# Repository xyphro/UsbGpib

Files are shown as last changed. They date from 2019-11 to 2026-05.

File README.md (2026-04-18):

# Table of contents

:newspaper: [Latest updates](Updates.md)
<br> :hammer: [Buy it or build it](#buy-it-or-build-it)
<br> :wave: [UsbGpib Introduction](#usbgpib-introduction)
<br> :house: [Housing / Enclosure](#housings)
<br> :computer: [Software](#software)
<br> &nbsp; &nbsp; :electric_plug: [Using the device](#using-the-device)
<br> &nbsp; &nbsp; :gear: [Setting and getting parameters](#setting-parameters)
<br> :heavy_check_mark: [Testing status](#testing-status)
<br> :notebook: [Tutorials](Tutorials/README.md) <- **New!**
<br> :heart: [Support the Project](#support-the-project)

# Summarized latest updates

For detailed visibility look under the Latest update link above!

[18th Apr 2026]: **Released Firmware V2.4: Added support for multiple GPIB devices**

[18th Apr 2026]: **Added some updated notes on GPIBee**

[07th Mar 2026]: **USbGpib V2 back in Stock on Elecrow**  

[07th Mar 2026]: **10 UsbGpib V3 == GPIBee prototypes ready for testing**

# Next version update USBGpib V3 

**UsbGpib V3 has a Name - Introducing GPIBee**

...and as you’ll see in the picture: The beauties are ready!

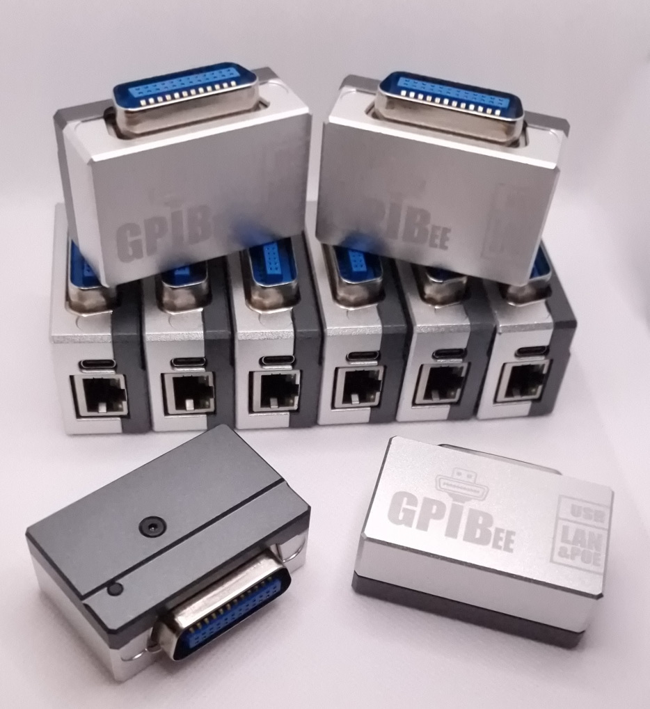
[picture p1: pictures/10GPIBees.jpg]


After months of development, redesigns, loosing hair on fixing SW bugs and teasing the new Ethernet + PoE capabilities, the next generation of UsbGpib finally has its official identity. From this point forward, UsbGpib V3 will be known as GPIBee - a compact, fast, and delightfully capable little worker that's ready to buzz around your lab equipment.

PoE is fully operational, VXI-11 supports multiple simultaneous connections, and USB High-Speed is performing flawlessly - on MY bench. Which does not mean (yet) on everybody elses bench. Testing is by multiple people is always very important!

I now have ten GPIBee prototypes fully assembled and sitting proudly on my desk. These units will soon head out to the first wave of beta testers who’ve been following the journey and are eager to put them through real‑world use.
I had hoped to start shipping next week, but with Embedded World taking up my entire schedule, distribution will begin shortly after I'm back. The excitement doesn't slow down - it just builds a little more.

Thank you all for the incredible support, feedback, and enthusiasm.

GPIBee is about to take its first flight, and you're part of the swarm that made it possible.
Stay tuned - beta testing starts soon, and the prototypes look fantastic.

## GPIBee update 18th April: 

The first prototypes have been shipped, and internal testing is already well advanced.  
Across all protocols, read performance shows a **3.5× to 5× speed increase**, and this is **without** any dedicated speed-optimization work applied yet.

## Communication Modes

### USB Interface

GPIBee supports three independent USB-based communication modes:

1. **Network mode**  
   GPIBee exposes a USB-based Ethernet interface. An IP address is assigned automatically, enabling true plug-and-play operation.  
   - Full **VXI-11** support  
   - Integrated **web server** providing configuration pages, a GPIB command console, and the complete manual matching the currently installed firmware  
   - Ideal for multi-device setups and remote control - it should be considered as the first Goto solution in terms of USB based modes.

2. **USBTMC mode**  
   Similar to **UsbGpib V2**, but extended with additional commands, including the ability to set the target **GPIB device address** — enabling communication with multiple GPIB instruments.

3. **++ protocol mode**  
   Exposes a **USB CDC UART** implementing the popular ++ protocol, compatible with existing controllers using that protocol — but at significantly higher speed.

The USB modes are **mutually exclusive**. The active mode can be selected via the **web interface** or through internal **SCPI commands**.

### Ethernet Interface

1. **VXI-11**  
   Provides multiple logical channels, allowing communication with several GPIB devices simultaneously without manually switching addresses between commands. 
   - Proper **lock handling** for multi-client access  
   - Full **SRQ** support  
   - Full **GPIB subaddressing** support

2. **++ protocol**  
   Optional **TCP/IP** service on port **1234**, offering the same `++` protocol implementation as in USB CDC UART mode.

Both Ethernet protocols can be **active at the same time**. The Ethernet interface also exposes the same **web interface** as USB network mode, enabling GPIB transfers, configuration changes, and access to the **firmware-synchronized manual**.

## GPIBee Beta Testing Status

The current beta focus remains on **functional correctness and stability**.  
**Speed optimization** will follow next.

For testers not having received an adapter yet: Additional prototype units will be shipped soon. Handling too many testers at once would otherwise become too **time-intensive**.

---

# Buy it or build it

* Tired of tinkering? Want to skip the hassle and get straight to using your GPIB setup?  
* You’d rather spend your time using your instruments instead of assembling hardware?

Skip the soldering iron and jump straight into your GPIB workflow!

You’ve got two solid options to get a ready‑to‑run UsbGpib adapter.

## &#x1f1fa;&#x1f1f8; - United States
* If you're in the US, you can now order the UsbGpibV2 directly from several sources, including my distribution partner Binho LLC. Enjoy fast domestic shipping with no long waits, no customs paperwork, and no surprises - just quick delivery and a smooth experience: 
<br> &#x1F449; <a href="https://binho.io/test-measurement/products/usbgpib-v2/" target="_blank">https://binho.io/test-measurement/products/usbgpib-v2/</a>
<br> &#x1F449; <a href="https://www.digikey.com/short/29nqq5cz" target="_blank"> https://www.digikey.com/short/29nqq5cz</a>
<br> &#x1F449; Amazon US also has it listed, but right now no stock, but worthwhile to check it out there too.

## &#x1F30E; - Worldwide
* I’ve teamed up with Elecrow to bring you ready-to-roll GPIB-USB converters – perfect for those who want results, not a weekend project.
* These adapters come fully assembled, programmed, housed, tested, and ready to go. No fuss. No build. Just plug it in and start working.
* The Adapters match 100% the V2 version described in this repository. 
* &#x1F449; <a href="https://www.elecrow.com/xyphrolabs-gpibusb.html" target="_blank">https://www.elecrow.com/xyphrolabs-gpibusb.html</a>

Let the data flow begin!

This doesn’t mean I’m going fully commercial - far from it.
Offering pre-built adapters is simply a convenience for those who’d rather skip the build and get straight to using their gear.

All sharing, support, and collaboration will remain fully open, just as before.
This is about choice, not change!

The full design files are located in this repository in case you want to build the devices yourself.

---

# UsbGpib Introduction
Versatile, cheap, portable and robust USB to GPIB converter (USBTMC class based).

You'll find many projects like this, but this one is special (ok, everybody will claim this) :-)

V1 Hardware: 
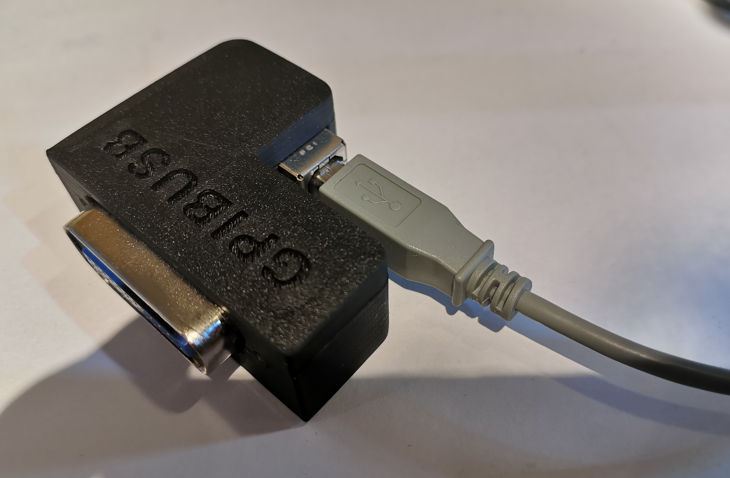
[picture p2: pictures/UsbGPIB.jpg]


V2 Hardware: 


If you have a lot of test equipment at home, you might know the issues: Lots of devices only have GPIB as interface and the GPIB adapters and GPIB cables on the market are very expensive and some of them even have many issues, when run under Windows 10 (device driver does not work). Or they e.g. are not able to be operated with VISA, because they are UART based, need special command sequences, ...

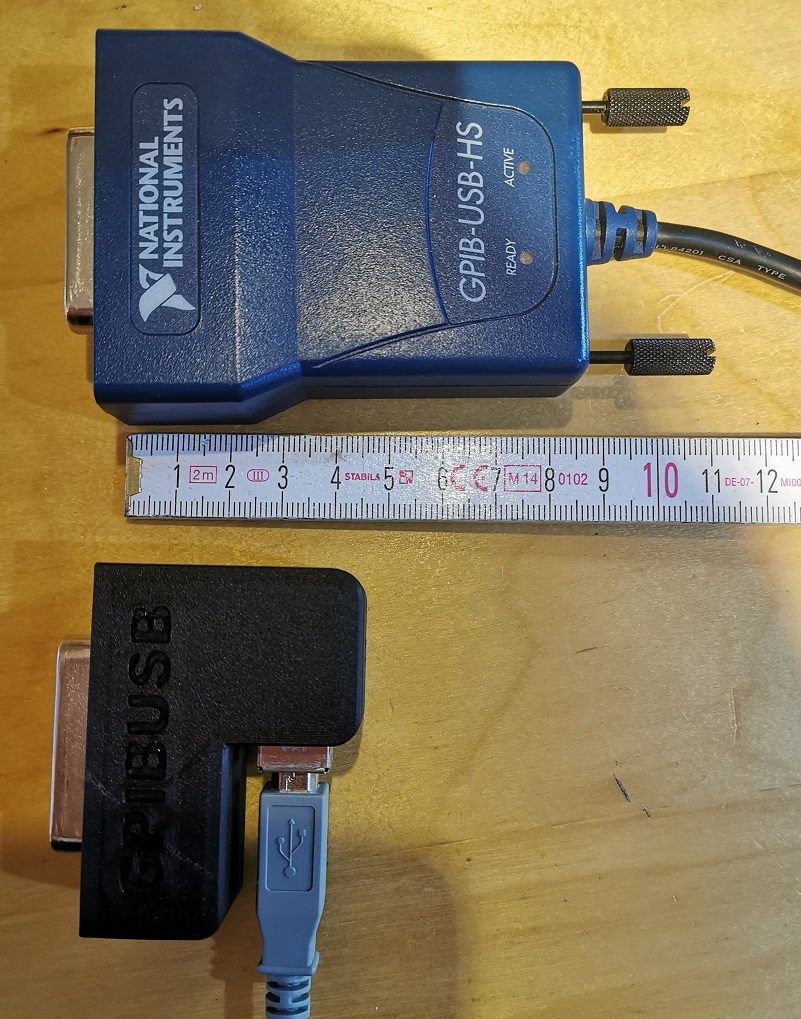
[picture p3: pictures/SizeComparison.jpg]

The adapters are also typically very long, such that they extend the overall length of your test equipment by at least 10cm (~4 inches).

Apart of the 2 very big manufacturers, other GPIB adapters, e.g. with Ethernet or also USB interface are not recognized by normal VISA providers or PyVisa, making the measurement control implementation specific for your GPIB adapter.

I've got frustrated and tried to turn it into something positive. Here a video showing the final device in action - click to view:

(https://www.youtube.com/watch?v=pZp1QZCXrF8) 

Some goals of the project were:
- Work based on the standard USBTMC protocol. This allows the GPIB test equipment to look like a normal USB based measurement device and work flawless with e.g. NI VISA, Labview, Matlab or PyVisa.
- Have a small length - otherwise my equipment has the risk of falling from the shelf :-) Also the USB cable should connect 90 degree angled, to make it very short. With V2 HW, the length got further reduced to the size of a GPIB connector.
- It should be cheap but still versatile (you can build a single one of these for only 14 USD!)
- It should support ALL my test equipment, from many different GPIB implementation generations and different GPIB flavors
- The Firmware should be upgradeable over USB
- It should be rock-solid (!) I don't want to end up in a very long measurement being interrupted because of a software issue of my USB GPIB converter.
- It should support additional features like serial poll, remote enabling/disabling
- If there is no GPIB device connected to the USBGpib converter, or the GPIB device is powered down, there should be no USB device visible on the PC.

All those goals are met.

---

# Hardware

## Microcontroller choice

Although I typically would prefer nowadays an ARM Cortex M0/3/4/7 controller, there is an issue with it. Available devices support only max. 3.3V supply voltages, such that there would be a requirement for a level-shifter towards the GPIB Bus.
GPIB is based on 5V (not exactly true, but a first iteration).

This limited the microcontroller choice to e.g. AVR or PIC controllers. Because of very good availability I ended up in ATMEGA32U4 controllers.
Apart of the device supporting 5V I/O voltages, it also does not require a regulator to be part of the application - it has an internal 3.3V regulator. This minimizes the full application schematic and BOM.

Apart from that, there is an excellent USB stack available [http://www.fourwalledcubicle.com/LUFA.php](http://www.fourwalledcubicle.com/LUFA.php).

The GPIB side of the schematic can be directly connected to the ATMega32U4 IO pins. The IO pins from the microcontroller side are only set to 2 different states: Tri-state (input) or output LOW, to talk over GPIB.

## Component sourcing

All components are easy to source, so I only specify the potential critical ones:

- 16 MHz Crystal: Farnell 2853867 - MCSJK-7E-16.00-8-30-100-B-30 
- REV 1 GPIB connector: Farnell 2421095 - NORCOMP 112-024-113R001. For REV 2 use a straight 24P male solder type connector e.g. from AliExpress.
- USB connector for V1 HW: Farnell 2668483 - Amphenol ICC 61729-1011BLF
- USB connector for V2 HW: Best is to look on AliExpress for 57 series 24P connector as a starting point.

## PCB

The PCB can be ordered at nearly any PCB pool production service (e.g. 10 PCBs for 2 USD + shipping). The gerber files are included in the "HW/Gerber files" subdirectory.

## Mounting the PCB & Flashing the firmware

The PCB is available in 2 revisions.
- [REV 1](HW/REV1/README.md) is the most popularly used right now due to age. It has a USB Type-B connector and an L-shaped housing visible on a few photos of this page.
- [REV 2](HW/REV2/README.md) has some improvements like being smaller, better fit and USB Type-C connector.
- A REV 3 is upcoming. It will be a major redesign with more speed, Ethernet and power over Ethernet support, but the same DNA: Standard protocols being used and ensure compatibility and stability!

Choose whatever you prefer. The software images, but also the external behavior is the same.

---

# Housings

## REV 1
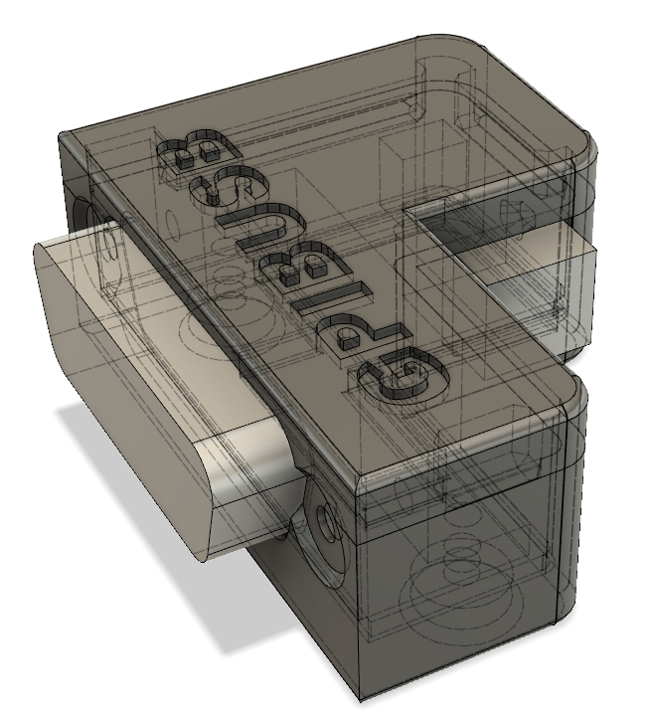
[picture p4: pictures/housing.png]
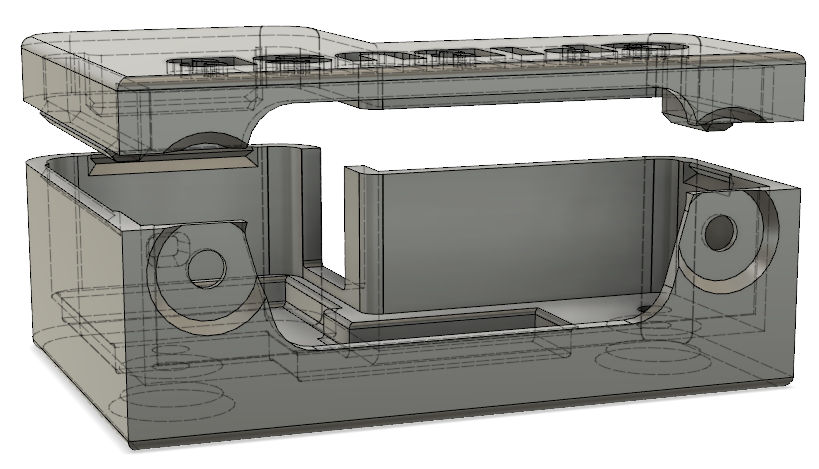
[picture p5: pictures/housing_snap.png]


I created a sophisticated 3D printable housing for this adapter. The design was made with Fusion 360. The project file + the STL files are included in the "Housing" sub directory.

The PCB fits perfectly into it. Optionally it can be fixed with 2 mounting screws (the GPIB connector has 2 threads, use 2 times 4-40 UNC x 3/8) and the TOP cover snaps onto the housing base.

I printed this using an Ender 5 3D printer with black PLA, 0.15mm layer height, 1mm wall thickness, no support.
Take care, that you rotate the TOP part of the housing by 180 degrees, so that the flat side is located on the printer bed.
Printing works fine, several iterations of the design were made to ensure good printability.
I printed so far 15 housings, without a single fail.

More information on this REV 1 can be found here: [REV 1](HW/REV1/README.md).
Note, that also the programming/build instructions moved to this location.

## REV 2



The REV 2 housing is a lot smaller, but requires 2 screws.
The housing is quite important to be able to connect and disconnect the board without breaking anything. It is key for mechanical stability of the adapter.
When operating the device without housing, take very well care when plugging in and out the board in case the GPIB connector has a very tight fit.

Information on how to build it can be found in the HW/REV 2 folder: [REV 2](HW/REV2/README.md).
Note, that also the programming/build instructions moved to this location.

---

# Software

## Source code

The source code of the Boot loader (slightly modified LUFA MassStorage Boot loader) and the main USBGPIB converter are located in the "SW" subdirectory.
At the time of publication LUFA 170418 release was used, with GCC as compiler.

Note: The Software is compatible with any HW revision in this repository. For REV 1 and REV 2 hardware you don't need different SW images.

## Binaries

For those, that just want to create their own device, I've included the binary output in the "SW/binaries" subdirectory.

---

# Using the device

## USB enumeration

You might be surprised initially, that the device does not show up in your device manager (or lsusb), when you connect only the USB side. This is a feature, not a bug (really!).
Only, if a GPIB device is connected, you can see the device on your PC too.

The reason behind the feature is simple: Instead of having a standard GPIB wiring, where you have a single GPIB controller and lots of GPIB devices interconnected, USBGPIB supports only a direct connection of the USBGPIB device to your measurement device. If you have like me e.g. 14 Instruments you don't want all to show up in the device manager, if the measurement device itself is powered down - you won't anyway be able to communicate with a powered down device.

When USB and the GPIB side is connected, the device enumerates. The USBGPIB device reads out the ID of the instrument and constructs a unique USB Serial number out of it. It is thus easily possible to assiate multiple connected USBGPIB devices with the measurement instrument.

The VISA ressource name is constructed from this USB Serial number. You can identify easily e.g. in NiMax, which device is connected:

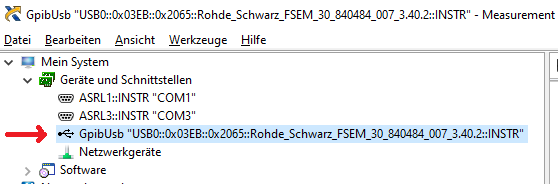
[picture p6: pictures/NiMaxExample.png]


If you connect your USBGPIB device afterwards to another GPIB measurement device, it will disconnect and connect with a new serial number string, matching the other GPIB device *IDN? response again.

## GPIB settings on your measurement device

GPIBUSB does probe all GPIB primary addresses (and secondary address 0) for presence of a GPIB Talker/listener. It is thus not required to set a specific GPIB address - GPIBUSB will find it itself.

The only importance setting on the measurement device is, that the GPIB interface is enabled, which is typically the case.

## LED indicator

The LED indicates different states:

LED blinking: The USBGPIB converter is connected to a measurement instrument, it is powered off or its GPIB port is disabled. In this state, the device is also not connected to USB and will not show up in the device manager or lsusb.
LED on: The device is connected to a measurement device and GPIB communication possible. It is also accessible over USB
LED off: The device is not connected over USB, or the PC powered off :-)

## Controlling GPIB devices
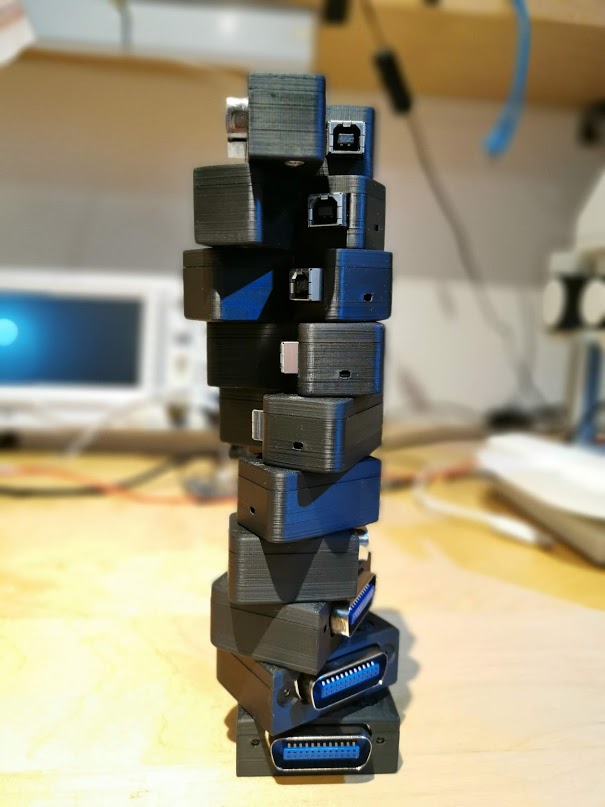
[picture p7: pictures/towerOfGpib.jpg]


As this converter implements the standard USBTMC Test and measurement class, you can control your instrument from ANY of the normal VISA tools. I tried so far R&S VISA and NI Visa, using Python and Matlab to talk to the devices.

# Testing status

This project is actively maintained since more than 6 years and I personally consider it as very stable. It is proven by multiple users to operate on MacOSX, Linux and Windows and measurement equipment from several decades.

In general I take bug reports very serious and want to "fix them all". In case you don't get an answer on-time on items you report in the issues section, please write me: Xyphro@gmail.com. 
I often miss seeing issue reports very quickly, as I don't get an email once they are filed.

## Sucessfully tested measurement equipment:

Below list is equipment I mainly myself tested. Many other users have other measurement equipment proven in use already.

- R&S FSEM30
- R&S SMIQ03
- R&S CMU200
- R&S SMW200A
- R&S FSW
- R&S FSV
- Keithley 199 multimeter
- HP 34401 DMM from different generations / with different FW versions
- HP 3325A synthesizer/frequency generator
- HP 3457A multimeter
- Agilent E4406A VSA transmitter tester
- Tektronix TDS7104 Digital Phosphor Oscilloscope
- HP 8596A spectrum analyzer
- Agilent E3648A dual power supply

## Scenarious

- It works under all popular operating systems like Windows 7 and 10, 11, Linux and MacOSX
- USB1.1, USB2.0 and USB3.x ports tested, with and without USB HUB in between.
- The connection stays responsive, when power cycling the PC, or hibernating/sleeping it
- Different connection cycles (GPIB side connected first, USB side connected first, swapping GPIB side equipment, ...)
- Extensive testing of timeout scenarious. E.g. making an illegal query and testing, if the USBTMC handles the timeouts properly. This was a very tricky part to get right.
- Tested special transfer modes. E.g. capturing screenshots from different equipment is usually something, which will drive other GPIB adapters to the limits, because binary data of unknown length needs to be transported successfully.

# Setting Parameters

The firmware version from 13th January 2024 onwards has the ability for human readable text base configuration of several parameters.
The previous methods are still supported, but won't be further documented. You can look them back in the history of this file.

The command parser is quite simple. For that reason follow the exact syntax as shown below. 
Don't add extra spaces or make other modifications or concatenate commands.

## Read termination method

While most GPIB interfaces use the hardware signal EOI to signal the end of a message, not all old equipment supports it. Some older instruments even don't have the EOI pin hardware wise wired and use \r or \n termination.

The USB-TMC standard allows to set the read termination. While in firmware versions before < 2.0 I did not enable that method, it is now finally supported with standard compliance.

I document here the older method (using pulse indicator request), but I add also the newer methods which are 100% UsbTmc compliant and portable across different equipments. You can choose which ones to use, but in some cases pulse indicator requests can be difficult to issue, for which reason it is likely better to use the standard compliant method.

### Set read termination to CR (\r):
(old method)
```
dev.control_in(0xa1, 0x40, 0, 0, 1); # USBTMC pulse indicator request (enables internal command processing)
dev.write('!term cr')
```
Above setting is volatile. To make this a permanent setting call the below mentioned "!term store" command.

(prefered method) Alternatively you can set the termination directly with visa means, e.g. using PyVisa:
```
dev.set_visa_attribute(visa.constants.VI_ATTR_TERMCHAR_EN, True)
dev.set_visa_attribute(visa.constants.VI_ATTR_TERMCHAR, ord('\r') )
```

### Set read termination to LF (\n):
(old method)
```
dev.control_in(0xa1, 0x40, 0, 0, 1); # USBTMC pulse indicator request (enables internal command processing)
dev.write('!term lf')
```
Above setting is volatile. To make this a permanent setting call the below mentioned "!term store" command.

(prefered method) Alternatively you can set the termination directly with visa means, e.g. using PyVisa:
```
dev.set_visa_attribute(visa.constants.VI_ATTR_TERMCHAR_EN, True)
dev.set_visa_attribute(visa.constants.VI_ATTR_TERMCHAR, ord('\n') )
```

### Set read termination to EOI only (default setting):
(old method) 
```
dev.control_in(0xa1, 0x40, 0, 0, 1); # USBTMC pulse indicator request (enables internal command processing)
dev.write('!term eoi')
```
Above setting is volatile. To make this a permanent setting call the below mentioned "!term store" command.

(prefered method) Alternatively you can set the termination directly with visa means, e.g. using PyVisa:
```
dev.set_visa_attribute(visa.constants.VI_ATTR_TERMCHAR_EN, False)
dev.set_visa_attribute(visa.constants.VI_ATTR_TERMCHAR, ord('\0') )
```

### Save readtermination setting in eeprom (make them non-volatile)
```
dev.control_in(0xa1, 0x40, 0, 0, 1); # USBTMC pulse indicator request (enables internal command processing)
dev.write('!term store')
```

Above relates to the "old non prefered method". In general it is a good idea to set the read termination volatile and use the above suggested methods highlighted with (prefered method).

### Query current termination setting from device
```
dev.control_in(0xa1, 0x40, 0, 0, 1); # USBTMC pulse indicator request (enables internal command processing)
print(dev.query('!term?'))
```
This returns a text string containing "lf", "cr" or "eoi"

## Multi-device support - Setting the GPIB device target address

Since Firmware version V2.4 USBGpib allows supporting multiple instruments.

While the USBTMC protocol allows only setting a single device to be addressed and composite USB devices are not well supported by all VISA implementations, I decided to add a command to set the address of the GPIB device which is addressed.

There is a minor limitation of this approach, which is that service request SRQ handling is only done properly to the currently selected GPIB device.
Another one is, that users shall never forget to set the GPIB address to the correct setting before issuing a command.

### Setting a primary address only

Substitute the text <Primary_address> with a number from 1 to 30 to set the primary address of the new GPIB device to talk to in following GPIB transactions

```
dev.control_in(0xa1, 0x40, 0, 0, 1);
dev.write('!addr <Primary_address>')
```

### Setting a primary + secondary address

Substitute the text <Primary_address> with a number from 1 to 30 to set the primary address and <Secondary_address> with a number from 0..6 or 96..102 of the new GPIB device to talk to in following GPIB transactions.
Note, that not the full subaddress range of 0..31 or 96..127 is supported as of now - this requires a bit more work. Most common device with subaddresses like R&S CMU200 only are well covered with that current range.

```
dev.control_in(0xa1, 0x40, 0, 0, 1);
dev.write('!addr <Primary_address> <Secondary_address>')
```
### Python wrapper example code for GPIB address setting

```
import pyvisa as visa
dev = 'USB0::0x03EB::0x2065::GPIB_22_14236333938351C00011::INSTR'
rm = visa.ResourceManager()
dev = rm.open_resource(dev, open_timeout=1000)

def set_gpib_addr(primary_address, secondary_address = None):
    dev.control_in(0xa1, 0x40, 0, 0, 1);
    if secondary_address is None:
        dev.write('!addr %d' % primary_address);
    else:
        dev.write('!addr %d %d' % (primary_address, secondary_address));
    
# Address CMU200, which is for me on primary address 1, secondary address 0
set_gpib_addr(1, 0)
print(dev.query('*IDN?'))

# address HP3457A on primary GPIB address 22
set_gpib_addr(22)
dev.write('END,ALWAYS')
print(dev.query('ID?'))
```

This code results in my current testsetup with CMU200 and HP3457A in this output:

```
Rohde&Schwarz,CMU 200-1100.0008.02,xxxxxx,V5.22

HP3457A
```

## AutoID setting

Default wise the GPIB adapter tries during power on of the instrument to query using *IDN? or ID? commands the instrument name automatically.
This is used to build the USB serial number, which finally gets part of the VISA ressource string.

Not all instruments support this *IDN / ID? query. For this reason this feature can be turned off.
The serial number will then be built based on the GPIB address of the instrument.

### Turn AutoID feature off
```
dev.control_in(0xa1, 0x40, 0, 0, 1); # USBTMC pulse indicator request (enables internal command processing)
dev.write('!autoid off')
```
This setting is stored in eeprom = non volatile memory, so will survive a power cycle

### Turn AutoID feature on
```
dev.control_in(0xa1, 0x40, 0, 0, 1); # USBTMC pulse indicator request (enables internal command processing)
dev.write('!autoid on')
```
This setting is stored in eeprom = non volatile memory, so will survive a power cycle

### turn auto ID on with delay

Some instruments need after turn on some seconds before GPIB is responsive.

With below 3 settings you can set a delay which is applied before the instrument ID is queried after power on.
Note that it will take then also more time, before the USB device is recognized by the PC.

Also this setting is non-volatile.

Delay 5 seconds:
```
dev.control_in(0xa1, 0x40, 0, 0, 1); # USBTMC pulse indicator request (enables internal command processing)
dev.write('!autoid slow')
```

Delay 15 seconds:
```
dev.control_in(0xa1, 0x40, 0, 0, 1); # USBTMC pulse indicator request (enables internal command processing)
dev.write('!autoid slower')
```

Delay 30 seconds:
```
dev.control_in(0xa1, 0x40, 0, 0, 1); # USBTMC pulse indicator request (enables internal command processing)
dev.write('!autoid slowest')
```

### read autoid setting

```
dev.control_in(0xa1, 0x40, 0, 0, 1); # 
print(dev.query('!autoid?'))
```
Returns as text string either: "off", "on", "slow", "slower" or "slowest".

## Firmware version

Finally I implemented a command to query the USB adapters firmware version :-)

```
dev.control_in(0xa1, 0x40, 0, 0, 1); # USBTMC pulse indicator request (enables internal command processing)
print(dev.query('!ver?'))
```

## Shorten ressource strings (Matlab)

A user discovered that Matlab has a limitation in the VISA ressource string length and shared a pull request to reduce the length.
I expose this now first time in the baseline firmware with the following options.

This setting is stored in eeprom = non volatile.

### Limit the USB serial number to a length of 20 characters
```
dev.control_in(0xa1, 0x40, 0, 0, 1); # USBTMC pulse indicator request (enables internal command processing)
dev.write('!string short')
```

### disable limitation of USB serial number length (default behavior)
```
dev.control_in(0xa1, 0x40, 0, 0, 1); # USBTMC pulse indicator request (enables internal command processing)
dev.write('!string normal')
```

### query the string length setting.
```
dev.control_in(0xa1, 0x40, 0, 0, 1); # USBTMC pulse indicator request (enables internal command processing)
print(dev.query('!string?'))
```

This returns as text string either "normal" or "short".

## reset the adapter
```
dev.control_in(0xa1, 0x40, 0, 0, 1); 
dev.write('!reset')
```

Do a reset of the adapter. Note that due to the reset you have to close the visa session and start a new one as the device re-enumerates on the USB.

---

# Support the project



Or support by buying a fully prebuilt adapter at: <a href="https://www.elecrow.com/xyphrolabs-gpibusb.html" target="_blank">https://www.elecrow.com/xyphrolabs-gpibusb.html</a>

In general any email, post or feedback is also very valuable, and don't feel bad if you don't use the support options :-)
Feel free to contact me at Xyphro@gmail.com

---

This page is from XyphroLabs UsbGpib project: <a href="https://github.com/xyphro/UsbGpib" target="_blank">https://github.com/xyphro/UsbGpib</a>

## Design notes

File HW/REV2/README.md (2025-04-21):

# xyphro UsbGpib HW REV 2

The new HW revision picks up some things that I and other misliked:
- The REV 1 HW - when put beeing assembled into its housing did have change to colide with parts of the instruments body. Especially for Keysight equipment. This new HW revision follows the formfactor of an original GPIB cable to get rid of this mechanical constraint.
- The REV 1 HW required to enter the bootloader with a tweezer. REV 2 has a button. Hold it a few seconds and the bootloader is entered.

The [software](../../SW) will always stay the same, no matter if REV1 or REV 2.

I have built many of those adapters myself so far and have developed trust in the design:
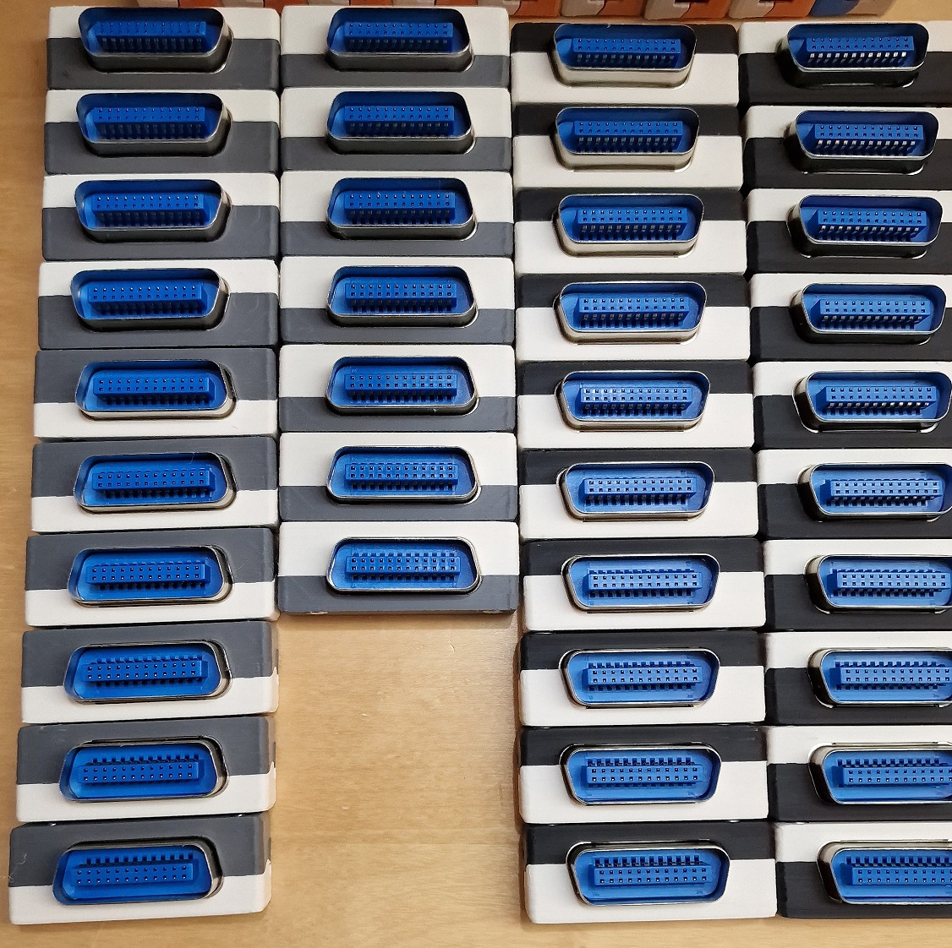
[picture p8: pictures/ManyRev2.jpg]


## Assembly process

All files related to HW are located in this folder. Gerber file, BOM, Kicad design files.

## preparing the PCB

Mount only the SMD components. This means: DON'T mount the GPIB connector yet.

On edge you can find a mounting point for a pinheader - 45 degrees angled. Mount 2-3 pin pinheaders here and you now have a 6 pin ISP programming port with standard pinout for your favorit AVR programmer.
Program the bootloader. Pin 1 is marked on the PCB to allow you connecting the ISP cable in the correct orientation.

### Flashing the Microcontroller first time

For initial programming an AVR ISP adapter is needed to program the "Bootloader.hex" file.

It is very important, that the Fuses of the AVR are programmed.

Here an example how to program the bootloader using avrdude (using usbasp programmer):
avrdude -c usbasp -p m32u4 -e -Ulock:w:0xFF:m -Uefuse:w:0xcb:m -Uhfuse:w:0xd8:m -Ulfuse:w:0xde:m

avrdude -c usbasp -p m32u4 -U flash:w:BootLoader.hex

To program bootloader and application image at the same time using AvrDude, you can use this command:
..\avrdude -c usbasp -p m32u4 -e -Ulock:w:0x3F:m -Uefuse:w:0xcb:m -Uhfuse:w:0xd8:m -Ulfuse:w:0xde:m -U flash:w:TestAndMeasurement.hex -U flash:w:BootLoader.hex

Note, that some programmers use a quite high clock frequency on the programming interface. In case of failures try to decrease the SCK clock frequency!

After programming the file, disconnect and connect the device and a USB drive will show up. Copy the TestAndMeasurement.bin file to this USB drive - ideally using the command line. Example: `copy TestAndMeasurement.bin F:\FLASH.BIN`.
On Linux, there is a bug with the LUFA mass storage that means it is required to use `dd if=TestAndMeasurement.bin of=/mnt/FLASH.BIN bs=512 conv=notrunc oflag=direct,sync`.

When done, disconnect USB.

It is now safe to desolder the ISP pinheaders such that the PCB fits into the housing. 
Any further update can happen over USB using the bootloader.

## Building the whole thing together
Preparation:
- Mount the PCB EXCLUDING the GPIB connector.
- Print the housings located in [this folder](../../Housing/Rev2). I print them using 1mm bottom/top/wall thickness, 0.16mm layer height and 30% infil. On my K1 printer it takes 23 minutes to print, on my Ender 5 2.2 hours.
- get 2 20mm M3 screws and 2 M3 nuts
- get a GPIB connector "24P Male solder type" from e.g. Aliexpress

If you have everything in place and prepared, insert the PCB including the GPIB connector (unsoldered!) into the bigger part of the housing:

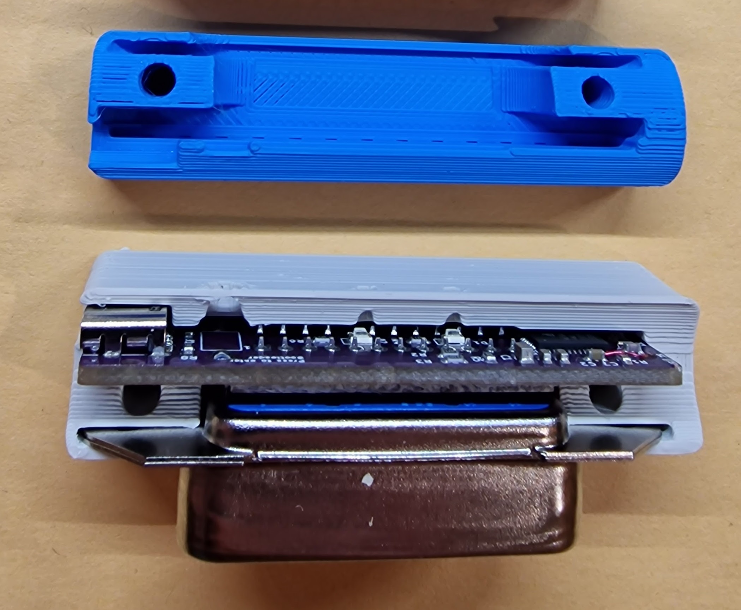
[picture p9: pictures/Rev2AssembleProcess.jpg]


Then solder 2 pins of the GPIB connector and take the PCB out of the housing again to solder all pins.
(This step is required to ensure that the GPIB connector has the right distance to the PCB and fit into the housing)

As a next step insert the PCB into the big part of the housing again. It has a relatively tight fit - to ensure mechanic stability.

Then put the smaller part of the housing on top of it, insert the screws (they can be pushed hard to destroy the "membrane" first time) and nuts and screw it together.

Voilà.. your adapter is finished and ready to use :-)



# Updating the firmware at later stages

To enter the boot loader at later stages for updates, press the button (bigger hole in the housing) using a pen/paperclip for about 3 seconds. Then a USB mass storage (flash drive) enumerates on the PC where the firmware image can be copied too (see previous chapter).

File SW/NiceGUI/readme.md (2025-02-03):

# UsbGpib Python configuration scripts.

These scripts were contributed by [Jim Houston](https://github.com/jimthouston).

The usbgpib_conf.py script is a simple command line interface to
set the UsbGpib parameters.  The usbgpib_gui.py is a [NiceGUI](https://nicegui.io/) based
GUI to do the same thing.
These have been tested with Ubuntu 24.04.  

The other dependency is the [Python USBTMC library](https://github.com/python-ivi/python-usbtmc).  
This library was choosen over pyvisa because it has the pulse command (control_in) which is not implemented in the pyvisa-py backend.
I (jim) believe that both of these packages have support for Windows and MacOS but I have only tested on Linux.

NiceGUI uses the web browser as the frontend for the GUI.  Running the
usbgpib_gui.py script will launch the browser and run the GUI.
Here is a screenshot running in this mode.

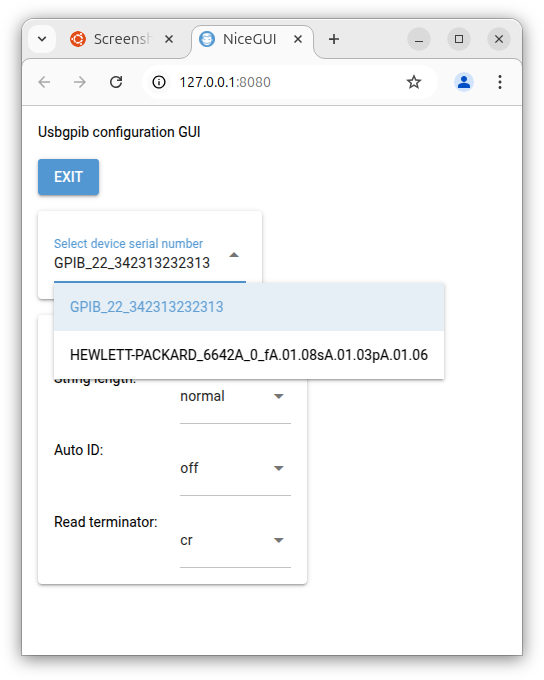
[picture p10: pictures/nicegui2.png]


# Setup

To use Python-USBTMC on Linux you need to create a udev rule to create
the device files e.g. `/dev/usbtmc1`.

Add the file `/etc/udev/rules.d/9-usbtmc.rules`:
```
SUBSYSTEM=="usb", ATTR{idVendor}=="03eb", ATTR{idProduct}=="2065", MODE="0660", GROUP="plugdev"
KERNEL=="usbtmc*", MODE="0660", GROUP="plugdev"
```

This allows members of the plugdev group to access the UsbGpib.

Here is the minimum setup needed to run the GUI installing into
a Python virtual environment:

```
python3 -m venv venv
source venv/bin/activate
pip3 install nicegui
pip3 install python-usbtmc pyusb
```

This installs the python packages in the sub-directory venv.  The
activate selects this environment.  To run the GUI use the command 
python3 usbgpib_gui.py`.

# Setup for Native mode.

NiceGUI also has the option to use pywebview to display the GUI in a native window.  To use this mode requires a more complicated set of dependencies.  Here is the setup which worked on Ubuntu 24.04.

```
python3 -m venv venv
source venv/bin/activate
pip3 install python-usbtmc pyusb
pip3 install nicegui pywebview qtpy pyqt5 PyQtWebEngine
sudo apt install python3-gi python3-gi-cairo gir1.2-gtk-3.0 gir1.2-webkit2-4.1
sudo apt-get install ^libxcb.*-dev libx11-xcb-dev libglu1-mesa-dev libxrender-dev libxi-dev libxkbcommon-dev libxkbcommon-x11-dev
```
To use native mode you need to edit the script.  The last two lines of the script are calls to ui.run().  Uncomment the either line to select the mode.
Running the script with native mode selected gives a window like this:

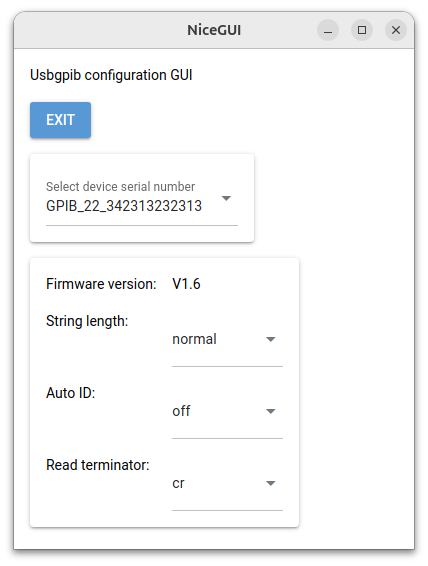
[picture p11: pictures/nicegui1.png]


# usbgpib_conf.py

This command line script only requires Python-USBTMC.  
Here is sample output displaying the configuration and setting a termination
parameter:
```
(venv) jhouston@T5610:~/UsbGpib_new$ python3 usbgpib_conf.py
UsbGpib config for GPIB_22_342313232313
!autoid? off
!term? cr
!string? normal
!ver? V1.6
UsbGpib config for HEWLETT-PACKARD_6642A_0_fA.01.08sA.01.03pA.01.06
!autoid? on
!term? eoi
!string? normal
!ver? V1.8
(venv) jhouston@T5610:~/UsbGpib_new$ python3 usbgpib_conf.py -s GPIB_22_342313232313 term eol
!term eol
```

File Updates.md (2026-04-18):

This new file will in future contain all updates. The latest updates are always on top.

# Recent Updates

## 18th April 2026

USBGpib has now support to address multiple GPIB devices with the newly added firmware version V2.4.

Similar to some UART based GPIB controllers a command is added to set the GPIB address of the device to talk to.

Look for "Multi‑device support" in [README.md](README.md) for more details and instructions.

## Multi-device support - Setting the GPIB device target address

## 07th March 2026

Chinese New year struck in and just shortly before it UsbGPIB V2 ran out of stock. Fortunately it is now back in stock and ready to order again!

## 04th February 2026

The PDF manuals are now also available in Markdown, generated automatically from the same source as the PDF document. This makes the documentation easier to browse, diff, and maintain in version control, while ensuring both formats stay perfectly in sync. -> See [Tutorials](Tutorials/README.md) section.

Furthermore I am releasing Firmware version V2.3. 
Changes:
- It turned out that Keysight Visa in certain versions can crash when a USBTMC device has a serialnumber with double underscore characters. Note, that the USBTMC standard does not disallow for double underscores. The AutoID function can return double underscores for some instruments - illegal characters returned by *IDN? query get replaced by underscores, so with 2 illegal characters you get double underscores as serial number = visa ressource name. I've now included a filter now to suppress double underscores when autoid is enabled.
- I've fixed Issues #96 and #97 reported by user thewon86. Those were USBTMC protocol issues which were never uncovered or effects seen so far, however the implementation was indeed incorrect here.

I updated also slightly the V3 announcement in the main README.MD. Basically: Firmware is ready for betatesting, Hardware arriving soon and gets distributed immediately once it arrives (@Betatesters: You'll get mail before shipping)!

My US distribution partner <a href="https://binho.io/" target="_blank">binho</a> also added UsbGPIB directly to their webshop (<a href="https://binho.io/test-measurement/products/usbgpib-v2/" target="_blank">https://binho.io/test-measurement/products/usbgpib-v2/</a>). This is ideal for US-market: Devices ship directly from San Francisco and are available for a good price! Checkout also their offerings on Host adapters and PCBite!

## 30th December 2025

Updated the "Buy it or build it section" and added a Digikey US link for buying the adapter.

## 30th November 2025

**Just released a new firmware after testing - version 2.2.**

Changes:
* Read termination related:
  * When the "USBTMC native" method to set the termination was once enabled, disabling it did not have effect anymore - it stayed enabled. Only power cycling got it out of that enabled state. Fixed and tested now.
  * Only \n \r and EOI only were supported read terminations. However, as reported in <a href="https://github.com/xyphro/UsbGpib/issues/85" target="_blank">issue 85</a>, there is quite a number of measurement equipment which requires e.g. ETX (0x03) read termination.  
  I removed now this artificial limitation for read termination, such that any read termination character can be set. From 0x00 to 0xff all codes are supported now.  
  For the eeprom non-volatile based method only \r \n and eoi only options are available and there is no plan to extend it to any termination character as this eeprom based method will also get retired for the upcoming V3 UsbGpib adapter.
* GotoLocal synchronization. USBTMC uses 2 different transfer methods for transfering certain types of messages. Control transfers and Bulk transfers. When e.g. sending a USBTMC command like Reading data which uses Bulk transfers followed by another one like GotoLocal which uses control transfers it is important that they also get executed in that order.   
This is something I took deep care off already since long time for other other control transfers, however as it turned out never tested for GoToLocal.   
And things that are not tested don't work, right?   
Michael discovered this during porting of his <a href="https://github.com/VK2BEA/HP8753-Companion" target="_blank">HP8753-Companion</a> to support the UsbGpib V2 adapter which led to me releasing V2.1 to him a while ago.

The issue is fixed now and confirmed working. This V2.2 includes the 2 additional improvements now.

Next release is planned to cover some good improvements I got suggested on AutoID handling.

## 23rd November 2025

I just finalized a user manual for the UsbGPIB V2 adapter, checkout [Tutorials](Tutorials/README.md) section.

In case you miss certain aspects and want me to add them, let me know (Discussion section, Issue section or email to xyphro@gmail.com)

## From Bench to Ready: Buy It, Plug It, Use It!

Tired of tinkering? Want to skip the hassle and get straight to using your GPIB setup?
* I’ve teamed up with Elecrow to bring you ready-to-roll GPIB-USB converters – perfect for those who want results, not a weekend project.
* These adapters come fully assembled, programmed, housed, tested, and ready to go. No fuss. No build. Just plug it in and start working.
* The Adapters match 100% the V2 version described in this repository. 

**Grab yours now:** <a href="https://www.elecrow.com/xyphrolabs-gpibusb.html" target="_blank">https://www.elecrow.com/xyphrolabs-gpibusb.html</a>

Let the data flow begin!

This doesn’t mean I’m going fully commercial - far from it.
Offering pre-built adapters is simply a convenience for those who’d rather skip the build and get straight to using their gear.

All sharing, support, and collaboration will remain fully open, just as before.
This is about choice, not change!

## Coming soon: Native Linux-Gpib support
<small>(Or actually: It's already there!)</small>

A contact with the Linux-Gpib maintainer resulted in a great cooperation with good outcome. We managed to jointly get native linux-gpib support up and alive. Thanks a lot for that, Dave!

We’ve successfully brought full Linux-GPIB compatibility to life. To enable it, you’ll need to flash a dedicated firmware image:  
- File "LinuxGpib.bin" in sub-folder [LinuxGpib firmware](SW/binaries/) will enable it from firmware perspective. Note: This will make the adapter stop from enumerating as normal usbtmc device (you can reflash the normal firmware again later if you like). The upcoming adapter announced a few days ago will have a combined firmware, but the flash of AtMega32U4 was simply "too full".

Stay tuned — I’ll be publishing a detailed guide soon, covering setup instructions and the powerful benefits of going native on Linux.

Just to avoid misunderstandings: The Adapter always worked under Linux as normal UsbTmc device as it does on any other operating system, but was not supported by the Linux-GPIB library so far. So software packages using linux-GPIB can be used without modification in future.

Would btw. love to get similar integration also in Visa Libraries - let's see what time will bring :-)

## Update on Beta Tester program on new upcoming "V3" Adapter with Ethernet+PoE + High speed USB

I managed to find a decent amount of betatesters for the new upcoming HW. Much more as the originally anticipated 3 persons. Thanks a lot for all who volunteered! 

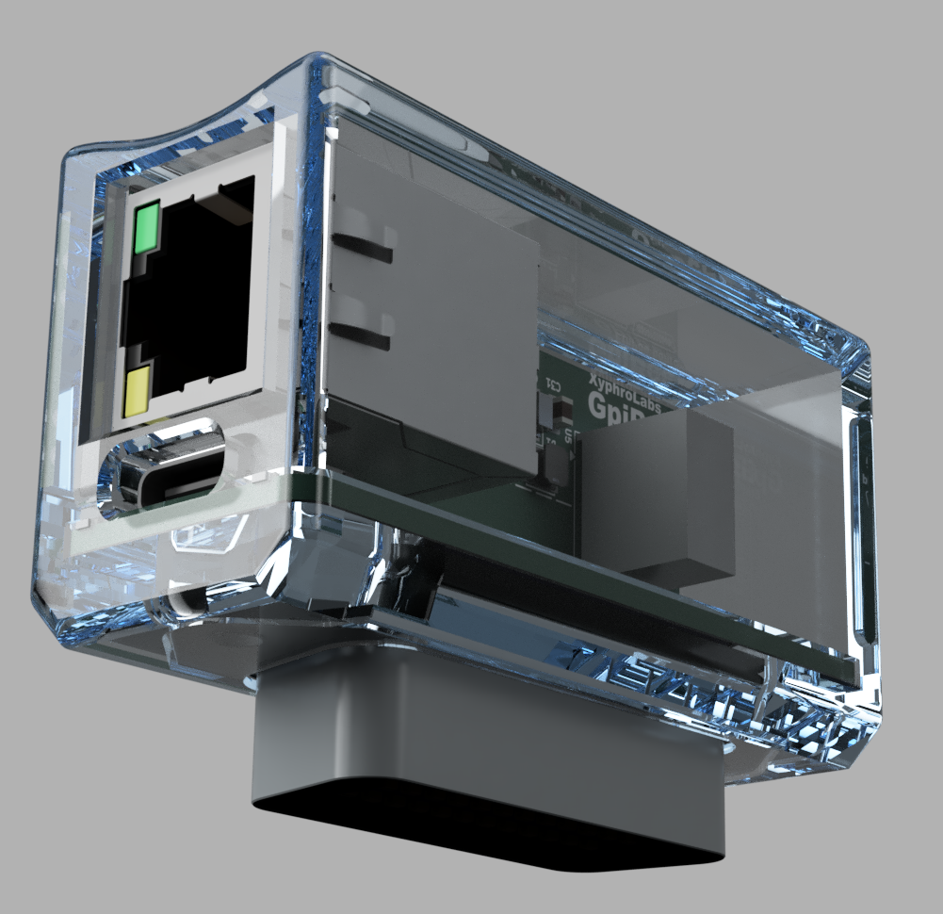
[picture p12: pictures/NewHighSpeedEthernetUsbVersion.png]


<small>Status: From the HW side the Ethernet and PoE section is tested successfully. USB was already enabled since long time.
SW side: The USB functionality is fully implemented and first stress testing shows positive results with no lockups. The Ethernet stack is up and running too, but further implementation and testing work is still to be done.</small>

# 21st April '25 update

Today it's time for another release - version V2.0. 

While writing this and looking at this readme.md file, I certainly think that I should clean it up in future - it is not well structured for new users. Sorry for this, but I have this on my radar and will improve. Whenever I have more time I will also extend it with usage examples / small "trainings", especially for those who are completely new to GPIB and controlling instruments.

I had btw. some occasions where users had issues flashing the device. Many of them were caused by the fact that the .hex and .bin files were saved over the GitHub web interface by rightclicking and selecting "Save as". This will result in a HTML page being saved which will not flash well :-)
The safest option is to do a git clone or to download this whole github repository as .zip file.

Here the release V2.0 details:
- **Bugfix:** the options autoid slower and autoid slowest did not work. This is addressed and I test those settings now also properly in release testing, promised :-) The issue was caused in my super slim parser implementation for custom internal commands and "autoid slow" and "autoid slower" start with the same letters causing hickups.
The Windows GUI is also updated to expose those 2 autoid settings - they were not included before.
As general good recommendation, I still recommend to turn autoid feature off, as it limits the measurement instruments which are used - Instruments HAVE to support *IDN? query for it to work well, which is for many old equipment not the case and for such old equipment errors will be flagged after the instrument is turned on.
- **New feature:** I enabled a new method to set the READ termination. One that is fully compliant with usbtmc standard and does not need a workaround with pulse indicator requests. I don't know why I did not spot this earlier, but a discussion with the usbtmc linux kernel mode driver maintainer exposed this to me. When using direct access to usbtmc kernel mode driver you can use the <a href="https://github.com/dpenkler/linux-usbtmc?tab=readme-ov-file#ioctl-to-control-setting-eom-bit" target="_blank">USBTMC_IOCTL_EOM_ENABLE</a> IOCTL to set the read termination. When using a VISA layer, you can set the read termination by setting the VI_ATTR_TERMCHAR_EN and VI_ATTR_TERMCHAR attributes (see below for more details). 
The previous method of setting read termination is not modified in any way, this just gives an additional method to set the readtermination.
- **Bugfix / Improvement:** The pulse indicator request function did use a blocking delay to pulse the LED. This delayed USB side handling. In some cases this could trigger timeouts. The LED blinking is now handled fully asynchronous and those timeouts will not occur anymore.

# 6th April '25 update

Time to release a bugfix (reported by rapgenic #80): V1.9 of the firmware fixes an issue where the "autoid slow" setting was not applied properly.

# 12th January '25 update

## New Gui available! (Windows)

I implemented a small GUI to change the non-volatile settings of the GpibUSB adapter. Sorry - it's windows only :-)
It is a single .exe file without external dependencies. You can just download it, run it and immediately change settings.

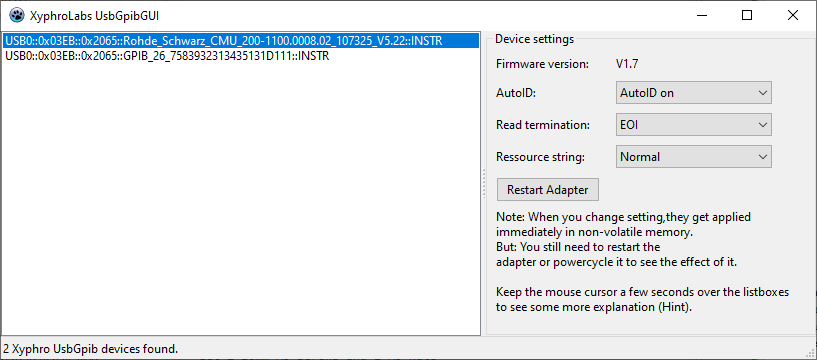
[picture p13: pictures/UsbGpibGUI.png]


Please download it from this folder: [SW/UsbGpibGUI](SW/UsbGpibGUI)

The source code is included in the src sub-directory.

## Python GUI (Linux)

UsbGpib user Jim Houston created an impressive pure Python GUI similar to mine - and I believe he began working on it even before I released mine. His GUI stands out for its versatility and platform independence, requiring only Python to run. It can be executed directly with Python 3 and should run on most platforms.

For details about it, have a look into this discussion thread: [https://github.com/xyphro/UsbGpib/discussions/55](https://github.com/xyphro/UsbGpib/discussions/55)

The GUI can be found here including documentation: [SW/NiceGUI](SW/NiceGUI)

## New Firmware

I release also herewith Version 1.8 of the firmware. 
Mainly a bug-fix was done, that the string setting now also returns short, when it is actually set to short. (issue report #59).

# 13th January '24 update

New year, new update :-)

I realized a user suggestion, which is a better human readable interface to the internal instrument settings.
This also exposes new functionality, e.g. shortening of the visa resource string, adjustable delayed application of AutoID featured, ...
The read termination setting can now be set in a volatile way and also be read back.

A slight issue sneaked in also and got fixed: After an instrument clear the next GPIB transfer timed out. Nobody found it so far though :-) But I fixed it.

Have fun using this!
(would anybody volunteers to make a simple cross platform gui for the non volatile settings :-) ?)

# 19th December '23 update

Finally I made it - the new HW design is on this page. As I had to restructure the repository a bit it took quite a while.
The software image is always the same and runs on both HW revisions.



I also have put a binary for a new Firmware image in there. I am still busy optimizing certain things but want to give you a try before doing a next release.
Please if you test it: Feed it back to me - does it work / does it break anything -> sharing is caring. 

Mail me at xyphro@gmail.com or raise an issue under the issue section.

[FW image location: SW/binaries](SW/binaries)

- 488.2 support further rolled out. This means Status bytes are automatically read out and reported via interrupt transfers to PC as foreseen in the standard.
- FASTER (!) 7 x write speed improvement and 4.x times read speed improvement. As reference: On an FSW I get 310kBytes/s as write transfer speed and 240kBytes/s as read transfer speed.
- a fix for read status byte readout leading to issues on my CMU200
- several smaller race conditions identified and fixed. A lot of work went into stress testing 488.2.

As said, I feel this is the best Firmware image so far, but I changed so much that I want to go first for this small beta test phase asking you explicitly for positive and negative feedback.

---

This page is from XyphroLabs UsbGpib project: <a href="https://github.com/xyphro/UsbGpib" target="_blank">https://github.com/xyphro/UsbGpib</a>

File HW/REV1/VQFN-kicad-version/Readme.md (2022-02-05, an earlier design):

# About

These files are a reimplementation of the original PCB using the VQFN-44 packaged ATMEGA32U4 part.  This was ``inspired'' by the fact that during the 2021 chip shortage the TQFP part was hard to come by.

# Notes and Differences

- The board layout is new, but the outline was made to match the original, as were the USB and GPIB port placements, so it should be compatible with the case still.
- The layout was done in KiCAD.  The included files are in **KiCAD version 6**.  As of this writing 6.0 has just been released so most users don't have it.  However it will play nice with KiCAD 5 if you already have that installed, ie you can have them both installed without extra work.  KiCAD 6 was used because the new file format keeps symbols embedded making it easier to share.
- The component part numbers may be different.  This was done to enable fabrication by JLCPCB.  Functionally they should be the same.  It should be compatible with the same USB and GPIB part numbers.
- The component designators should all be the same, at least for the passive components.
- The LED is now on the back side to eliminate the need for any front side components (excluding the through hole connectors).  A second LED footprint was added in parallel with the first and labeled D2.  It can be optionally populated (I recommend removing D1) if top side LED placement is desired.  On the schematic and BOM I also raised the resistor value because the original one same low, but feel free to pick whatever you like during assembly.
- The GPIB part has incorrect pin numberings but the connections are right.  Don't get distressed if the schematic has funny pin numberings, You can blame mouser or whoever they partner with for footprints.

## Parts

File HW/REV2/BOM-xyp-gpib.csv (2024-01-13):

Comment | Designator | Footprint | LCSC
ATmega32U4-MU | U1 | QFN-44-1EP_7x7mm_P0.5mm_EP5.2x5.2mm | C112161
SW_Push | SW1 | SW_Tactile_SPST_NO_Straight_CK_PTS636Sx25SMTRLFS | C118141
100nF | C2,C3,C4 | C_0603_1608Metric | C14663
1u | C7 | C_0603_1608Metric | C15849
8pF | C5,C6 | C_0603_1608Metric | C1647
4.7uF | C1 | C_0805_2012Metric | C1779
470R | R4,R6 | R_0603_1608Metric | C23179
5k1 | R7,R8 | R_0603_1608Metric | C23186
22R | R2,R3 | R_0603_1608Metric | C23345
100k | R5 | R_0603_1608Metric | C25803
10k | R1 | R_0603_1608Metric | C25804
CX2016DB16000D0WZRC1 | Y1 | Crystal_SMD_2016-4Pin_2.0x1.6mm | C2682780
USB_C_Receptacle_USB2.0 | J1 | USB_C_Receptacle_XKB_U262-16XN-4BVC11 | C2936185
LED | D1,D2 | LED_0805_2012Metric | C84256

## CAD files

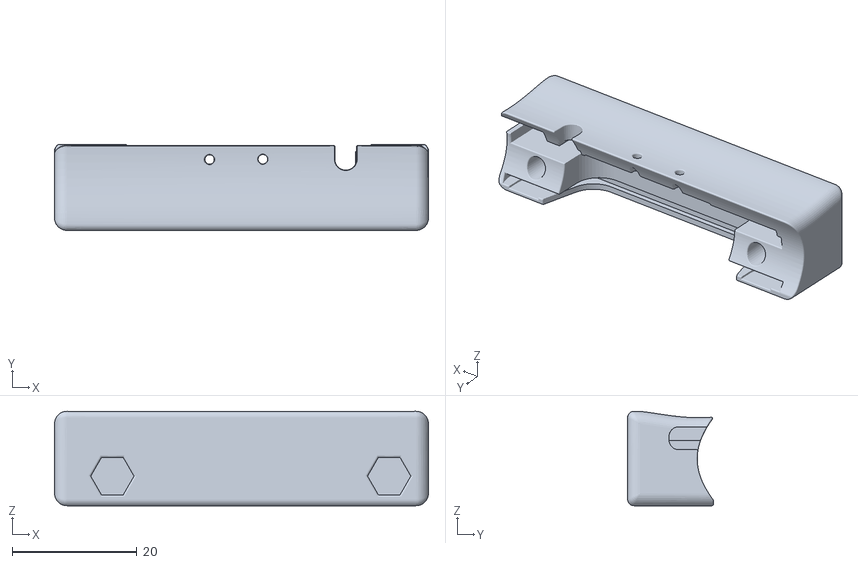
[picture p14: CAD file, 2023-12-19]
Housing/REV2/XyphroUsbGpibRev2_housing_part2.stl
59.9 x 13.7 x 15.1

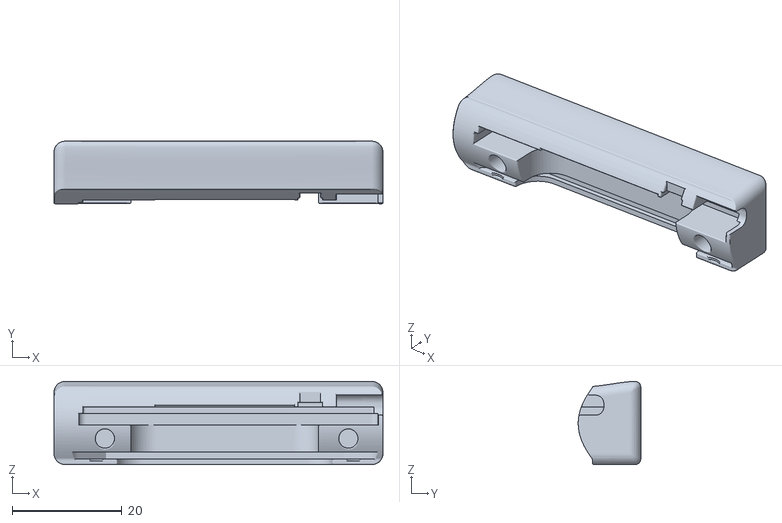
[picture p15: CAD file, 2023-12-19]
Housing/REV2/XyphroUsbGpibRev2_housing_part1.stl
59.9 x 11.4 x 15.1

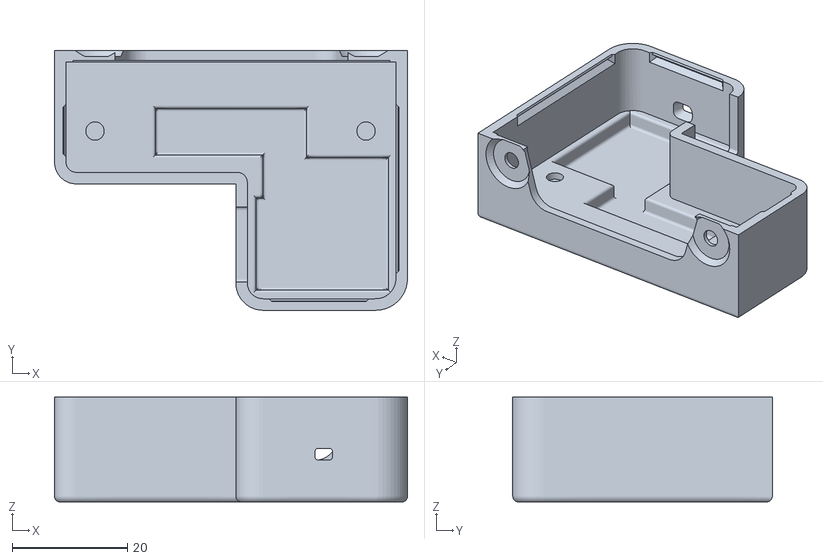
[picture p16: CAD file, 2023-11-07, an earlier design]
Housing/REV1/gipbusb_bot.stl
61.2 x 45.0 x 18.2

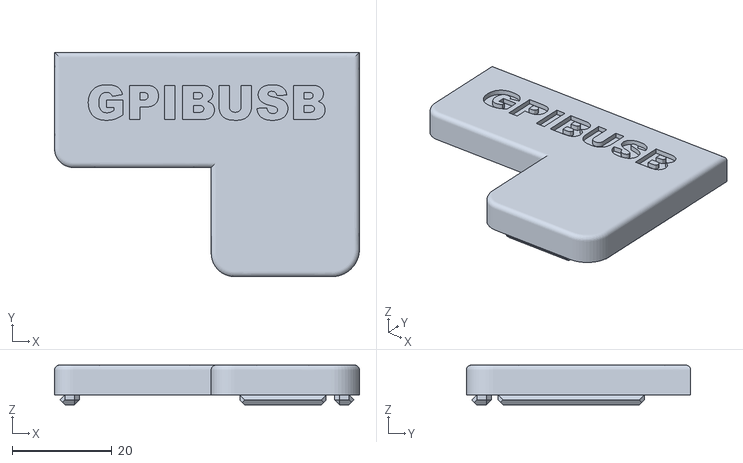
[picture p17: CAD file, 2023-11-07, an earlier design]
Housing/REV1/gipbusb_top.stl
61.2 x 45.0 x 8.00

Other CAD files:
Housing/REV1/USBGpibHousing.f3d

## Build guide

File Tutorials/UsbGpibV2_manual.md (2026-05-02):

- [XyphroLabs UsbGpib V2 User
  Manual](#xyphrolabs-usbgpib-v2-user-manual)
- [Introduction](#introduction)
- [Advantages of UsbGpib V2 adapter](#advantages-of-usbgpib-v2-adapter)
- [Safety Precautions](#safety-precautions)
  - [Operating Conditions](#operating-conditions)
  - [Storage Conditions](#storage-conditions)
  - [Moisture & Contaminants](#moisture-contaminants)
  - [Electric Safety](#electric-safety)
  - [Handling & Installation](#handling-installation)
- [Overview](#overview)
- [LED](#led)
- [Using the adapter](#using-the-adapter)
- [Firmware update procedure](#firmware-update-procedure)
- [Technical specifications](#technical-specifications)
- [Frequently Asked Questions](#frequently-asked-questions)
- [References](#references)

# XyphroLabs UsbGpib V2 User Manual

Last Update: 1st February 2026  
This document is part of [Xyphro
UsbGpib](https://github.com/xyphro/UsbGpib) project

Prefer PDF? Click here:
[](UsbGpibV2_manual.pdf)  
Note: Click on the download RAW button on top right when viewing the PDF
online.

# Introduction

The UsbGpib V2 is a compact, high-performance USB-to-GPIB adapter
engineered from the ground up for seamless integration with modern and
legacy test equipment.

Unlike clone devices, UsbGpib V2 delivers robust IEEE-488.1 and
IEEE-488.2 compatibility, stable USBTMC operation, and a unique device
identifier that ensures consistent VISA resource naming across systems -
eliminating the need for manual remapping or COM port assignments.

Designed to match the physical footprint and cable path of traditional
GPIB connectors, the adapter fits into all existing lab setups while
offering significant advantages in space efficiency, cable management,
and cross-platform support. Whether you’re automating instrument control
on Windows, macOS, Linux, or FreeBSD, UsbGpib V2 provides plug-and-play
reliability without proprietary drivers.

With firmware upgradability, protocol-aware communication, and a focus
on user-friendly integration, UsbGpib V2 is the ideal choice for
engineers, researchers, and developers seeking a dependable GPIB
interface that just works.

# Advantages of UsbGpib V2 adapter

- Modern Connectivity: Bridges USB and IEEE 488 (GPIB) with full USBTMC
  protocol compliance

- Slim Design: Minimal depth of just 1.5cm allows instruments to be
  placed closer to walls or rack panels

- Cable Efficiency: Uses thin USB cables instead of bulky "garden hose"
  GPIB cables, reducing clutter and improving portability

- Multi Adapter Support: Unique identifier per unit enables multiple
  adapters to be connected and operated reliably on the same PC

- No COM Ports: Avoids serial port mapping issues; Each adapter is
  consistently accessible with the same name across multiple PCs

- Transparent Operation: Plug into your instruments GPIB port and it
  behaves like a modern USB measurement device, including proper USB
  port deactivation when the instrument is powered off

- Controller Role: Optimized as a dedicated GPIB controller for one
  instrument per adapter, ensuring robust one to one communication and
  optimized cable management.

- Standards Compliance: Implements full IEEE-488.1 IEEE 488.2 controller
  support via USBTMC, including status byte reading, triggering, service
  requests, and termination settings

- Software Compatibility: Works seamlessly with all standard VISA
  providers (NI VISA, Rohde & Schwarz VISA, Keysight VISA)

- Tool Integration: Fully compatible with LabVIEW, MATLAB, PyVISA, and
  PyVISA py for established and modern automation workflows

- Cross Platform Support: Operation across Windows, macOS, FreeBSD, and
  Linux

- German Engineering: Designed and developed in Germany over six years,
  extensively tested for robustness and compatibility with instruments
  from new to decades old

- Reliability: Built to ensure long automated measurement sequences
  complete without interruption

- Future Proof: Firmware is field upgradable and actively maintained,
  providing ongoing improvements and compatibility updates

# Safety Precautions

To ensure reliable operation and long-term durability of the UsbGpib V2
adapter, please observe the following environmental and handling
Guidelines

## Operating Conditions

| | |
|:---|:---|
| Temperature Range: | 0°C to +50°C |
| Humidity: | 10% to 90% RH, non-condensing |
| Altitude: | Up to 2000m above sea level |

## Storage Conditions

| | |
|:---|:---|
| Temperature Range: | -20°C to +70°C |
| Humidity: | 5% to 95% RH, non-condensing |

## Moisture & Contaminants

- Avoid exposure to liquids, vapors or corrosive substances

- Do not operate in environments with condensation, high dust levels or
  chemical fumes

## Electric Safety

- Do not expose to voltage levels above 6V

- Do not short circuit or connect to non IEEE488 / non-USB compliant
  ports

- Ensure proper grounding of connected instruments

## Handling & Installation

- Do not bend or stress the USB or GPIB connectors during installation

- Avoid excessive force when plugging/unplugging

- Avoid direct sunlight

- Keep away from electrostatic discharge (ESD) sources; use ESD-safe
  handling procedures

# Overview

<table>
<tbody>
<tr>
<td style="text-align: left;"><br />
</td>
<td style="text-align: left;">(1) GPIB connector - Plugs directly into
your measurement equipments GPIB port.</td>
</tr>
<tr>
<td style="text-align: left;"><br />
</td>
<td style="text-align: left;">(2) Status LED<br />
(3) Firmware update button</td>
</tr>
<tr>
<td style="text-align: left;"><br />
</td>
<td style="text-align: left;">(4) USB-Type C connector - plug it with
either a USB Type C to USB type A or USB type C to type C cable into
your PC.</td>
</tr>
</tbody>
</table>

# LED

The LED has multiple purposes as summarized in the table below.

<table>
<tbody>
<tr>
<td style="text-align: left;"><br />
</td>
<td style="text-align: left;">The Adapter is connected to a USB port,
but no GPIB device is found. Connect a GPIB measurement device to the
GPIB port and ensure that GPIB is enabled in the instrument.</td>
</tr>
<tr>
<td style="text-align: left;"><br />
</td>
<td style="text-align: left;">The GPIB device was identified, but no
GPIB communication is executed from PC.</td>
</tr>
<tr>
<td style="text-align: left;"><br />
</td>
<td style="text-align: left;">Every time GPIB data is transferred from
the PC or to the PC, the LED will be turned off for short periods of
time. This indicates data exchange = activity.</td>
</tr>
<tr>
<td style="text-align: left;"><br />
</td>
<td style="text-align: left;">The USB port is not connected to the PC,
the PC powered off or the USB cable defect.</td>
</tr>
</tbody>
</table>

# Using the adapter

To use the adapter, connect the USB-C connector with a USB cable to a
PC.

The GPIB connector can be plugged directly into the measurement
instrument, which you want to control. It can also connect via a GPIB
cable if required due to setup constraints.

When the measurement equipment is turned on and if the GPIB port is
enabled in the instrument, the adapter will enumerate on the PC as
USBTMC class device.

Operating system specific instructions & tutorials are available under
this link:

<https://github.com/xyphro/UsbGpib/blob/master/Tutorials/README.md>

Those tutorials explain how to ensure that a USB driver is installed and
guide through the first setup up to the point where you can talk with
the instrument.

<div class="tcolorbox">

Note: The UsbGpib Adapter does not enumerate on the PC, if it is not
connected to a GPIB measurement device, which is powered and GPIB
enabled.

</div>

# Firmware update procedure

The UsbGpib V2 adapter comes preinstalled with a firmware. But as the
firmware is actively maintained you might want to update the adapters
firmware sooner or later. The UsbGpib V2 adapter allows for firmware
updates. It requires the bootloader mode to be entered, followed by
programming the firmware and power cycling the adapter.

Firmware images are distributed via GitHub:

<https://github.com/xyphro/UsbGpib/tree/master/SW/binaries>

to download, left-click on "TestAndMeasurement.bin" file. After the new
page loads, click on the RAW button on the top right side:



After downloading the file, rename it to FLASH.BIN. Ensure to use
capital letters for the full filename during rename. Filenames with
lowercase letters like "Flash.bin", "flash.bin", "FLASH.bin" will result
in the firmware update procedure not to work (but it won’t break the
adapter).

After downloading the file, enter the bootloader:

- Connect the adapter to a PC via USB. The GPIB side can be left
  unconnected.

- Hold the button (3) down for a few seconds (use e.g. a pencil to push
  it), until the PC recognizes a memory stick device (USB flash or mass
  storage device).

A new drive appears on the PC:



Then open a command line and enter a command like the following:

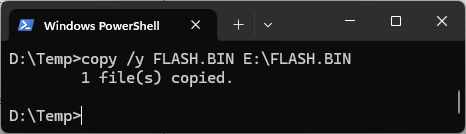
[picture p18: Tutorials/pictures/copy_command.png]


<div class="tcolorbox">

On Linux, use this command to transfer a firmware update, instead of
using cp:
`dd if=TestAndMeasurement.bin of=/mnt/FLASH.BIN bs=512 conv=notrunc oflag=direct,sync`

</div>

Adjust the file paths and drive letters to your actual system. When no
error is shown, you can unplug USB (and GPIB) and reconnect to power
cycle the adapter and use the new firmware.

<div class="tcolorbox">

Note: Drag and drop operation e.g. from Windows explorer does will work.
Ensure you use the command line method as described.

</div>

# Technical specifications

<table>
<thead>
<tr>
<th style="text-align: left;"><strong>Item</strong></th>
<th style="text-align: left;"><strong>Specification</strong></th>
</tr>
</thead>
<tbody>
<tr>
<td style="text-align: left;">USB power requirements</td>
<td style="text-align: left;"><ul>
<li><p>5V supply voltage nominal</p></li>
<li><p>Valid supply voltage range: 4.5V to 5.5V</p></li>
<li><p>100mA current consumption</p></li>
</ul></td>
</tr>
<tr>
<td style="text-align: left;">USB standard</td>
<td style="text-align: left;"><ul>
<li><p>USB 1.1, USB 2.0, USB 3 and higher are supported with full speed
mode</p></li>
</ul></td>
</tr>
<tr>
<td style="text-align: left;"></td>
<td style="text-align: left;"></td>
</tr>
<tr>
<td style="text-align: left;">USB connector</td>
<td style="text-align: left;"><ul>
<li><p>USB Type-C connector</p></li>
<li><p>Compatible with USB-A by using a USB Type C to USB Type A
cable</p></li>
<li><p>Compatible with USB Type C to USB Type C cable.</p></li>
</ul></td>
</tr>
<tr>
<td style="text-align: left;">Supported IEEE-488 features</td>
<td style="text-align: left;"><ul>
<li><p>IEEE-488.1, IEEE-488.2, HPIB, GPIB compatible</p></li>
<li><p>Service request (reported using interrupt transfers)</p></li>
<li><p>Device Clearing</p></li>
<li><p>Trigger</p></li>
<li><p>Status Byte read</p></li>
<li><p>GPIB write, read and queries<br />
(supports talker only, listener only and talker+listener
instruments)</p></li>
<li><p>Full timeout support for reliable operation</p></li>
<li><p>All GPIB features are exposed using the exact USBTMC equivalents
for good compatibility</p></li>
</ul></td>
</tr>
<tr>
<td style="text-align: left;">Supported IEEE-488 device roles</td>
<td style="text-align: left;"><ul>
<li><p>Controller</p></li>
</ul></td>
</tr>
<tr>
<td style="text-align: left;">Operating Systems</td>
<td style="text-align: left;"><ul>
<li><p>Windows</p></li>
<li><p>Linux, FreeBSD</p></li>
<li><p>Mac-OS</p></li>
</ul></td>
</tr>
<tr>
<td style="text-align: left;">Dimensions</td>
<td style="text-align: left;"><ul>
<li><p>Excluding GPIB connector:<br />
  60mm x 23mm x 15mm (Width x Height x Depth)</p></li>
<li><p>Including GPIB connector:<br />
  60mm x 23mm x 22mm (Width x Height x Depth)</p></li>
</ul></td>
</tr>
<tr>
<td style="text-align: left;">Weight</td>
<td style="text-align: left;"><ul>
<li><p> 30g</p></li>
</ul></td>
</tr>
</tbody>
</table>

# Frequently Asked Questions

**Why doesn’t the adapter show up on my PC when I plug it in?**  
This is a feature called "Ghost Mode." The adapter only enumerates
(becomes visible) on the PC if it is connected to a GPIB instrument that
is powered on. This reduces device manager clutter when you have
multiple adapters connected to instruments that are currently off.

The reason for this feature is to make an instrument behave like one
with native USB interface and avoid seeing adapters on the PC with that
you can’t communicate anyway as there is no measurement equipment
connected.

------------------------------------------------------------------------

**What is the AutoID feature of UsbGpib V2?**  
AutoID is a feature where the adapter automatically queries the
instrument for its identity (using \*IDN?) and uses that information to
create a unique VISA resource name. For very old instruments that do not
support \*IDN?, this feature should be disabled to avoid errors. When
Auto ID is off, the Visa ressource name is constructed out of the GPIB
address of the instrument and a unique serial number of the GPIB
adapter.

------------------------------------------------------------------------

**What are the AutoID timing options?**  
When the AutoID feature is enabled there are different delay options.
This delay specifies how long the adapter waits after instrument turnon
before executing the \*IDN? query for the AutoID feature. While 5s works
for each instrument, some instruments require a setting to higher number
which is exposed by the other AutoID settings. AutoID is a non-volatile
setting which is permanently stored in the MCUs eeprom. **UsbGpibGui**:

- **AutoID ON:** The adapter waits 5 seconds after detecting a powered
  GPIB instrument before performing the identification scan `*IDN?`.

- **AutoID SLOW:** Increases the initial waiting period to 15 seconds
  before the scan begins.

- **AutoID SLOWEST:** Designed for instruments with very long boot
  sequences, this setting waits 30 seconds before attempting to
  communicate on the GPIB side.

- **AutoID OFF:** Disables the automatic identification query entirely.
  This is essential for older, non-SCPI instruments that do not support
  the `*IDN?` query and might return errors or lock up if they receive
  it.

**Tip:** Turn AutoID OFF for older non SCPI compliant instruments to
avoid that they start up with an Error. To change the AutoID settings
you can use e.g. the UsbGpibGui in the UsbGpib SW folder for Windows or
NiceGui for Linux. Note that UsbGpib GUI requires a Visa installation.

------------------------------------------------------------------------

**How do I set Read Termination?**  
It is best to use standard VISA attributes:

- Set `VI_ATTR_TERMCHAR_EN` to 1.

- Set `VI_ATTR_TERMCHAR` to `0x0A` (or any other ASCII character).

With firmware version $`\ge`$ 2.2 you can set any read termination
character you like, from ASCII code 0 to 255. This enables instruments
to react on EOT, CR, LF or any other character like e.g. ’,’ for easier
parsing of input data. Independent of the set termination character
setting the instrument will always react on the GPIB EOI as termination
of a read query.

When read termination is turned off, the read termination is EOI only.

------------------------------------------------------------------------

**Is the UsbGpib adapter a clone of an existing commercial adapter?**  
No. This is a common and important misconception. The UsbGpib adapter is
a completely original, open-source hardware and software project and
does not copy commercial adapters. It works for that reasons without
risk of getting blocked or locked out in future.

- **Unique Identity:** Unlike the many inexpensive adapters found on
  online marketplaces, this is **not** a counterfeit clone of National
  Instruments (NI), Keysight or other hardware.

- **Safe to Use:** Because it is not a clone, it is safe from "driver
  sabotage." Vendor software updates (like those from NI-VISA) often
  detect and disable counterfeit hardware; since this adapter uses its
  own independent firmware and identity, it remains fully functional and
  stable regardless of official driver updates.

- **Standard Compliance:** Instead of mimicking a proprietary device, it
  implements the standard **USBTMC-USB488.2** protocol. This allows it
  to "nicely integrate" into any VISA environment by following industry
  standards rather than exploiting a specific manufacturer’s driver.

In short: It is an independent, professional-grade tool designed to
coexist peacefully within the ecosystem of your choice.

------------------------------------------------------------------------

**Does it support Service Requests (SRQ)?**  
Yes, the adapter actively pushes SRQ signaling to the PC via an
interrupt pipe, as mandated by the USBTMC 488.2 standard. This means
your software does not need to poll for status continuously.

------------------------------------------------------------------------

**Can I use it with Linux?**  
Yes, it can be used either as a standard USBTMC device or through
Linux-GPIB for advanced features like controlling multiple instruments
with a single adapter. In case you want to use Linux-GPIB, have a look
here and search for "xyphro" for further instructions:
[<https://linux-gpib.sourceforge.io/doc_html/supported-hardware.html>](https://linux-gpib.sourceforge.io/doc_html/supported-hardware.html)  

------------------------------------------------------------------------

**Do I really need to use a VISA library?**  
Technically, no-but it is highly recommended. Because the adapter
follows the standard **USBTMC** protocol, it is natively recognized by
modern operating systems. Visa, while it seems like an "old-school
concept" is a quite convinient tool to enable access to instruments over
multiple different interfaces with a common interface.

I started e.g. by controlling only USBTMC instruments and made a
dedicated solution for that without visa, but when I later wanted to
control GPIB instruments and Ethernet based instruments in the same
setup, that "island solution" concept breaked and I started looking
seriously into Visa and saw the clear benefits. Don’t get shocked by
Gigabytes of Visa installation - there are smaller Visas available like
e.g. R&S Visa. Lean and mean and available for Mac OS, Windows, Linux
and even Raspberry PI with the same application level interface across
those operating systems. You also get a very stable tested solution for
your instrument access and can focus on the real measurement task.

- **With VISA:** Libraries like *R&S VISA* or *NI-VISA* provide a
  unified API. This is the most stable path for tools like LabVIEW or
  standard `PyVISA`.

- **Linux native:** You can interact directly with the kernel driver via
  `/dev/usbtmcX`. For advanced users, *Linux-GPIB* also supports the
  adapter via a dedicated firmware variant.

- **python-usbtmc:** A great alternative if you want to avoid a VISA
  installation entirely. It is a bit more "hands-on" (manual
  configuration), but it supports the full command set of the adapter
  more reliably than PyVISA-py in many cases.

- **PyVISA-py:** A "VISA-free" Python backend. While popular, it
  currently has an incomplete USBTMC implementation (e.g., issues with
  version queries). Basic instrument communication works, but it may
  require workarounds for advanced features.

**Recommendation:** Use **R&S VISA** for a lightweight, professional
setup, or the **python-usbtmc** package if you strictly require a
driverless Python environment.

------------------------------------------------------------------------

**Can the CMU200 which uses GPIB subaddressing be used with this
adapter?**  
Yes, the CMU200 is supported and used too by me. USbGpib exposes the
first subaddresses which gives access to most features.

Also other devices with GPIB subaddressing are supported. UsbGpib will
always expose the firstly found subaddress over USBTMC.

------------------------------------------------------------------------

# References

<table>
<thead>
<tr>
<th colspan="2" style="text-align: center;"></th>
</tr>
</thead>
<tbody>
<tr>
<td style="text-align: left;">Issue reports and support</td>
<td style="text-align: left;"><span><a
href="https://github.com/xyphro/UsbGpib/issues"><span
class="uri">https://github.com/xyphro/UsbGpib/issues</span></a></span></td>
</tr>
<tr>
<td style="text-align: left;">Technical support and feature
requests</td>
<td style="text-align: left;"><span><a
href="mailto:xyphro@gmail.com"><span
class="uri">xyphro@gmail.com</span></a></span></td>
</tr>
<tr>
<td style="text-align: left;">Firmware download</td>
<td style="text-align: left;"><span><a
href="https://github.com/xyphro/UsbGpib/blob/master/SW/binaries/TestAndMeasurement.bin"><span
class="uri">https://github.com/xyphro/UsbGpib/blob/master/SW/binaries/TestAndMeasurement.bin</span></a></span></td>
</tr>
<tr>
<td style="text-align: left;">Tutorials</td>
<td style="text-align: left;"><span><a
href="https://github.com/xyphro/UsbGpib/blob/master/Tutorials/README.md"><span
class="uri">https://github.com/xyphro/UsbGpib/blob/master/Tutorials/README.md</span></a></span></td>
</tr>
</tbody>
</table>

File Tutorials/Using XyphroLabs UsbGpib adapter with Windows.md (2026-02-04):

- [XyphroLabs UsbGpib V2 Windows + Visa
  Guide](#xyphrolabs-usbgpib-v2-windows-visa-guide)
- [Introduction](#introduction)
- [SW setup](#sw-setup)
  - [Installation of R&S Visa](#installation-of-rs-visa)
  - [Python setup](#python-setup)
- [HW Setup](#hw-setup)
- [First interaction with the
  instrument](#first-interaction-with-the-instrument)
  - [Confirming that the USB device is
    detected](#confirming-that-the-usb-device-is-detected)
  - [Testing if the instrument is detected by R&S
    Visa](#testing-if-the-instrument-is-detected-by-rs-visa)
- [Usage with Python](#usage-with-python)
  - [Scanning for connected devices](#scanning-for-connected-devices)
  - [Some more pyvisa Hints](#some-more-pyvisa-hints)
    - [Stripping of read termination](#stripping-of-read-termination)
    - [Automatic write Termination
      addition](#automatic-write-termination-addition)
    - [Timeout handling](#timeout-handling)

# XyphroLabs UsbGpib V2 Windows + Visa Guide

**XyphroLabs UsbGpib V2**

Last Update: 2nd February 2026 This document is part of [Xyphro
UsbGpib](https://github.com/xyphro/UsbGpib) project

Prefer PDF? Click here:
[](Using%20XyphroLabs%20UsbGpib%20adapter%20with%20Windows.pdf)

# Introduction

This document offers instructions for using the UsbGpib adapter with
Windows environments, particularly when integrating with Python.

Although the UsbGpib Adapter functions like other USBTMC instruments by
presenting a standard UsbTmc interface, these guidelines are primarily
aimed at assisting users who are new to instrument control, providing
them with an effective starting point for configuration and utilization.

On Windows platforms, there 2 popular methods for interfacing with
USBTMC instruments: One utilizes LibUsb in conjunction with PyVisa-Py,
while the other employs the conventional approach of using a VISA tool.
Given the complexities that can arise during LibUsb installation, it is
advisable to proceed with a standard VISA provider.

Leading VISA tools are offered by National Instruments, Key-sight, and
Tektronix. However, these solutions often require significant disk
space. In contrast, the R&S VISA package is notably compact - requiring
less than 100 MB - enabling swift installation without compromising on
performance or compatibility. Many alternative Visa tools include
superfluous components and may require over 1 GByte of storage space in
addition to extended download times.

This document details the process for installing R&S VISA and PyVisa,
guiding users through to the initial stages of communicating with an
instrument using Python.

# SW setup

## Installation of R&S Visa

Download R&S Visa from the R&S Page:
<https://www.rohde-schwarz.com/us/driver-pages/remote-control/3-visa-and-tools_231388.html?change_c=true>

In case that link does not work at time of reading, search the web with
"R&S Visa Windows download".

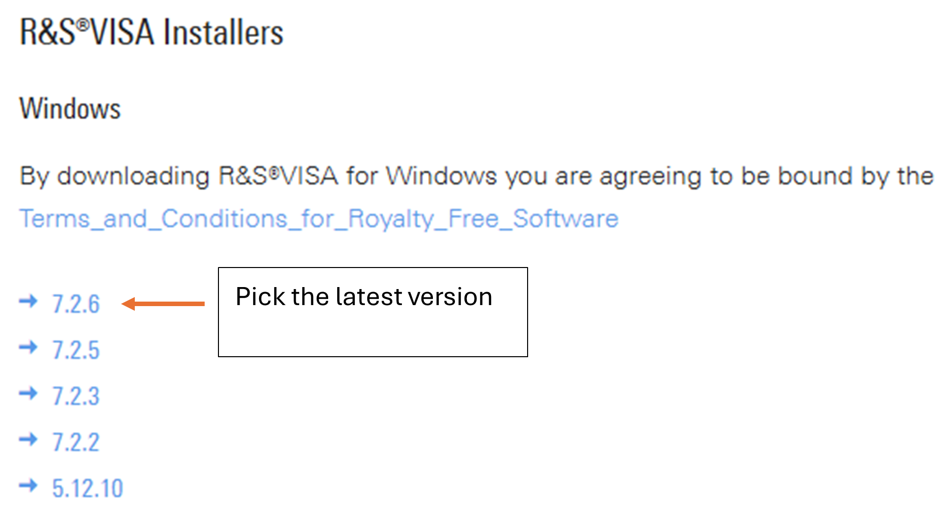
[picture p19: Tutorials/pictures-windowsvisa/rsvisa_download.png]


DoubleClick the downloaded file to start installation.



Please select the necessary components. For this guide, the primary
requirement is the R&S VISA for Developer 64/32-Bit. If you also plan to
use VISA with .NET applications in the future, it may be beneficial to
include that component as well. However, for Python-specific usage, this
selection is not required.

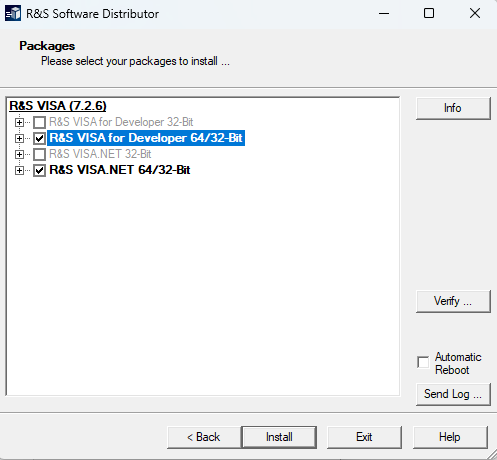
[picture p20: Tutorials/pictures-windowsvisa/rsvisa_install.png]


After selecting, click Install.

The R&S Visa installation also installs the USB driver for the UsbGpib
adapter.

## Python setup

For accessing R&S Visa using Python you need to install pyvisa.
Depending on your Python environment that can be done with Anaconda or
Pip. When you use pip, you can just type "`pip install pyvisa`" in a
command window. In case you have multiple python installations, ensure
you do that for the one that you also use later. When using Spyder as
python IDE, you can also type that command directly into the python
Console:



After the HW setup we will come back to python and some basic first
steps in using it.

# HW Setup

In this example I use a HP3457A Multimeter with GPIB:

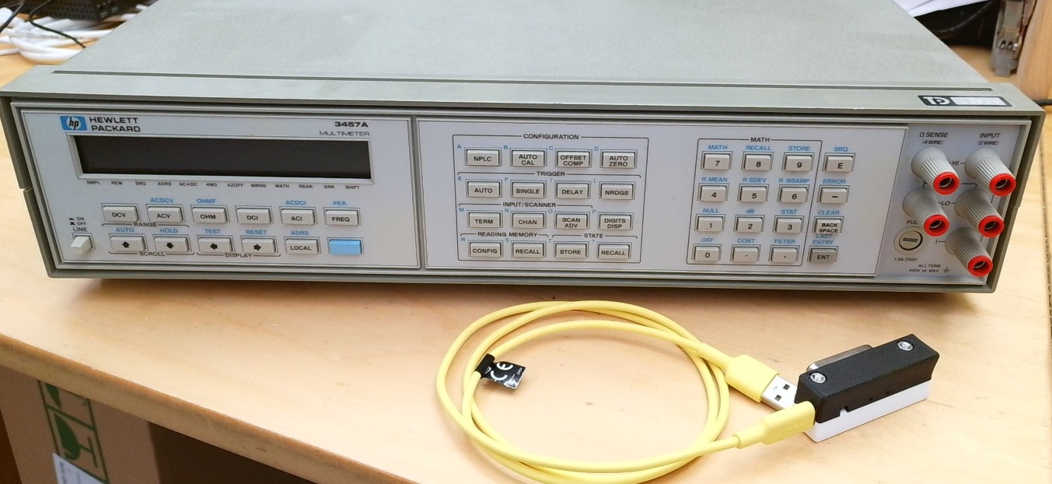
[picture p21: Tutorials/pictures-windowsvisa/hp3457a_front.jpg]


Initial one-time steps:

- Connect it to power but keep it powered off.

- Connect the USB GPIB converter to the GPIB port and the USB cable to
  your PC.  
  Note: The PC won’t detect a USB device yet as the instrument is
  powered off. This is a feature to prevent inaccessible devices are
  showing up on your PC.  
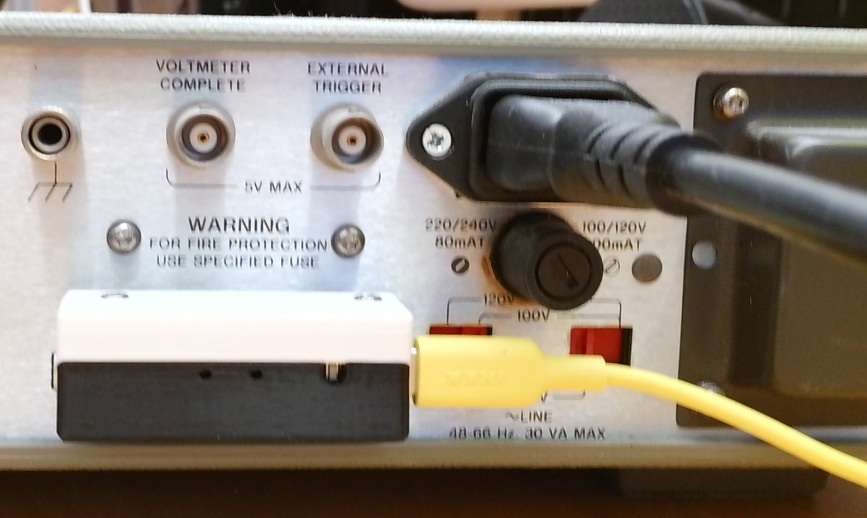
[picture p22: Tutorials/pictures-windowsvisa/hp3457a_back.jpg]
  

- Power on the GPIB device.  
  Note: The PC does now detect a new USB Device.

It is not necessary to follow a specific sequence for connecting or
disconnecting devices, powering them up or down, and similar actions.
However, the following order is provided to present the instructions in
a logical, step-by-step manner. As indicated in the procedure, the
adapter will only be detected by a PC when the instrument is powered on
and GPIB functionality is enabled. The adapter monitors USB connections
to identify whether any devices with GPIB enabled are present.
Regardless of the specific GPIB address, it systematically scans all
available addresses on its GPIB port. Upon detecting a responsive GPIB
address, the adapter enumerates the device on the USB interface, thereby
enabling access from the PC.

# First interaction with the instrument

## Confirming that the USB device is detected

You can check in the Device manager to confirm if the instrument was
found and the driver (which got installed by the R&S Visa installation)
is found.



When double-clicking that item and selecting Details you can check if
this is the Adapter and also see the serial number:



The serial number is different for each device. It is constructed out of
the detected GPIB address of the connected GPIB instrument (here
GPIB_22) followed by a unique ID which is different for each adapter.
That allows to use same GPIB addresses for multiple instruments, without
them disturbing each other.

## Testing if the instrument is detected by R&S Visa

Start the RsVisa Tester application:



After starting the below GUI window is shown:



While the interface may appear complex to first-time users, it contains
numerous standard features that help in initial instrument communication
and debug. To verify detection of the GPIB instrument, select "Find
Resource" in the upper left corner.

A new window opens:



Select the green-highlighted button to initiate an instrument scan.

If the operation is successful, a USB device should be visible as shown.
Please note that the previously displayed serial number forms part of
the resource string.



Select the found devices and click OK.

Now you are back to the main window. The resource field should show the
previously detected device:



Now you can click on the connect button to connect to the instrument.
The log lines should show a successful connection:



The right side of the main GUI window now gives the ability to interact
with the instrument:

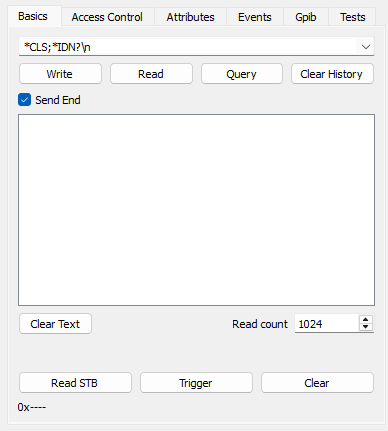
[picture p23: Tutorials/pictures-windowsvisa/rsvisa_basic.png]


If your instrument supports the `*IDN?` query, you may enter "`*IDN?`"
in the designated field and click Query; the instrument’s response will
then be displayed. However, many legacy instruments do not support this
command and may also lack EOI termination during read operations, which
can lead to unsatisfactory timeout errors giving the impression that
communication is not possible

For this reason, I have prepared this manual for the older HP3457A,
which requires some additional configuration steps. These requirements
are not unique to this USB GPIB Adapter - they apply to any GPIB adapter
and are dictated by the instrument itself.

The equipment’s GPIB programming manuals offer detailed guidance on
configuring the appropriate settings, and additional support is
available in the troubleshooting section if necessary. For certain
legacy instruments, these settings may be challenging to locate and may
require some degree of experimentation.

<u>**Point \#1:**</u> The used HP3457A does default wise not terminate
with EOI, but with \n. A query will result in a timeout. To enable \n
termination, go to the Attributes tab, select `VI_ATTR_TERMCHAR_EN`,
enter 1 in New AttributeValue field and click on SetAttribute.

To enable \n termination, go to the Attributes tab, select
`VI_ATTR_TERMCHAR_EN`, enter 1 in New AttributeValue field and click on
SetAttribute.

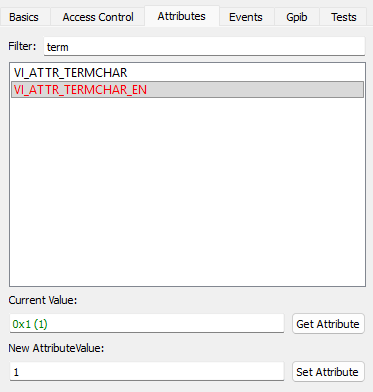
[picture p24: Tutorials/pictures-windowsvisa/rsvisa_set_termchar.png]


This is a non permanent setting, which is only valid for this currently
active session.

The attribute VI_ATTR_TERMCHAR does select the actual termination
character which is used to detect a termination of read GPIB messages.
Default wise it is 0xa (10), which matches \n and is for most older HP
instruments the correct settings.

<u>**Point \#2:**</u> HP3457A does not support the \*IDN? SCPI standard
query. Older HP Equipment required “ID?\r\n” as query.

After adjusting the termination settings as stated in Point \#1 you can
try to execute the ID?\r\n query:



The green highlighted section shows the response and the log window
shows no timeout, but VI_SUCCESS on the read and write instructions.
This confirms that the communication is working.

As mentioned, most equipment does not require an adjustment of the read
termination as they generate an EOI on read to terminate.

Note: Above items show the usage using RSVisaTester in an interactive
way. If you just want to access your instrument using Python, this is
typically not required, but it is a nice tool to debug your instrument.
It can also create logs of your visa instructions which you execute
using Python & PyVisa which is a powerful too for debugging during
development phase.

# Usage with Python

If all above steps succeeded, we can start using the UsbGpib device with
python. The following sections show a step-by-step guide using python
interactively. You can of course also create a script.

## Scanning for connected devices

Start python and import PyVisa.

Import PyVisa:



List available measurement devices:



In above output you can see, that one instrument is found. The returned
array contains a single string which is the so called "ressource string"
of the device. As mentioned before, that resource-string will be
different, depending on your actual GPIB device configuration and serial
number of the UsbGpib Adapter.

In case you see multiple devices being returned – the ones containing
texttt0x03EB::0x2065 are the one from the UsbGpib Adapter.

Open the instrument (adjust the string to the one which was returned by
the previous command):



If successful, no error is shown, and we can interact with the
instrument using the "inst" object.

If your instrument is SCPI compliant, you can now simply execute
`instr.query(’*IDN’)` to read the instrument name or better
identification string over GPIB.

As the used HP3457a is not SCPI compliant and requires specific
termination settings, we apply those settings now first during the next
steps.

To set \n termination for that instrument, execute those 2 lines:



Afterwards the read termination will be set to \n and queries or reads
will be successful from this instrument:



You can now write to the instrument using commands like `inst.write()`
for ASCII strings, `inst_write_binary_values` to send raw binary data,
among other variants.

To read data use inst.read() for ASCII strings,
`inst.read_binary_values()`, etc.

The previously used inst.query command is just a combination of write
followed by read. It will write the provided text strings (here ‘ID?’)
to the instrument, followed by a read and returns the information.

To disconnect from the instrument, execute `inst.close()`.

## Some more pyvisa Hints

### Stripping of read termination

An instrument which returns read termination, like the one used here
will contain in reads always read termination. As visible in previous
example, the ID? Query answer is terminated with \r\n.

Pyvisa can "strip away" the \r\n termination automatically, if you
specify a read_termination to it:



This read_termination setting is just a string handling within PyVisa,
it does not set any read termination of the GPIB adapter itself. So it
is no substitution of the previous `TERMCHAR` and `TERMCHAR_EN`
attributes which were used before.

### Automatic write Termination addition

As you saw in the examples, the query command string included \r\n as
termination. PyVisa can add this automatically, if you specify a write
termination, making the code a bit easier to read.



Again, `write_termination` is just a string based handling. Before the
string gets sent to the device, the set `write_termination` string is
added to the message internally.

### Timeout handling

Some instruments can take a longer time to return a response. This can
e.g. happen for large data transfers. There are sophisticated ways using
service requests that an instrument can signal with interrupts its
readiness, but sometimes it is easier to just increase the timeout.

The property timeout will return the current timeout in units of
milliseconds.



2000 means 2000ms which is 2s. This is the default timeout value.

You can change it by assigning another number to it. To increase the
timeout to 5s, execute:



Don’t forget: Timeouts can indicate actual errors like an unsupported
command; It can also indicate wrong write or read termination but also
be just simply the instrument taking a longer time to process a command.

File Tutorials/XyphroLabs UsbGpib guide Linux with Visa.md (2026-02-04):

- [XyphroLabs UsbGpib V2 Linux + Visa
  Guide](#xyphrolabs-usbgpib-v2-linux-visa-guide)
- [Introduction](#introduction)
- [Introduction](#introduction-1)
- [SW setup](#sw-setup)
  - [Installation of R&S Visa](#installation-of-rs-visa)
  - [Installation of PyVisa](#installation-of-pyvisa)
- [HW setup](#hw-setup)
- [First interaction with the
  instrument](#first-interaction-with-the-instrument)
  - [Confirming that the USB device is
    detected](#confirming-that-the-usb-device-is-detected)
  - [Testing if the instrument is detected by R&S
    Visa](#testing-if-the-instrument-is-detected-by-rs-visa)
    - [Why are no USBTMC devices
      found?](#why-are-no-usbtmc-devices-found)
- [Usage with Python & PyVisa](#usage-with-python-pyvisa)
  - [Scanning for connected devices](#scanning-for-connected-devices)
  - [Some more PyVisa hints](#some-more-pyvisa-hints)
    - [Stripping of read termination](#stripping-of-read-termination)
    - [Automatic write Termination
      addition](#automatic-write-termination-addition)
    - [Timeout handling](#timeout-handling)

# XyphroLabs UsbGpib V2 Linux + Visa Guide

Last Update: 2nd February 2026 This document is part of [Xyphro
UsbGpib](https://github.com/xyphro/UsbGpib) project

Prefer PDF? Click here:
[](XyphroLabs%20UsbGpib%20guide%20Linux%20with%20Visa.pdf)

# Introduction

# Introduction

This document provides guidance on utilizing the UsbGpib adapter with
Linux, specifically in conjunction with Python.

While the UsbGpib Adapter is no different to other UsbTmc instruments,
because it exposes a standard UsbTmc interface, these instructions are
mainly intended for first time users of Instrument control to give a
kick-start in using it and setting it up.

Various approaches are available, as the USB GPIB Adapter operates via
USBTMC. Users may directly employ the USBTMC Linux driver and interface
through C or other programming languages, use pyvisa-py or pyvisa-usbtmc
(which leverage a more direct access to the USB devices), or adopt the
standard practice of engaging a Visa provider.

The installation process detailed herein uses R&S Visa, which is
controlled from Python using Pyvisa. R&S Visa offers a standardized
interface compatible with PyVisa, LabVIEW, and other software packages.
Visa providers are also available from other companies like NI or
Keysight, but R&S Visa is the Visa provider which requires the least
amount of hard disk space ( 35MB). Most other visa providers install
Gigabytes of files on your computer, which is not required nor helpful.

The primary objective of such a Visa is to deliver a unified API for
managing multiple types of interfaces - regardless of their physical
connection (USB, different Ethernet protocols, Serial port) - and it is
widely used as a standard tool used for automating test and measurement
setups.

For demonstration purposes, Ubuntu 24.04.3 LTS serves as the platform in
this guide. A fresh installation was made to create this guide, to
ensure that all dependencies are captured.

# SW setup

## Installation of R&S Visa

Please visit
<https://www.rohde-schwarz.com/us/applications/r-s-visa-application-note_56280-148812.html>

In case this links does not work in future, use a google search for "R&S
Visa Download" to find the most recent correct link.

Download the RS Visa Setup for Ubuntu:



Once downloaded, the file will be in your Downloads folder:



To proceed, double-click the file or install it via the command line.

A warning may appear, indicating that the file originates from a third
party $`R\&S`$:



Select "Install" and confirm your intention to proceed. When prompted,
enter your user password to grant SUDO privileges.

Upon completion of the installation, three new applications will become
available:



Although not strictly required, RsVisa Tester is a graphical user
interface application that facilitates instrument scanning and enables
basic read/write tests, making it particularly valuable during initial
system bring-up.

Note, that the release notes of R&S Visa contain also installation
instructions – also for Windows, Mac OSX or other Linux flavors; Even
Raspberry PI with Raspbian.

We will continue with the hardware setup in the next section.

## Installation of PyVisa

PyVisa is necessary for interfacing with the instrument using Python.
PyVisa will interface to the visa provider which then interfaces to the
instrument.

This guide utilizes Python 3. Please ensure that both Python 3 and pip3
are installed prior to proceeding.

To ensure that execute from terminal:

    sudo apt-get install python3 python3-pip python3-pyvisa

 (The actual output
will vary depending on which packages are already installed on your
machine)

All above steps are one-time actions.

Let’s proceed to the HW setup.

# HW setup

In this example I use a HP3457A Multimeter with GPIB:



Initial one-time steps:

- Connect it to power but keep it powered off.

- Connect the USB GPIB converter to the GPIB port and the USB cable to
  your PC.  
  Note: The PC won’t detect a USB device yet as the instrument is
  powered off. This is a feature to prevent inaccessible devices are
  showing up on your PC.  
  

- Power on the GPIB device.  
  Note: The PC does now detect a new USB Device.

It is not necessary to follow a specific sequence for connecting or
disconnecting devices, powering them up or down, and similar actions.
However, the following order is provided to present the instructions in
a logical, step-by-step manner. As indicated in the procedure, the
adapter will only be detected by a PC when the instrument is powered on
and GPIB functionality is enabled.

The adapter monitors USB connections to identify whether any devices
with GPIB enabled are present.

Regardless of the specific GPIB address, it systematically scans all
available addresses on its GPIB port. Upon detecting a responsive GPIB
address, the adapter enumerates the device on the USB interface, thereby
enabling access from the PC.

# First interaction with the instrument

## Confirming that the USB device is detected

The following steps are not mandatory but can be beneficial for
debugging. They verify that the USBTMC device is recognized by the PC
and that the instrument is properly powered and configured for GPIB
communication.

Execute from terminal:

    lsusb



The output above displays an entry with VID:PID 03eb:2065, identifying
the USB GPIB Adapter.

This device will appear when all connections are established according
to the HW-Setup section, GPIB functionality is enabled on the
instrument, and the instrument is powered on.

Further information can be seen when executing:

    lsusb -v



The green highlighted area displays the USBGPIB adapter serial number.
In this instance, it indicates the detected GPIB address, which is 22.
The subsequent numbers represent a unique serial number, allowing users
to distinguish between multiple USB GPIB adapters when identical GPIB
addresses are assigned to different instruments.

Please note that the GPIB adapter may also display the instrument name
instead of the GPIB address if the AutoID feature is enabled.

## Testing if the instrument is detected by R&S Visa

You can close open terminal windows, etc.

Start the RsVisa Tester application:



After starting the below GUI window is shown:  


While the interface may appear complex to first-time users, it contains
numerous standard features that help in initial instrument communication
and debug. To verify detection of the GPIB instrument, select “Find
Resource” in the upper left corner.

A new window opens:  


Select the green-highlighted button to initiate an instrument scan.

If no USBTMC devices are detected, please refer to the section titled
"Why are no USBTMC devices found?".

This situation typically occurs during initial installations, and the
section provides guidance on how to enable device availability on a
persistent basis.

If the operation is successful, a USB device should be visible as shown.
Please note that the previously displayed serial number forms part of
the resource string.



Select the found devices and click OK.

Now you are back to the main window. The ressource field should show the
previously detected device:  


Now you can click on the connect button to connect to the instrument.

The log lines should show a successful connection:  


The right side of the main GUI window now gives the ability to interact
with the instrument:  


If your instrument supports the \*IDN? query, you may enter “\*IDN?” in
the designated field and click Query; the instrument’s response will
then be displayed.

However, many legacy instruments do not support this command and may
also lack EOI termination during read operations, which can lead to
unsatisfactory timeout errors giving the impression that communication
is not possible

For this reason, I have prepared this manual for the older HP3457A,
which requires some additional configuration steps. These requirements
are not unique to this USB GPIB Adapter - they apply to any GPIB adapter
and are dictated by the instrument itself.

The equipment’s GPIB programming manuals offer detailed guidance on
configuring the appropriate settings, and additional support is
available in the troubleshooting section if necessary. For certain
legacy instruments, these settings may be challenging to locate and may
require some degree of experimentation.

<u>**Point \#1:**</u> The used HP3457A does default wise not terminate
with EOI, but with \n. A query will result in a timeout.

To enable \n termination, go to the Attributes tab, select
`VI_ATTR_TERMCHAR_EN`, enter 1 in New AttributeValue field and click on
SetAttribute.



This is a non permanent (so non volatile) setting, which is only valid
for this currently active session.

The attribute `VI_ATTR_TERMCHAR` does select the actual termination
character which is used to detect a termination of read GPIB messages.
Default wise it is 0xa (10), which matches \n and is for most older HP
instruments the correct settings.

<u>**Point \#2:**</u> HP3457A does not support the \*IDN? SCPI standard
query. Older HP Equipment required `"ID?\r\n"` as query.

After adjusting the termination settings as stated in Point \#1 you can
try to execute the ID?\r\n query:



The green highlighted section shows the response and the log window
shows no timeout, but `VI_SUCCESS` on the read and write instructions.
This confirms that the communication is working.

As mentioned, most equipment does not require an adjustment of the read
termination as they generate an EOI on read to terminate.

Note: Above items show the usage using RSVisaTester in an interactive
way. If you just want to access your instrument using Python, this is
typically not required, but it is a nice tool to debug your instrument.
It can also create logs of your visa instructions which you execute
using Python & PyVisa which is a powerful too for debugging during
development phase.

### Why are no USBTMC devices found?

A "Find Resource scan" performed on RsVisaTester may yield no detected
instruments. Furthermore, each time the scan button is pressed, the main
GUI screen’s log displays entries indicating this outcome:



This message indicates that no instruments were detected. However, this
situation may occur even when an instrument is properly connected, but
permissions to usbtmc devices are not properly set up yet on the machine
and access would only work with SUDO rights.

To set them correctly, add them to the usbtmc.rules file:

Execute:

    sudo nano /etc/udev/rules.d/99-usbtmc.rules

Add this line to the file:

    SUBSYSTEM=="usb", ATTR{idVendor}=="03eb", ATTR{idProduct}=="2065", MODE="0666"

The 2 highlighted parts are the vendor ID and product ID, which were
shown earlier in the lsusb output. For this USB GPIB adapter, the
numbers will never change and always be the same. But in case you want
to support other USB connected measurement instruments, adjust those
numbers.

After adding this line and saving with \<CTRL\>+O and exciting, execute:

    sudo udevadm control --reload-rules
    sudo udevadm trigger

or reboot the machine.

Also disconnect and reconnect the USB cable once after executing those
lines.

Note: Instead of using the described line, you can also add this line:

    KERNEL=="usbtmc[0..9]", SUBSYSTEM=="usbmisc", MODE="0666"

It will set usbtmc0 to usbtmc9 devices access rights, without requiring
to specify a vendor and product ID, thus is a bit more generic.

# Usage with Python & PyVisa

If Python and PyVISA have been installed as outlined in previous
sections, you should now be able to communicate with your instrument.
This section provides suggestions and example code snippets to assist
with this process.

While step-by-step interactive usage within the Python console is
demonstrated here, the provided snippets may also be integrated into
standalone Python scripts as needed.

## Scanning for connected devices

Start python3:  


Import pyvisa:  


And create a visa resource manager (which allows listing resources at a
later stage):  


When you enter: `rm.list_ressources()` all available visa resources will
be shown:  


Our instrument is also part of this, as highlighted with the green box.

To open the instrument, type:  


Your actual instrument name (called the resource string) will vary of
course.

In case a "\[Errno 16\] Resource busy" error is shown, it is possible,
that it is e.g. still open in RsVisaTester – ensure that you are
disconnect there. It is also possible, that the device is still open
from previous python experiments – in that case execute inst.close()
before or create a new python session.

If successful, no error is shown, and we can interact with the
instrument using the "inst" object.

If your instrument is SCPI compliant, you can now simply execute
instr.query(’\*IDN’) to read the instrument name or better
identification string over GPIB.

As the used HP3457a is not SCPI compliant and requires specific
termination settings, we apply those settings now first during the next
steps.

To set \n termination for that instrument, execute those 2 lines:  


Afterwards the read termination will be set to \n and queries or reads
will be successful from this instrument:  


You can now write to the instrument using commands like `inst.write()`
for ascii strings, textttinst_write_binary_values to send raw binary
data, among other variants.

To read data use `inst.read()` for ascii strings,
`inst.read_binary_values()`, etc.

The previously used `inst.query` command is just a combination of write
followed by read. It will write the provided text strings (here `’ID?’`)
to the instrument, followed by a read and returns the information.

To disconnect from the instrument, execute `inst.close()`.

## Some more PyVisa hints

### Stripping of read termination

An instrument which returns read termination, like the one used here
will contain in reads always read termination. As visible in previous
example, the `ID?` Query answer is terminated with \r\n.

Pyvisa can "strip away" the \r\n termination automatically, if you
specify a read_termination to it:  


This read_termination setting is just a string handling within pyvisa,
it does not set any read termination of the GPIB adapter itself. So it
is no substitution of the previous `TERMCHAR`and `TERMCHAR_EN`
attributes which were used before.

### Automatic write Termination addition

As you saw in the examples, the query command string included \r\n as
termination. PyVisa can add this automatically, if you specify a write
termination, making the code a bit easier to read.  


Again, write_termination is just a string based handling. Before the
string gets sent to the device, the set write_termination string is
added to the message internally.

### Timeout handling

Some instruments can take a longer time to return a response. This can
e.g. happen for large data transfers. There are sophisticated ways using
service requests that an instrument can signal with interrupts it’s
readiness, but sometimes it is easier to just increase the timeout. The
property timeout will return the current timeout in units of
milliseconds.  


2000 means 2000ms which is 2s. This is the default timeout value. You
can change it by assigning another number to it. To increase the timeout
to 5s, execute:  


Don’t forget: Timeouts can indicate actual errors like an unsupported
command; It can also indicate wrong write or read termination but also
be just simply the instrument taking a longer time to process a command.

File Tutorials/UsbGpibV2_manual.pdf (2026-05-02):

1

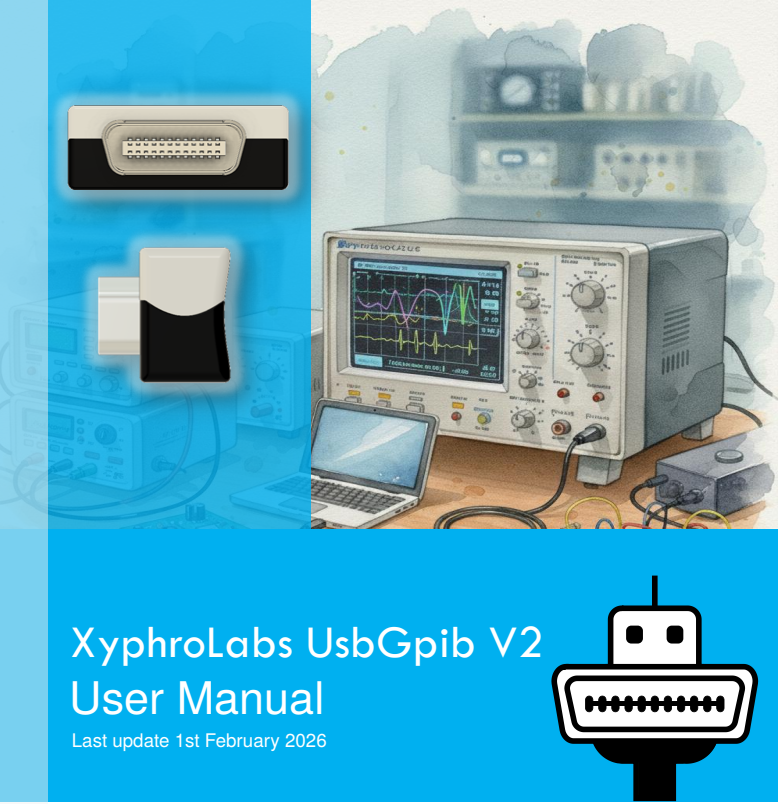
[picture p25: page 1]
XyphroLabs UsbGpib V2 User Manual

Last update 1st February 2026

# Contents

2

## 1 Introduction

The UsbGpib V2 is a compact, high-performance USB-to-GPIB adapter engineered from the ground up for seamless integration with modern and legacy test equipment.

Unlike clone devices, UsbGpib V2 delivers robust IEEE-488.1 and IEEE-488.2 compatibility, stable USBTMC operation, and a unique device identifier that ensures consistent VISA resource naming across systems - eliminating the need for manual remapping or COM port assignments.

Designed to match the physical footprint and cable path of traditional GPIB connectors, the adapter fits into all existing lab setups while offering significant advantages in space efficiency, cable management, and cross-platform support. Whether you’re automating instrument control on Windows, macOS, Linux, or FreeBSD, UsbGpib V2 provides plugand-play reliability without proprietary drivers.

With firmware upgradability, protocol-aware communication, and a focus on user-friendly integration, UsbGpib V2 is the ideal choice for engineers, researchers, and developers seeking a dependable GPIB interface that just works.

## 2 Advantages of UsbGpib V2 adapter

- Modern Connectivity: Bridges USB and IEEE 488 (GPIB) with full USBTMC protocol compliance
- Slim Design: Minimal depth of just 1.5cm allows instruments to be placed closer to walls or rack panels
- Cable Efficiency: Uses thin USB cables instead of bulky ”garden hose” GPIB cables, reducing clutter and improving portability
- Multi Adapter Support: Unique identifier per unit enables multiple adapters to be connected and operated reliably on the same PC
- No COM Ports: Avoids serial port mapping issues; Each adapter is consistently accessible with the same name across multiple PCs
- Transparent Operation: Plug into your instruments GPIB port and it behaves like a modern USB measurement device, including proper USB port deactivation when the instrument is powered off
- Controller Role: Optimized as a dedicated GPIB controller for one instrument per adapter, ensuring robust one to one communication and optimized cable management.
- Standards Compliance: Implements full IEEE-488.1 IEEE 488.2 controller support via USBTMC, including status byte reading, triggering, service requests, and termination settings
This document is part of Xyphro UsbGpib (https://github.com/xyphro/UsbGpib) project | Page — 3

- Software Compatibility: Works seamlessly with all standard VISA providers (NI VISA, Rohde & Schwarz VISA, Keysight VISA)
- Tool Integration: Fully compatible with LabVIEW, MATLAB, PyVISA, and PyVISA py for established and modern automation workflows
- Cross Platform Support: Operation across Windows, macOS, FreeBSD, and Linux
- German Engineering: Designed and developed in Germany over six years, extensively tested for robustness and compatibility with instruments from new to decades old
- Reliability: Built to ensure long automated measurement sequences complete without interruption
- Future Proof: Firmware is field upgradable and actively maintained, providing ongoing improvements and compatibility updates

## 3 Safety Precautions

To ensure reliable operation and long-term durability of the UsbGpib V2 adapter, please observe the following environmental and handling Guidelines

### 3.1 Operating Conditions

Temperature Range: 0°C to +50°C
Humidity: | 10% to 90% RH, non-condensing
Altitude: | Up to 2000m above sea level

### 3.2 Storage Conditions

Temperature Range: -20°C to +70°C
Humidity: | 5% to 95% RH, non-condensing

### 3.3 Moisture & Contaminants

- Avoid exposure to liquids, vapors or corrosive substances
- Do not operate in environments with condensation, high dust levels or chemical fumes

### 3.4 Electric Safety

- Do not expose to voltage levels above 6V
- Do not short circuit or connect to non IEEE488 / non-USB compliant ports
- Ensure proper grounding of connected instruments

### 3.5 Handling & Installation

- Do not bend or stress the USB or GPIB connectors during installation
- Avoid excessive force when plugging/unplugging
- Avoid direct sunlight
- Keep away from electrostatic discharge (ESD) sources; use ESD-safe handling procedures

## 4 Overview

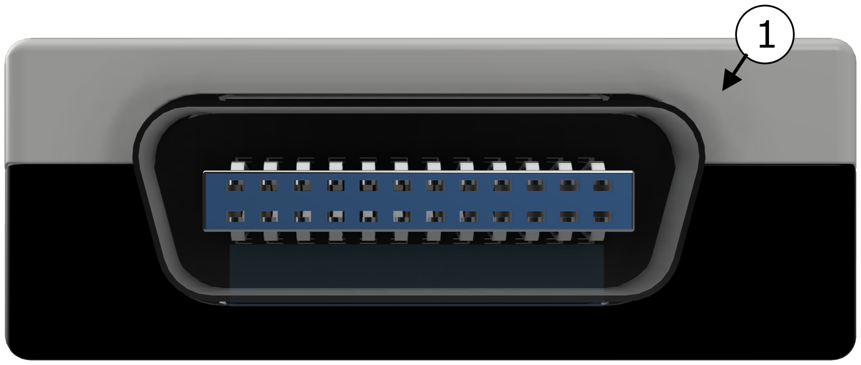
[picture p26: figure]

(1) GPIB connector - Plugs directly into your measurement equipments GPIB port.
(2) Status LED
(3) Firmware update button

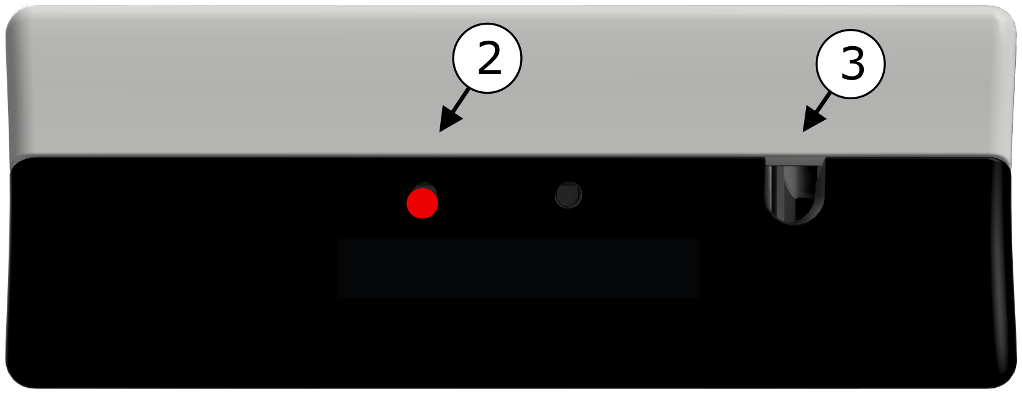
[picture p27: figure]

4
(4) USB-Type C connector - plug it with either a USB Type C to USB type A or USB type C to type C cable into your PC.

## 5 LED

The LED has multiple purposes as summarized in the table below.

Led blinking with a frequency of about 2
Hz. | The Adapter is connected to a USB
| port, but no GPIB device is found. Con-
| nect a GPIB measurement device to
| the GPIB port and ensure that GPIB is
| enabled in the instrument.
LED is continuously on.
| The GPIB device was identified, but no
| GPIB communication is executed from
| PC.
LED is flickering (mostly on, but sometimes off for short periods).

long short

Every time GPIB data is transferred from the PC or to the PC, the LED will be turned off for short periods of time. This indicates data exchange = activity. LED is always off.
The USB port is not connected to the PC, the PC powered off or the USB cable defect.

## 6 Using the adapter

To use the adapter, connect the USB-C connector with a USB cable to a PC.

The GPIB connector can be plugged directly into the measurement instrument, which you want to control. It can also connect via a GPIB cable if required due to setup constraints.

When the measurement equipment is turned on and if the GPIB port is enabled in the instrument, the adapter will enumerate on the PC as USBTMC class device.

Operating system specific instructions & tutorials are available under this link:

https://github.com/xyphro/UsbGpib/blob/master/Tutorials/README.md

Those tutorials explain how to ensure that a USB driver is installed and guide through the first setup up to the point where you can talk with the instrument.

Note: The UsbGpib Adapter does not enumerate on the PC, if it is not connected to a GPIB measurement device, which is powered and GPIB enabled.

## 7 Firmware update procedure

The UsbGpib V2 adapter comes preinstalled with a firmware. But as the firmware is actively maintained you might want to update the adapters firmware sooner or later. The UsbGpib V2 adapter allows for firmware updates. It requires the bootloader mode to be entered, followed by programming the firmware and power cycling the adapter.

Firmware images are distributed via GitHub:

https://github.com/xyphro/UsbGpib/tree/master/SW/binaries

to download, left-click on ”TestAndMeasurement.bin” file. After the new page loads, click on the RAW button on the top right side:

After downloading the file, rename it to FLASH.BIN. Ensure to use capital letters for the full filename during rename. Filenames with lowercase letters like ”Flash.bin”, ”flash.bin”, ”FLASH.bin” will result in the firmware update procedure not to work (but it won’t break the adapter).

After downloading the file, enter the bootloader:

- Connect the adapter to a PC via USB. The GPIB side can be left unconnected.
- Hold the button (3) down for a few seconds (use e.g. a pencil to push it), until the PC recognizes a memory stick device (USB flash or mass storage device).

A new drive appears on the PC:

Then open a command line and enter a command like the following:

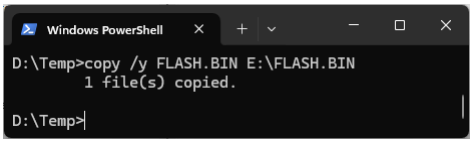
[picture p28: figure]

On Linux, use this command to transfer a firmware update, instead of using cp: dd if=TestAndMeasurement.bin of=/mnt/FLASH.BIN bs=512 conv=notrunc oflag=direct,sync

Adjust the file paths and drive letters to your actual system. When no error is shown, you can unplug USB (and GPIB) and reconnect to power cycle the adapter and use the new firmware.

Note: Drag and drop operation e.g. from Windows explorer does
will work. Ensure you use the command line method as described.

## 8 Technical specifications

Item | Specification

USB power require-
ments | • 5V supply voltage nominal
- Valid supply voltage range: 4.5V to 5.5V
- 100mA current consumption
USB standard
- USB 1.1, USB 2.0, USB 3 and higher are supported with full speed mode

USB connector
- USB Type-C connector
- Compatible with USB-A by using a USB Type C to USB Type A cable
- Compatible with USB Type C to USB Type C cable. Supported IEEE-488
features | • IEEE-488.1, IEEE-488.2, HPIB, GPIB compatible
- Service request (reported using interrupt transfers)
- Device Clearing
- Trigger
- Status Byte read
- GPIB write, read and queries
(supports | talker | only, | listener | only | and
talker+listener instruments)
- Full timeout support for reliable operation
- All GPIB features are exposed using the exact US-BTMC equivalents for good compatibility Supported IEEE-488
device roles | • Controller

Operating Systems
- Windows
- Linux, FreeBSD
- Mac-OS

Item | Specification
Dimensions | • Excluding GPIB connector: 60mm x 23mm x 15mm (Width x Height x Depth) • Including GPIB connector: 60mm x 23mm x 22mm (Width x Height x Depth)
Weight | • 30g

## 9 Frequently Asked Questions

Why doesn’t the adapter show up on my PC when I plug it in?
This is a feature called ”Ghost Mode.” The adapter only enumerates (becomes visible) on the PC if it is connected to a GPIB instrument that is powered on. This reduces device manager clutter when you have multiple adapters connected to instruments that are currently off.

The reason for this feature is to make an instrument behave like one with native USB interface and avoid seeing adapters on the PC with that you can’t communicate anyway as there is no measurement equipment connected.

What is the AutoID feature of UsbGpib V2?
AutoID is a feature where the adapter automatically queries the instrument for its identity (using *IDN?) and uses that information to create a unique VISA resource name. For very old instruments that do not support *IDN?, this feature should be disabled to avoid errors. When Auto ID is off, the Visa ressource name is constructed out of the GPIB address of the instrument and a unique serial number of the GPIB adapter.

What are the AutoID timing options?
When the AutoID feature is enabled there are different delay options. This delay specifies how long the adapter waits after instrument turnon before executing the *IDN? query for the AutoID feature. While 5s works for each instrument, some instruments require a setting to higher number which is exposed by the other AutoID settings. AutoID is a non-volatile setting which is permanently stored in the MCUs eeprom. UsbGpibGui:
- AutoID ON: The adapter waits 5 seconds after detecting a powered GPIB instrument before performing the identification scan *IDN?.
- AutoID SLOW: Increases the initial waiting period to 15 seconds before the scan begins.
- AutoID SLOWEST: Designed for instruments with very long boot sequences, this setting waits 30 seconds before attempting to communicate on the GPIB side.

- AutoID OFF: Disables the automatic identification query entirely. This is essential for older, non-SCPI instruments that do not support the *IDN? query and might return errors or lock up if they receive it.

Tip: Turn AutoID OFF for older non SCPI compliant instruments to avoid that they start up with an Error. To change the AutoID settings you can use e.g. the UsbGpibGui in the UsbGpib SW folder for Windows or NiceGui for Linux. Note that UsbGpib GUI requires a Visa installation.

How do I set Read Termination?
It is best to use standard VISA attributes:
- Set VI ATTR TERMCHAR EN to 1.
- Set VI ATTR TERMCHAR to 0x0A (or any other ASCII character).

With firmware version ≥ 2.2 you can set any read termination character you like, from ASCII code 0 to 255. This enables instruments to react on EOT, CR, LF or any other character like e.g. ’,’ for easier parsing of input data. Independent of the set termination character setting the instrument will always react on the GPIB EOI as termination of a read query.

When read termination is turned off, the read termination is EOI only.

Is the UsbGpib adapter a clone of an existing commercial adapter?
No. This is a common and important misconception. The UsbGpib adapter is a completely original, open-source hardware and software project and does not copy commercial adapters. It works for that reasons without risk of getting blocked or locked out in future.
- Unique Identity: Unlike the many inexpensive adapters found on online marketplaces, this is not a counterfeit clone of National Instruments (NI), Keysight or other hardware.
- Safe to Use: Because it is not a clone, it is safe from ”driver sabotage.” Vendor software updates (like those from NI-VISA) often detect and disable counterfeit hardware; since this adapter uses its own independent firmware and identity, it remains fully functional and stable regardless of official driver updates.
- Standard Compliance: Instead of mimicking a proprietary device, it implements the standard USBTMC-USB488.2 protocol. This allows it to ”nicely integrate” into any VISA environment by following industry standards rather than exploiting a specific manufacturer’s driver.

In short: It is an independent, professional-grade tool designed to coexist peacefully within the ecosystem of your choice.

Does it support Service Requests (SRQ)?
Yes, the adapter actively pushes SRQ signaling to the PC via an interrupt pipe, as mandated by the USBTMC 488.2 standard. This means your software does not need to poll for status continuously.

Can I use it with Linux?
Yes, it can be used either as a standard USBTMC device or through Linux-GPIB for advanced features like controlling multiple instruments with a single adapter. In case you want to use Linux-GPIB, have a look here and search for ”xyphro” for further instructions: https://linux-gpib.sourceforge.io/doc html/supported-hardware.html (https://linux-gpib.sourceforge.io/doc_html/supported-hardware.html)

Do I really need to use a VISA library?
Technically, no-but it is highly recommended. Because the adapter follows the standard USBTMC protocol, it is natively recognized by modern operating systems. Visa, while it seems like an ”old-school concept” is a quite convinient tool to enable access to instruments over multiple different interfaces with a common interface.

I started e.g. by controlling only USBTMC instruments and made a dedicated solution for that without visa, but when I later wanted to control GPIB instruments and Ethernet based instruments in the same setup, that ”island solution” concept breaked and I started looking seriously into Visa and saw the clear benefits. Don’t get shocked by Gigabytes of Visa installation - there are smaller Visas available like e.g. R&S Visa. Lean and mean and available for Mac OS, Windows, Linux and even Raspberry PI with the same application level interface across those operating systems. You also get a very stable tested solution for your instrument access and can focus on the real measurement task.

- With VISA: Libraries like R&S VISA or NI-VISA provide a unified API. This is the most stable path for tools like LabVIEW or standard PyVISA.
- Linux native: You can interact directly with the kernel driver via /dev/usbtmcX. For advanced users, Linux-GPIB also supports the adapter via a dedicated firmware variant.
- python-usbtmc: A great alternative if you want to avoid a VISA installation entirely. It is a bit more ”hands-on” (manual configuration), but it supports the full command set of the adapter more reliably than PyVISA-py in many cases.
- PyVISA-py: A ”VISA-free” Python backend. While popular, it currently has an incomplete USBTMC implementation (e.g., issues with version queries). Basic instrument communication works, but it may require workarounds for advanced features.

Recommendation: Use R&S VISA for a lightweight, professional setup, or the python-usbtmc package if you strictly require a driverless Python environment.

Can the CMU200 which uses GPIB subaddressing be used with this adapter? Yes, the CMU200 is supported and used too by me. USbGpib exposes the first subaddresses which gives access to most features.

Also other devices with GPIB subaddressing are supported. UsbGpib will always expose the firstly found subaddress over USBTMC.

## 10 References

Issue reports and support

https://github.com/xyphro/UsbGpib/issues

Technical support and
feature requests

xyphro@gmail.com

Firmware download | https://github.com/ xyphro/UsbGpib/blob/master/SW/binaries/ TestAndMeasurement.bin (https://github.com/xyphro/UsbGpib/blob/master/SW/binaries/TestAndMeasurement.bin)
Tutorials | https : / / github . com / xyphro / UsbGpib / blob / master / Tutorials / README.md (https://github.com/xyphro/UsbGpib/blob/master/Tutorials/README.md)

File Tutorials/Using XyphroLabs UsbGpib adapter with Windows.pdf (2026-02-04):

1

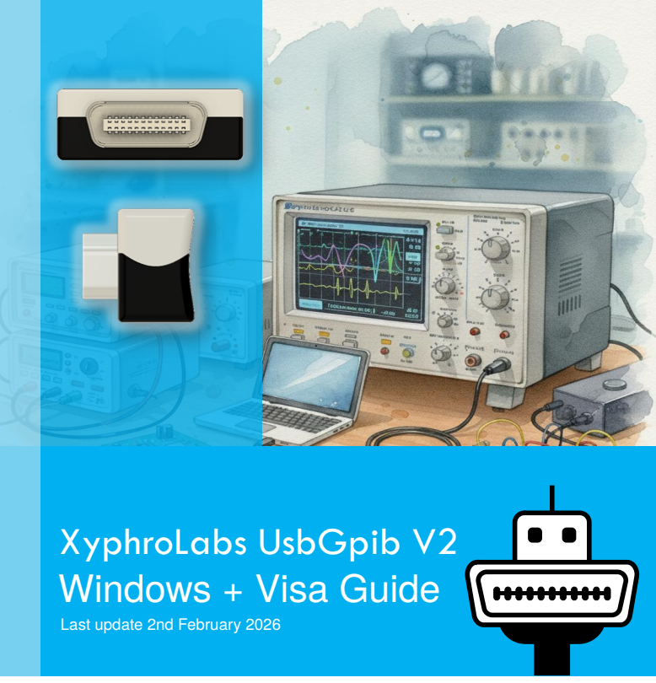
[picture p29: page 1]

XyphroLabs UsbGpib V2
Windows + Visa Guide

Last update 2nd February 2026

# Contents

2

## 1 Introduction

This document offers instructions for using the UsbGpib adapter with Windows environments, particularly when integrating with Python.

Although the UsbGpib Adapter functions like other USBTMC instruments by presenting a standard UsbTmc interface, these guidelines are primarily aimed at assisting users who are new to instrument control, providing them with an effective starting point for configuration and utilization.

On Windows platforms, there 2 popular methods for interfacing with USBTMC instruments: One utilizes LibUsb in conjunction with PyVisa-Py, while the other employs the conventional approach of using a VISA tool. Given the complexities that can arise during LibUsb installation, it is advisable to proceed with a standard VISA provider.

Leading VISA tools are offered by National Instruments, Key-sight, and Tektronix. However, these solutions often require significant disk space. In contrast, the R&S VISA package is notably compact - requiring less than 100 MB - enabling swift installation without compromising on performance or compatibility. Many alternative Visa tools include superfluous components and may require over 1 GByte of storage space in addition to extended download times.

This document details the process for installing R&S VISA and PyVisa, guiding users through to the initial stages of communicating with an instrument using Python.

## 2 SW setup

### 2.1 Installation of R&S Visa

Download R&S Visa from the R&S Page: https://www.rohde-schwarz.com/us/driverpages/remote-control/3-visa-and-tools 231388.html?change c=true (https://www.rohde-schwarz.com/us/driver-pages/remote-control/3-visa-and-tools_231388.html?change_c=true)

In case that link does not work at time of reading, search the web with ”R&S Visa Windows download”.

This document is part of Xyphro UsbGpib (https://github.com/xyphro/UsbGpib) project | Page — 3


DoubleClick the downloaded file to start installation.

Please select the necessary components. For this guide, the primary requirement is the R&S VISA for Developer 64/32-Bit. If you also plan to use VISA with .NET applications in the future, it may be beneficial to include that component as well. However, for Pythonspecific usage, this selection is not required.


After selecting, click Install.

The R&S Visa installation also installs the USB driver for the UsbGpib adapter.

### 2.2 Python setup

For accessing R&S Visa using Python you need to install pyvisa. Depending on your Python environment that can be done with Anaconda or Pip. When you use pip, you can just type ”pip install pyvisa” in a command window. In case you have multiple python installations, ensure you do that for the one that you also use later. When using Spyder as python IDE, you can also type that command directly into the python Console:

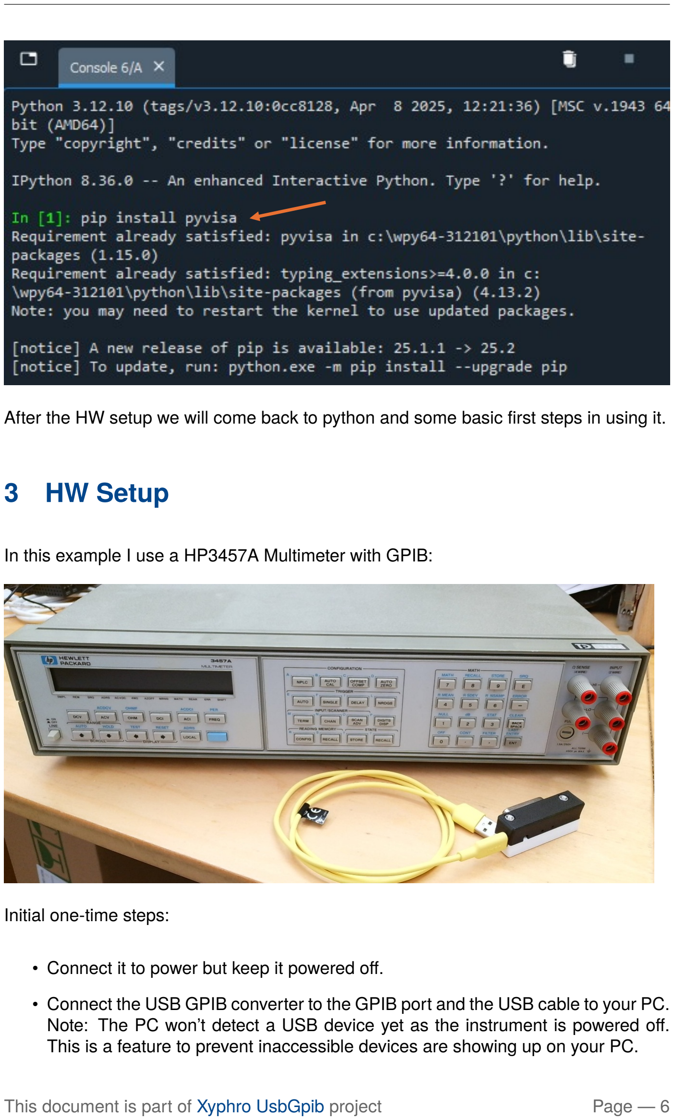
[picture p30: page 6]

After the HW setup we will come back to python and some basic first steps in using it.

## 3 HW Setup

In this example I use a HP3457A Multimeter with GPIB:

Initial one-time steps:

- Connect it to power but keep it powered off.
- Connect the USB GPIB converter to the GPIB port and the USB cable to your PC. Note: The PC won’t detect a USB device yet as the instrument is powered off. This is a feature to prevent inaccessible devices are showing up on your PC.


- Power on the GPIB device.
Note: The PC does now detect a new USB Device.

It is not necessary to follow a specific sequence for connecting or disconnecting devices, powering them up or down, and similar actions. However, the following order is provided to present the instructions in a logical, step-by-step manner. As indicated in the procedure, the adapter will only be detected by a PC when the instrument is powered on and GPIB functionality is enabled. The adapter monitors USB connections to identify whether any devices with GPIB enabled are present. Regardless of the specific GPIB address, it systematically scans all available addresses on its GPIB port. Upon detecting a responsive GPIB address, the adapter enumerates the device on the USB interface, thereby enabling access from the PC.

## 4 First interaction with the instrument

### 4.1 Confirming that the USB device is detected

You can check in the Device manager to confirm if the instrument was found and the driver (which got installed by the R&S Visa installation) is found.

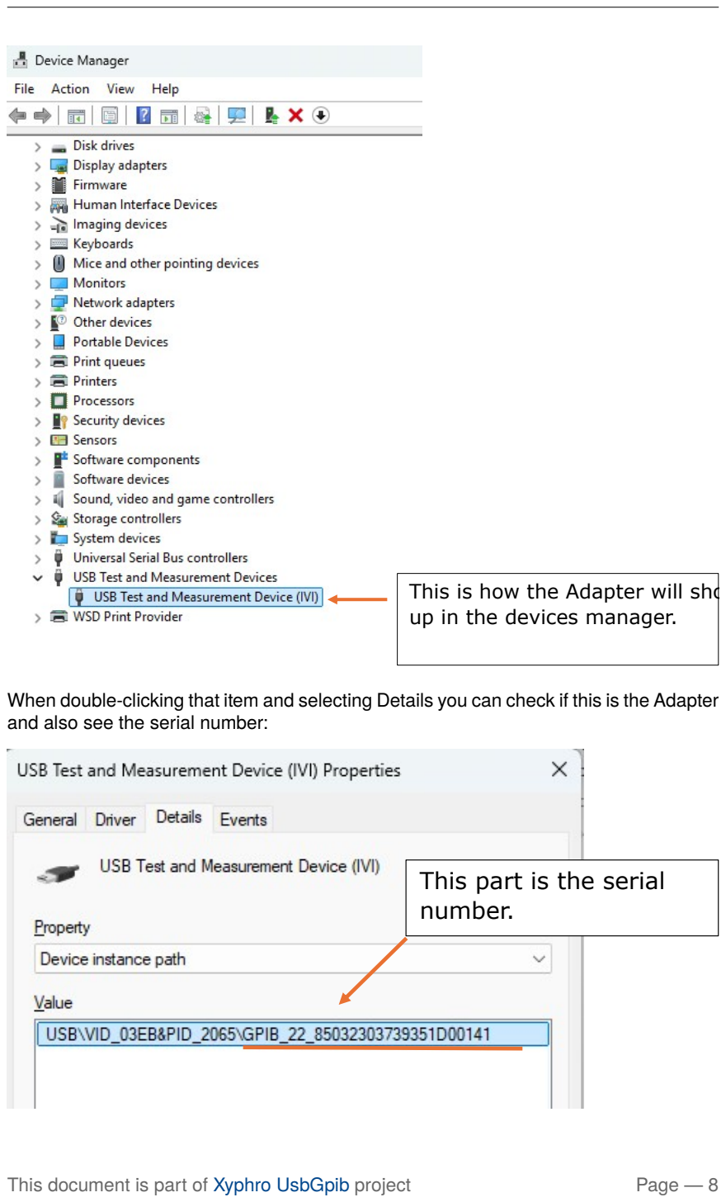
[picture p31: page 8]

## This is how the Adapter will sho

up in the devices manager.

When double-clicking that item and selecting Details you can check if this is the Adapter and also see the serial number:

## This part is the serial

number.

The serial number is different for each device. It is constructed out of the detected GPIB address of the connected GPIB instrument (here GPIB 22) followed by a unique ID which is different for each adapter. That allows to use same GPIB addresses for multiple instruments, without them disturbing each other.

### 4.2 Testing if the instrument is detected by R&S Visa

Start the RsVisa Tester application:

After starting the below GUI window is shown:

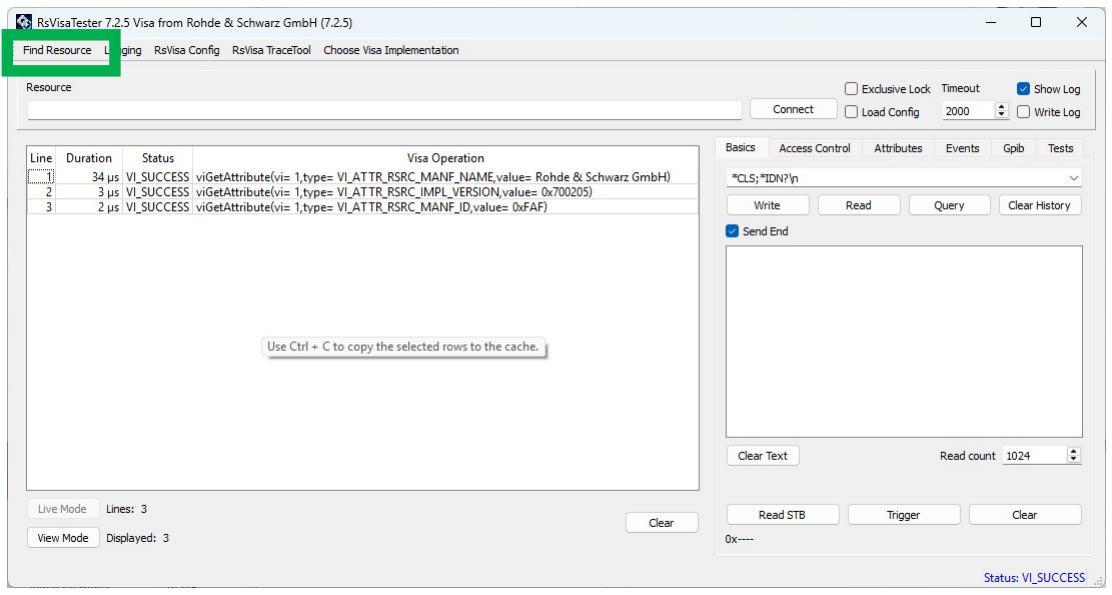
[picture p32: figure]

While the interface may appear complex to first-time users, it contains numerous standard features that help in initial instrument communication and debug. To verify detection of the GPIB instrument, select ”Find Resource” in the upper left corner.

A new window opens:

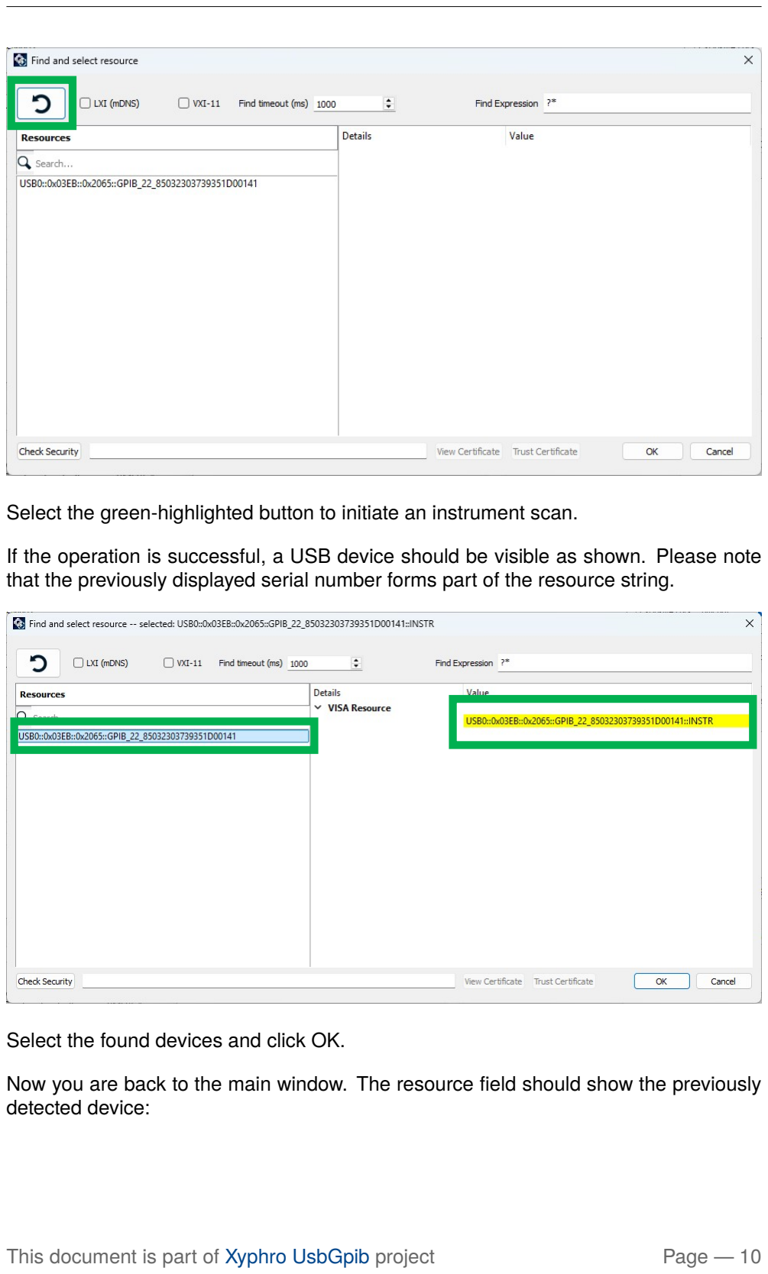
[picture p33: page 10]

Select the green-highlighted button to initiate an instrument scan.

If the operation is successful, a USB device should be visible as shown. Please note that the previously displayed serial number forms part of the resource string.

Select the found devices and click OK.

Now you are back to the main window. The resource field should show the previously detected device:

Now you can click on the connect button to connect to the instrument. The log lines should show a successful connection:

The right side of the main GUI window now gives the ability to interact with the instrument:


If your instrument supports the *IDN? query, you may enter ”*IDN?” in the designated field and click Query; the instrument’s response will then be displayed. However, many legacy instruments do not support this command and may also lack EOI termination during read operations, which can lead to unsatisfactory timeout errors giving the impression that communication is not possible

For this reason, I have prepared this manual for the older HP3457A, which requires some additional configuration steps. These requirements are not unique to this USB

GPIB Adapter - they apply to any GPIB adapter and are dictated by the instrument itself.

The equipment’s GPIB programming manuals offer detailed guidance on configuring the appropriate settings, and additional support is available in the troubleshooting section if necessary. For certain legacy instruments, these settings may be challenging to locate and may require some degree of experimentation.

Point #1: The used HP3457A does default wise not terminate with EOI, but with \n. A query will result in a timeout. To enable \n termination, go to the Attributes tab, select VI ATTR TERMCHAR EN, enter 1 in New AttributeValue field and click on SetAttribute.

To enable \n termination, go to the Attributes tab, select VI ATTR TERMCHAR EN, enter 1 in New AttributeValue field and click on SetAttribute.


This is a non permanent setting, which is only valid for this currently active session.

The attribute VI ATTR TERMCHAR does select the actual termination character which is used to detect a termination of read GPIB messages. Default wise it is 0xa (10), which matches \n and is for most older HP instruments the correct settings.

Point #2: HP3457A does not support the *IDN? SCPI standard query. Older HP Equipment required “ID?\r\n” as query.

After adjusting the termination settings as stated in Point #1 you can try to execute the ID?\r\n query:

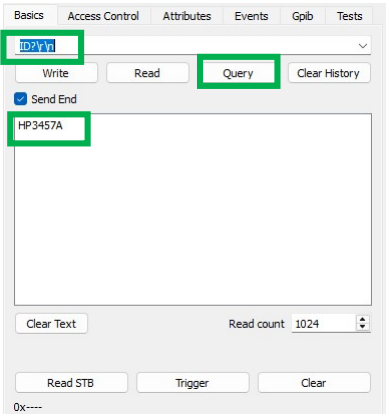
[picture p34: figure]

The green highlighted section shows the response and the log window shows no timeout, but VI SUCCESS on the read and write instructions. This confirms that the communication is working.

As mentioned, most equipment does not require an adjustment of the read termination as they generate an EOI on read to terminate.

Note: Above items show the usage using RSVisaTester in an interactive way. If you just want to access your instrument using Python, this is typically not required, but it is a nice tool to debug your instrument. It can also create logs of your visa instructions which you execute using Python & PyVisa which is a powerful too for debugging during development phase.

## 5 Usage with Python

If all above steps succeeded, we can start using the UsbGpib device with python. The following sections show a step-by-step guide using python interactively. You can of course also create a script.

### 5.1 Scanning for connected devices

Start python and import PyVisa.

Import PyVisa:

List available measurement devices:

In above output you can see, that one instrument is found. The returned array contains a single string which is the so called ”ressource string” of the device. As mentioned before, that resource-string will be different, depending on your actual GPIB device configuration and serial number of the UsbGpib Adapter.

In case you see multiple devices being returned – the ones containing texttt0x03EB::0x2065 are the one from the UsbGpib Adapter.

Open the instrument (adjust the string to the one which was returned by the previous command):

If successful, no error is shown, and we can interact with the instrument using the ”inst” object.

If your instrument is SCPI compliant, you can now simply execute instr.query(’*IDN’) to read the instrument name or better identification string over GPIB.

As the used HP3457a is not SCPI compliant and requires specific termination settings, we apply those settings now first during the next steps.

To set \n termination for that instrument, execute those 2 lines:

Afterwards the read termination will be set to \n and queries or reads will be successful from this instrument:

You can now write to the instrument using commands like inst.write() for ASCII strings, inst write binary values to send raw binary data, among other variants.

To read data use inst.read() for ASCII strings, inst.read binary values(), etc.

The previously used inst.query command is just a combination of write followed by read. It will write the provided text strings (here ‘ID?’) to the instrument, followed by a read and returns the information.

To disconnect from the instrument, execute inst.close().

### 5.2 Some more pyvisa Hints

### 5.2.1 Stripping of read termination

An instrument which returns read termination, like the one used here will contain in reads always read termination. As visible in previous example, the ID? Query answer is terminated with \r\n.

Pyvisa can ”strip away” the \r\n termination automatically, if you specify a read termination to it:

This read termination setting is just a string handling within PyVisa, it does not set any read termination of the GPIB adapter itself. So it is no substitution of the previous TERMCHAR and TERMCHAR EN attributes which were used before.

### 5.2.2 Automatic write Termination addition

As you saw in the examples, the query command string included \r\n as termination. PyVisa can add this automatically, if you specify a write termination, making the code a bit easier to read.

Again, write termination is just a string based handling. Before the string gets sent to the device, the set write termination string is added to the message internally.

### 5.2.3 Timeout handling

Some instruments can take a longer time to return a response. This can e.g. happen for large data transfers. There are sophisticated ways using service requests that an instrument can signal with interrupts its readiness, but sometimes it is easier to just increase the timeout.

The property timeout will return the current timeout in units of milliseconds.

2000 means 2000ms which is 2s. This is the default timeout value.

You can change it by assigning another number to it. To increase the timeout to 5s, execute:

Don’t forget: Timeouts can indicate actual errors like an unsupported command; It can also indicate wrong write or read termination but also be just simply the instrument taking a longer time to process a command.

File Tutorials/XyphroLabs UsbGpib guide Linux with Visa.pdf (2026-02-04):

1

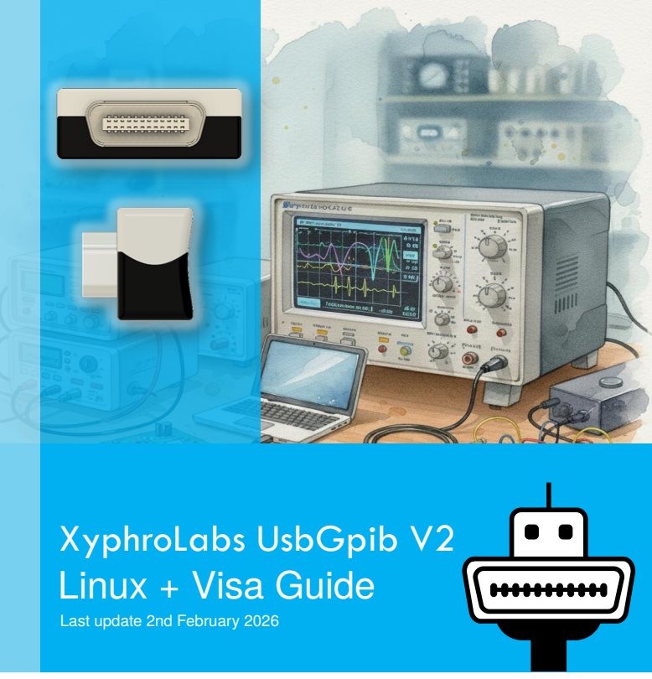
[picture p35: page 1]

XyphroLabs UsbGpib V2
Linux + Visa Guide

Last update 2nd February 2026

# Contents

2

## 1 Introduction

## 2 Introduction

This document provides guidance on utilizing the UsbGpib adapter with Linux, specifically in conjunction with Python.

While the UsbGpib Adapter is no different to other UsbTmc instruments, because it exposes a standard UsbTmc interface, these instructions are mainly intended for first time users of Instrument control to give a kick-start in using it and setting it up.

Various approaches are available, as the USB GPIB Adapter operates via USBTMC. Users may directly employ the USBTMC Linux driver and interface through C or other programming languages, use pyvisa-py or pyvisa-usbtmc (which leverage a more direct access to the USB devices), or adopt the standard practice of engaging a Visa provider.

The installation process detailed herein uses R&S Visa, which is controlled from Python using Pyvisa. R&S Visa offers a standardized interface compatible with PyVisa, Lab-VIEW, and other software packages. Visa providers are also available from other companies like NI or Keysight, but R&S Visa is the Visa provider which requires the least amount of hard disk space ( 35MB). Most other visa providers install Gigabytes of files on your computer, which is not required nor helpful.

The primary objective of such a Visa is to deliver a unified API for managing multiple types of interfaces - regardless of their physical connection (USB, different Ethernet protocols, Serial port) - and it is widely used as a standard tool used for automating test and measurement setups.

For demonstration purposes, Ubuntu 24.04.3 LTS serves as the platform in this guide. A fresh installation was made to create this guide, to ensure that all dependencies are captured.

## 3 SW setup

### 3.1 Installation of R&S Visa

Please visit https://www.rohde-schwarz.com/us/applications/r-s-visa-application-note 56280-148812.html (https://www.rohde-schwarz.com/us/applications/r-s-visa-application-note_56280-148812.html)

In case this links does not work in future, use a google search for ”R&S Visa Download”
to find the most recent correct link.

Download the RS Visa Setup for Ubuntu:

This document is part of Xyphro UsbGpib (https://github.com/xyphro/UsbGpib) project | Page — 3

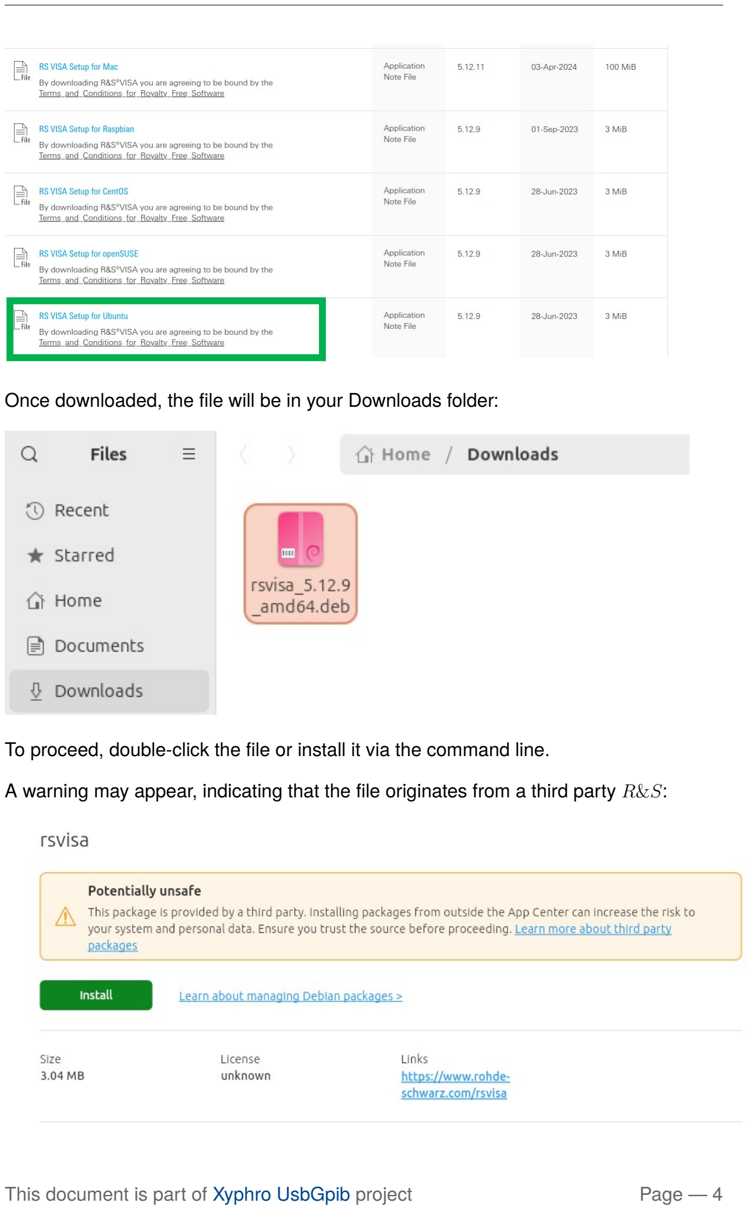
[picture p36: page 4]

Once downloaded, the file will be in your Downloads folder:

To proceed, double-click the file or install it via the command line.

A warning may appear, indicating that the file originates from a third party R&S:

Select ”Install” and confirm your intention to proceed. When prompted, enter your user password to grant SUDO privileges.

Upon completion of the installation, three new applications will become available:

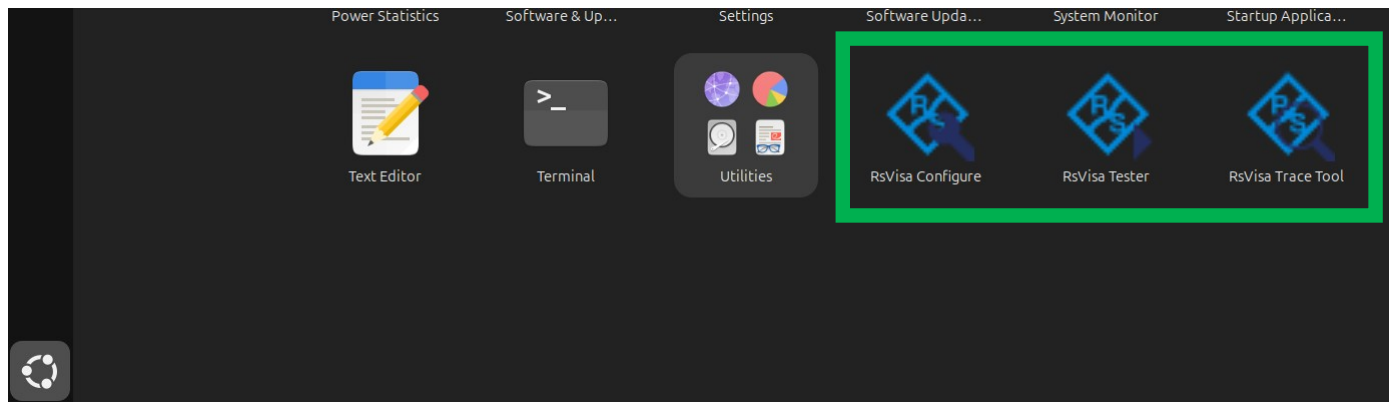
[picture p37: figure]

Although not strictly required, RsVisa Tester is a graphical user interface application that facilitates instrument scanning and enables basic read/write tests, making it particularly valuable during initial system bring-up.

Note, that the release notes of R&S Visa contain also installation instructions – also for Windows, Mac OSX or other Linux flavors; Even Raspberry PI with Raspbian.

We will continue with the hardware setup in the next section.

### 3.2 Installation of PyVisa

PyVisa is necessary for interfacing with the instrument using Python. PyVisa will interface to the visa provider which then interfaces to the instrument.

This guide utilizes Python 3. Please ensure that both Python 3 and pip3 are installed prior to proceeding.

To ensure that execute from terminal:

sudo apt-get install python3 python3-pip python3-pyvisa

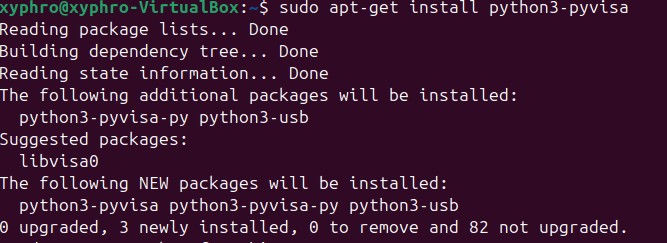
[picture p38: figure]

(The actual output will vary depending on which packages are already installed on your machine)

All above steps are one-time actions.

Let’s proceed to the HW setup.

## 4 HW setup

In this example I use a HP3457A Multimeter with GPIB:

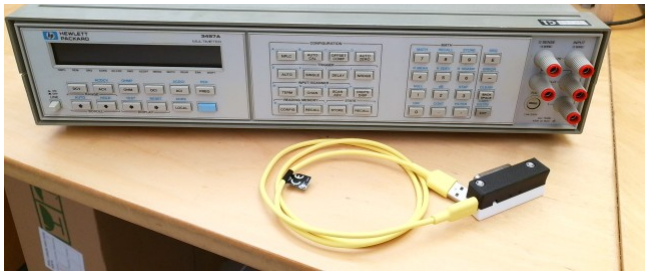
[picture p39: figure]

Initial one-time steps:

- Connect it to power but keep it powered off.
- Connect the USB GPIB converter to the GPIB port and the USB cable to your PC. Note: The PC won’t detect a USB device yet as the instrument is powered off. This is a feature to prevent inaccessible devices are showing up on your PC.

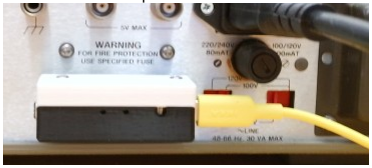
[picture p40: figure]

- Power on the GPIB device.
Note: The PC does now detect a new USB Device.

It is not necessary to follow a specific sequence for connecting or disconnecting devices, powering them up or down, and similar actions. However, the following order is provided to present the instructions in a logical, step-by-step manner. As indicated in the procedure, the adapter will only be detected by a PC when the instrument is powered on and GPIB functionality is enabled.

The adapter monitors USB connections to identify whether any devices with GPIB enabled are present.

Regardless of the specific GPIB address, it systematically scans all available addresses on its GPIB port. Upon detecting a responsive GPIB address, the adapter enumerates the device on the USB interface, thereby enabling access from the PC.

## 5 First interaction with the instrument

### 5.1 Confirming that the USB device is detected

The following steps are not mandatory but can be beneficial for debugging. They verify that the USBTMC device is recognized by the PC and that the instrument is properly powered and configured for GPIB communication.

Execute from terminal:

lsusb

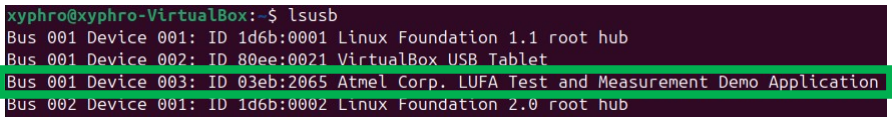
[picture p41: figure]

The output above displays an entry with VID:PID 03eb:2065, identifying the USB GPIB Adapter.

This device will appear when all connections are established according to the HW-Setup section, GPIB functionality is enabled on the instrument, and the instrument is powered on.

Further information can be seen when executing:

lsusb -v

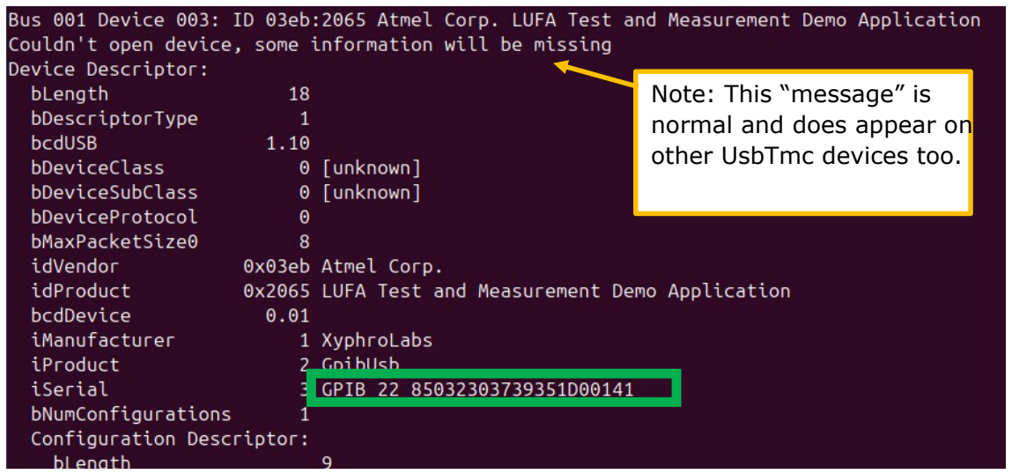
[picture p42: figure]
Note: This “message” is normal and does appear on other UsbTmc devices too.

The green highlighted area displays the USBGPIB adapter serial number. In this instance, it indicates the detected GPIB address, which is 22. The subsequent numbers represent a unique serial number, allowing users to distinguish between multiple USB GPIB adapters when identical GPIB addresses are assigned to different instruments.

Please note that the GPIB adapter may also display the instrument name instead of the GPIB address if the AutoID feature is enabled.

### 5.2 Testing if the instrument is detected by R&S Visa

You can close open terminal windows, etc.

Start the RsVisa Tester application:

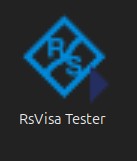
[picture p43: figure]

After starting the below GUI window is shown:

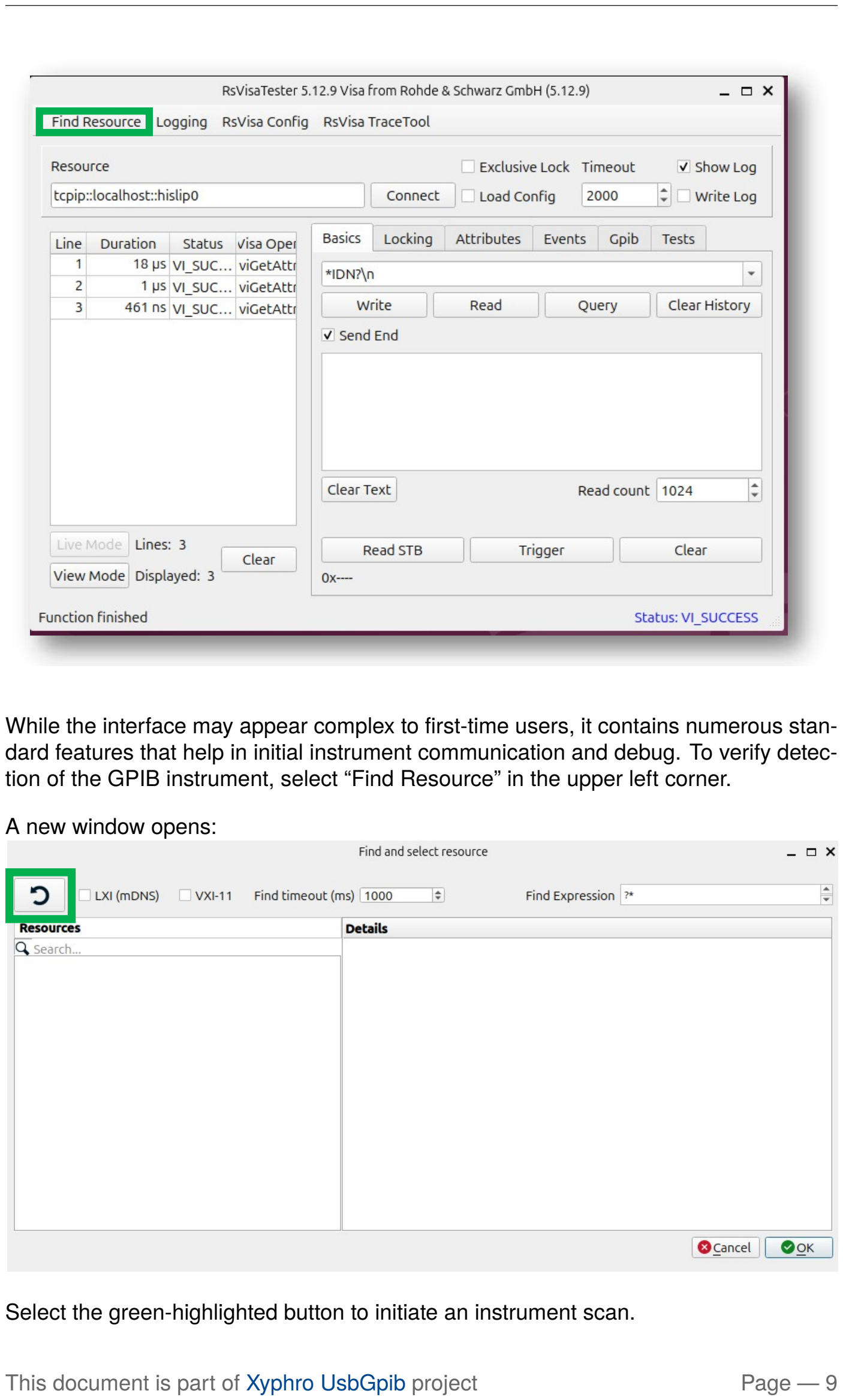
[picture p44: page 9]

While the interface may appear complex to first-time users, it contains numerous standard features that help in initial instrument communication and debug. To verify detection of the GPIB instrument, select “Find Resource” in the upper left corner.

A new window opens:

Select the green-highlighted button to initiate an instrument scan.

If no USBTMC devices are detected, please refer to the section titled ”Why are no USBTMC devices found?”.

This situation typically occurs during initial installations, and the section provides guidance on how to enable device availability on a persistent basis.

If the operation is successful, a USB device should be visible as shown. Please note that the previously displayed serial number forms part of the resource string.

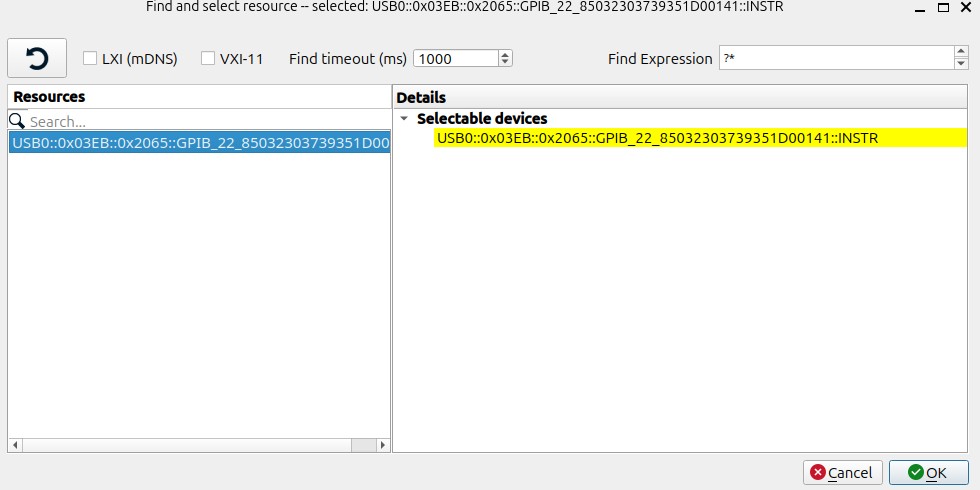
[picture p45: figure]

Select the found devices and click OK.

Now you are back to the main window. The ressource field should show the previously detected device:

Now you can click on the connect button to connect to the instrument.

The log lines should show a successful connection:

The right side of the main GUI window now gives the ability to interact with the instrument:

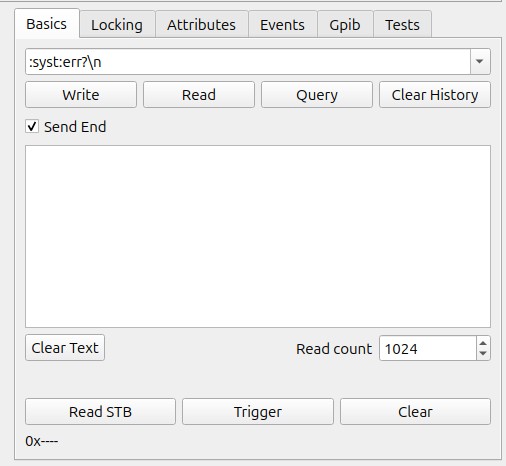
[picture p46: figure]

If your instrument supports the *IDN? query, you may enter “*IDN?” in the designated field and click Query; the instrument’s response will then be displayed.

However, many legacy instruments do not support this command and may also lack EOI termination during read operations, which can lead to unsatisfactory timeout errors giving the impression that communication is not possible

For this reason, I have prepared this manual for the older HP3457A, which requires some additional configuration steps. These requirements are not unique to this USB GPIB Adapter - they apply to any GPIB adapter and are dictated by the instrument itself.

The equipment’s GPIB programming manuals offer detailed guidance on configuring the appropriate settings, and additional support is available in the troubleshooting section if necessary. For certain legacy instruments, these settings may be challenging to locate and may require some degree of experimentation.

Point #1: The used HP3457A does default wise not terminate with EOI, but with \n. A query will result in a timeout.

To enable \n termination, go to the Attributes tab, select VI ATTR TERMCHAR EN, enter 1 in New AttributeValue field and click on SetAttribute.

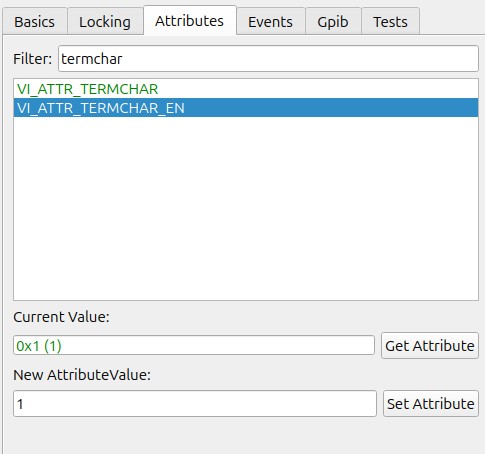
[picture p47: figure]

This is a non permanent (so non volatile) setting, which is only valid for this currently active session.

The attribute VI ATTR TERMCHAR does select the actual termination character which is used to detect a termination of read GPIB messages. Default wise it is 0xa (10), which matches \n and is for most older HP instruments the correct settings.

Point #2: HP3457A does not support the *IDN? SCPI standard query. Older HP Equipment required "ID?\r\n" as query.

After adjusting the termination settings as stated in Point #1 you can try to execute the ID?\r\n query:

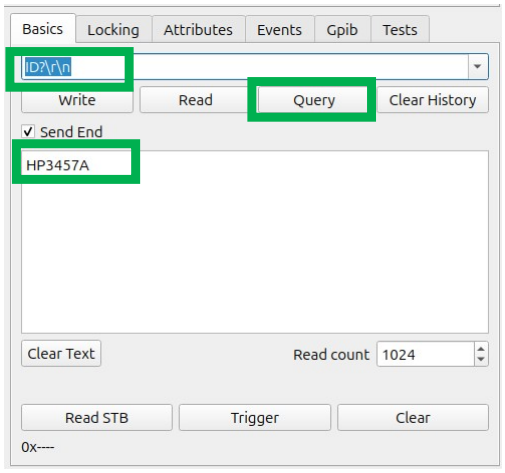
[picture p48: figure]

The green highlighted section shows the response and the log window shows no timeout, but VI SUCCESS on the read and write instructions. This confirms that the communication is working.

As mentioned, most equipment does not require an adjustment of the read termination as they generate an EOI on read to terminate.

Note: Above items show the usage using RSVisaTester in an interactive way. If you just want to access your instrument using Python, this is typically not required, but it is a nice tool to debug your instrument. It can also create logs of your visa instructions which you execute using Python & PyVisa which is a powerful too for debugging during development phase.

### 5.2.1 Why are no USBTMC devices found?

A ”Find Resource scan” performed on RsVisaTester may yield no detected instruments. Furthermore, each time the scan button is pressed, the main GUI screen’s log displays entries indicating this outcome:

This message indicates that no instruments were detected. However, this situation may occur even when an instrument is properly connected, but permissions to usbtmc devices are not properly set up yet on the machine and access would only work with SUDO rights.

To set them correctly, add them to the usbtmc.rules file:

Execute:

sudo nano /etc/udev/rules.d/99-usbtmc.rules

Add this line to the file:

SUBSYSTEM=="usb", ATTR{idVendor}=="03eb", ATTR{idProduct}=="2065", MODE="0666"

The 2 highlighted parts are the vendor ID and product ID, which were shown earlier in the lsusb output. For this USB GPIB adapter, the numbers will never change and always
be the same. But in case you want to support other USB connected measurement instruments, adjust those numbers.

After adding this line and saving with ¡CTRL¿+O and exciting, execute:

sudo udevadm control --reload-rules
sudo udevadm trigger

or reboot the machine.

Also disconnect and reconnect the USB cable once after executing those lines.

Note: Instead of using the described line, you can also add this line:

KERNEL=="usbtmc[0..9]", SUBSYSTEM=="usbmisc", MODE="0666"

It will set usbtmc0 to usbtmc9 devices access rights, without requiring to specify a vendor and product ID, thus is a bit more generic.

## 6 Usage with Python & PyVisa

If Python and PyVISA have been installed as outlined in previous sections, you should now be able to communicate with your instrument. This section provides suggestions and example code snippets to assist with this process.

While step-by-step interactive usage within the Python console is demonstrated here, the provided snippets may also be integrated into standalone Python scripts as needed.

### 6.1 Scanning for connected devices

Start python3:

Import pyvisa:

And create a visa resource manager (which allows listing resources at a later stage):

When you enter: rm.list ressources() all available visa resources will be shown:

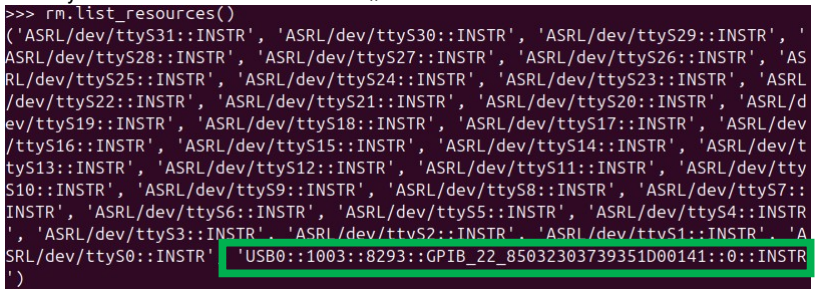
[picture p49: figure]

Our instrument is also part of this, as highlighted with the green box.

To open the instrument, type:

Your actual instrument name (called the resource string) will vary of course.

In case a ”[Errno 16] Resource busy” error is shown, it is possible, that it is e.g. still open in RsVisaTester – ensure that you are disconnect there. It is also possible, that the device is still open from previous python experiments – in that case execute inst.close() before or create a new python session.

If successful, no error is shown, and we can interact with the instrument using the ”inst” object.

If your instrument is SCPI compliant, you can now simply execute instr.query(’*IDN’) to read the instrument name or better identification string over GPIB.

As the used HP3457a is not SCPI compliant and requires specific termination settings, we apply those settings now first during the next steps.

To set \n termination for that instrument, execute those 2 lines:

Afterwards the read termination will be set to \n and queries or reads will be successful from this instrument:

You can now write to the instrument using commands like inst.write() for ascii strings, textttinst write binary values to send raw binary data, among other variants.

To read data use inst.read() for ascii strings, inst.read binary values(), etc.

The previously used inst.query command is just a combination of write followed by read. It will write the provided text strings (here ’ID?’) to the instrument, followed by a read and returns the information.

To disconnect from the instrument, execute inst.close().

### 6.2 Some more PyVisa hints

### 6.2.1 Stripping of read termination

An instrument which returns read termination, like the one used here will contain in reads always read termination. As visible in previous example, the ID? Query answer is terminated with \r\n.

Pyvisa can ”strip away” the \r\n termination automatically, if you specify a read termination to it:

This read termination setting is just a string handling within pyvisa, it does not set any read termination of the GPIB adapter itself. So it is no substitution of the previous TERMCHARand TERMCHAR EN attributes which were used before.

### 6.2.2 Automatic write Termination addition

As you saw in the examples, the query command string included \r\n as termination. PyVisa can add this automatically, if you specify a write termination, making the code a bit easier to read.

Again, write termination is just a string based handling. Before the string gets sent to the device, the set write termination string is added to the message internally.

### 6.2.3 Timeout handling

Some instruments can take a longer time to return a response. This can e.g. happen for large data transfers. There are sophisticated ways using service requests that an instrument can signal with interrupts it’s readiness, but sometimes it is easier to just increase the timeout. The property timeout will return the current timeout in units of milliseconds.

2000 means 2000ms which is 2s. This is the default timeout value. You can change it by assigning another number to it. To increase the timeout to 5s, execute:

Don’t forget: Timeouts can indicate actual errors like an unsupported command; It can also indicate wrong write or read termination but also be just simply the instrument taking a longer time to process a command.

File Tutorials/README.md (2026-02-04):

# Tutorials

I am busy creating several tutorials starting first with basic first bringup instructions for different operating systems. Those instructions are mostly for new users in the Test & Measurement domain and might be too excessive for more experienced users.

In case you have ideas/demands for certain topics to be turned into tutorials, feel free to contact me: Xyphro@gmail.com

The documentation is now provided in Markdown, with an option to view the corresponding PDF version directly from each page. After opening any of the links below, you can download the PDF using the download button in the top‑right corner.

UsbGpibV2 user manual:
* [UsbGpibV2 Manual](UsbGpibV2_manual.md)

Startup guides:
* [Linux with Visa and Python startup guide](XyphroLabs%20UsbGpib%20guide%20Linux%20with%20Visa.md)
* *Upcoming: Linux without Visa and Python-usbtmc module*
* *Upcoming: Linux without Visa and Python pyvisa-py module*
* [Windows with Visa and Python startup guide](Using%20XyphroLabs%20UsbGpib%20adapter%20with%20Windows.md)
* *Upcoming: Basics principles and hints for Test & Measurement automation*
* *Upcoming: Electrical layer aspects for GPIB*

---
This page is from XyphroLabs UsbGpib project: <a href="https://github.com/xyphro/UsbGpib" target="_blank">https://github.com/xyphro/UsbGpib</a>

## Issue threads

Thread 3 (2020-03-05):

Bootloader stop working after upload TestAndMeasurement.bin (with a workaround)

DaviVolcan, 2020-03-05:
i followed the flassing instructions as in readme...
im using an arduino as isp and avrdudess (GUI for avrdude) to upload the bootloader... then i disconect the programmer and conect via usb the board... the mass storage shows up as spected but after delete flash.bin and replacing bt TestAndMeasurement.bin then porwercicled the board... i cant get bootloader to work when jumping the correct isp pins...
i tried several boards whit no luck... But for some reason to test the boards i decide to burn the arduino leonardo bootloader in one of the boards... i got is to work... then i tried again the flahsing procedure for this project... Now everthing works! i think that arduino ide programmed the fuses. now i can reboot a billion times whitout any issues...

Wilts01, 2020-04-19:
Hi, I have the same problem.  I used a USBASP as a programmer with avrdude command line.  I uploaded the boot loader and connected via USB.  I showed up as a new drive and I copied across TestAndMeasurement.bin to replace flash.bin.  However, when I connect it up to a GPIB port, it doesn't show up in either Device Manager or VISA.  The led is just very faintly on and if I short the ISP pins, it doesn't show up as a USB drive.  What am I missing here?  Should I try burning the arduino leonardo bootloader?  If so, how do I do that?

Thanks  Paul

Xyp, 2020-04-19:
Hi Paul, can you share the fuse settings? Is it possible, that the jtag interface is not disabled in the fuse settings?
Best regards,
Kai

Wilts01, 2020-04-19:
Ah found out.  I was able to use the Arduino IDE to programme the Arduino Bootloader for a Leonardo board using my USBASP.  Even though it claimed to have failed, it did enough to allow me to reinstall the proper bootloader and get it working.

Wilts01, 2020-04-19:
Kai, How do I do that?  Sorry, not done a lot of AVR work before
Paul
PS - I did manage to get it working with Davi's workaround

Wilts01, 2020-04-19:
I installed the original bootloader with the command line avrdude -c usbasp -p m32u4 -U flash:w:Bootloader.hex  so didn't do anything special with fuses

xyphro, 2020-04-19:
Hi Wilts01,

if you have it working, very good.

Actually this whole thing was never done using any Arduino stuff (I am one of those, that programmed the first AVRs, when there was not even a C compiler available).
I suspect, that the reason, why using the Arduino bootloader is, that the Arduino bootloader programming sets Fuses correctly. Those fuses select, if the Jtag interface is on or off (it should be off), the clock source (shoud be High frequency XTAL), boot sector size, ...
Typically this is done using additional parameters to avrdude.

Best regards,

Kai

Wilts01, 2020-04-19:
Thanks Kai.  Do you have a definitive list of what the fuses should be?  BTW, I have created a BOM in Excel if you would fine that useful.

Cheers

Paul

Xyp, 2020-04-20:
Hi Paul,

I will take this up in the readme im the scope of this week. Providing a clear description of how to do the 1st program with correct commandline parameters to avrdude is something required here to help others to create their own copies of this and avoid buiding up frustration.

Best regards,

Kai

Xyp, 2020-04-20:
Sorry, forgot 1 thing: an excel bom is valued. Can you add it yourself? To the repository? Otherwise you can mail it to xyphro at gmail.com and I will add.

motechsolutions, 2020-04-21:
Just finishing building my first UsbGpib and i found the same problem when using a USBasp programmer.
After reading the above comments i looked at the fuses the Arduino IDE used to write the arduino leonardo bootloader and added these to my bat file and now my UsbGpib working :)

I also found i needed to install the Keysight IO Libraries Suite for Windows 10 to recognize the UsbGpib

If it helps anyone my .bat file is

@echo off
title code_burnATMEGA32U4
echo !!Welcome to usbasp programmer!!
echo !!Programing Fuses!!
avrdude -c usbasp -p m32u4 -e -Ulock:w:0x3F:m -Uefuse:w:0xcb:m -Uhfuse:w:0xd8:m -Ulfuse:w:0xff:m
pause
echo !!Writing BootLoader!!
avrdude -c usbasp -p m32u4 -U flash:w:BootLoader.hex
pause

motechsolutions, 2020-04-21:
Can anyone recommend any software i can use to get voltage reading data from a HP 3457a.
My plan was to read the data using pyvisa then post the readings to Grafana via MQTT
Problem is im a newbie at both GPIB and pivisa, any help would be much appreciated.
The hardware route i was thinking of was UsbGpib to Raspi zero then post via wifi to MQTT server and on to Grafana

xyphro, 2020-04-22:
Hi!

Thanks for sharing the fuses. Was just struggling yesterday night to get my AvrDargon up and running, so thanks for your help!

You have luck: I own the HP3457a too :-)
There was a major hurdle to get it up and running, because the EOI termination is default wise not on after power on, which is mainly because it is an older test equipment.
However: Once I found the cause, I got the solution. Sending the command "END ALWAYS" enables it.
Get an operation manual for the HP3457a from the web to see more commands. Note: The HP3455a has a completely different comand set, so really ensure you get the manual for the HP3457a.

Below a freshly tested python (3.x) snippet to read out the voltage:
-----------8<-----------8<-----------8<-----------8<-----------8<-----------8<-----------
import pyvisa as visa

rm = visa.ResourceManager()
VM = rm.open_resource('USB0::0x03EB::0x2065::GPIB_22_7583932313435131D140::INSTR') #Note: Put here your VISA ressource string for the multimeter, above is mine, your's might be different

VM.write('END ALWAYS') # Turn on EOI generation (VERY IMPORTANT!)
VM.write('DCV') # Switch to DC volt mode with AUTO range
voltage = float(VM.read().strip()) # Read voltage as ASCII string and convert to float
print(voltage)

motechsolutions, 2020-04-22:
Hi xyphro
Thank you for this info, its just saved me hours of hunting google.
Ill give these commands a go and let you know how i get on.
Have you tried your UsbGpib interface with IanJ python script for the HP 3457A, looks really good if i can get it working :)
https://www.eevblog.com/forum/metrology/3458a-logging-via-windows-app-revisited/

motechsolutions, 2020-04-23:
Hi xyphro
Quick question: What command do you use to set the NPLC to 100, ive tried
VM.write('NPLC 100') but i get a timeout error but if i use VM.write('NPLC 10') which i believe sets the Power line cycles to 10 or do i need to increase the command timeout in pivisa, if so how to i do that?
so far my script looks like

```
import pyvisa as visa
import paho.mqtt.client as mqttClient
import time

rm = visa.ResourceManager()
VM = rm.open_resource('USB0::0x03EB::0x2065::GPIB_22_75935313330351D01201::0::INSTR') #VISA ressource string for the multimeter.
VM.write('END ALWAYS') # Turn on EOI generation)
VM.write('DCV') # Switch to DC volt mode with AUTO range
VM.write('NPLC 100') #Set power line cycles to 100
VM.write('NRDGS 1') #Set number of readings per trigger

def on_connect(client, userdata, flags, rc):
    if rc == 0:
        #print("Connected to broker")
        global Connected                #Use global variable
        Connected = True                #Signal connection
    else:
        print("Connection failed")
Connected = False   #global variable for the state of the connection

broker_address= "********"
port = 1883
user = "********"
password = "********"

client = mqttClient.Client("hp3457a")               #create new instance
client.username_pw_set(user, password=password)    #set username and password
client.on_connect= on_connect                      #attach function to callback
client.connect(broker_address, port=port)          #connect to broker

client.loop_start()        #start the loop

while Connected != True:    #Wait for connection
    time.sleep(0.1)

try:
    while True:
        voltage = float(VM.read().strip()) # Read voltage as ASCII string and convert to float
        client.connect(broker_address, port=port) #connect to broker
        client.publish("/sensors/HP3457A/dcV",voltage) #Publish to MQTT Broker
        #print(voltage)
        time.sleep(5)

except KeyboardInterrupt:
```

Xyp, 2020-04-23:
Hi!
Can you mail be, as this is off topic to the original issue? Xyphro at gmail.com
Will check it out.
Best regards,

Kai

motechsolutions, 2020-04-23:
Will do :)

xyphro, 2020-04-23:
I have updated just updated the instructions using the input from motechsolutions.
Thanks! Closing the ticket now.

Closed 2020-04-23.

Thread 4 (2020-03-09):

How to compile it?

DaviVolcan, 2020-03-09:
could you describe a litte of the process and the tools that a ineed to compile a testandmeassuarament.bin file? i want the resource name related only to the gpib adress or to each adapter to have a specific name...   thank you!

Xyp, 2020-03-09:
Hi Davi,

This is actually very easy to realize. Will add an option to select during runtime the intended behaviour, so either the one we have now (name built by IDN string) or gpib address. Actually assigning a name yourself is doable too without a lot of effort, need to make up my mind here on which of the 2 strategies is better.

Will furthermore share how to setup a build environment in the evening.

Best regards,

Kai

DaviVolcan, 2020-03-10:
Awesome! im really interested in you project because i do think that more people would benefit from it, people can even do more flavors... when a project demands certain features or just by personal preferece...
your work can reach a lot of people! i do have friends that are ordering pcbs from JLC to build some adapters!

DaviVolcan, 2020-03-10:
Awesome! im really interested in you project because i do think that more people would benefit from it, people can even do more flavors... when a project demands certain features or just by personal preferece...
your work can reach a lot of people! i do have friends that are ordering pcbs from JLC to build some adapters!
when how to compile it be clarified... more people can play and benefit!
Best regards,
Davi

Xyp, 2020-03-10:
Hi!

Due to high workload I'd like to take a pragmatic approach and provide you
my build environment as a first step. I will only manage this weekend to
look into describing it better. And don't want to block you.
Can you let me somehow know your email address? E. G. Mail once to xyohro
at gmail dot com?

Best regards,

Kai

DaviVolcan <notifications@github.com> schrieb am Di., 10. März 2020, 15:03:

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

madyn999, 2023-04-19:
Possibly reviving a new thread.  I'm reasonably accomplished with ST Micro's CubeMxIDE.  Used to do a lot of AVR and AVRXMEGA a while back, put that aside to go to STM32 which had more FLASH and RAM.

I have AVRStudio (Microchip) 7, but it seems a bit of a difficult environment to work in, once one has managed to figure out ST MICRO's eclipse based code.

Did you ever use the AVR Studio tools?  Could you share the setup?

I'd like to use the adaptor with a TM5006 chassis.  It parallels up to 6 (possible) GPIB controllers.  I'd need to get the software to compile properly before I start to modify it.  What I'd like is to modify the basic code to add up to (say..... 8?) possible GPIB devices.

If needed, I can easily (it says here) take the USB stack (I think), put it on an ARM processor, let it do a lot of the heavy lifting, and then use I2C to go to the AVR, which may have the appropriate GPIB hardware interfaces.  Ideally, the hardware would support the 6-8 interfaces and the changes would be only software.

I wouldn't mind investigating this, but it's an unfamiliar environment so far.
Harvey

xyphro, 2023-04-19:
Hi Harvey,

I use the build environment which is provided by the LuFa system which is makefile based.

I think this will help you:
http://www.fourwalledcubicle.com/files/LUFA/Doc/140302/html/_page__getting_started.html

It is not an avr studio IDE based project.

Best regards,

Kai

xyphro, 2023-04-19:
In case you are not used to makefile systems it might be easier to do what you suggest: Use an stm32 and port it and use something like NCA9555 with a i2c level shifter to interface to the 5V domain gpib target. Or build 8 of those circuits and put a usb port on the back side. Gives also the flair of a modern system then :-)

Closed 2023-05-03.

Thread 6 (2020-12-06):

ATMEGA16U4 support

ra1nb0w, 2020-12-06:
Hi,
first of all, thank you very much for sharing this project!
Unfortunately, I soldered an atmega16u4 without re-reading the readme :(
I rebuild `TestAndMeasurement` for that micro and flashed it without bootloader since I have only 16KB of flash (with fuses as suggested). The led works correctly but I don't get the usb descriptor Id and the usb is not recognised. I think that the bootloader set those values but I don't know too much about LUFA. Is there a way to use 16u4 without desoldering it?
thank you

irbsurf, 2021-06-11:
Hi, guess what I did the same except I haven't soldered it yet! Now the correct IC is out of stock! Did you make it work in the end?
Thanks,
Andrew

ra1nb0w, 2021-06-12:
No. At the end I substituted the IC.

Xyp, 2021-12-02:
It would be possible to Support atmega16U if the bootloader is removed. So you'd loose Update capability to Users that don't have a programmer/skills.
Well, right now everybody needs to bring these tools with him... If I manage to get time I can make something, right now it is unfortunately just extremly limited :-(

Closed 2021-06-12.

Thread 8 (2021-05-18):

Python VISA support?

ami3go, 2021-05-18:
Hi. Thanks for sharing it.
Project looks good. I have some suggestion to make it more robust.
I think add something like ESD protection for pins.

ami3go, 2021-05-18:
I found that python is actually supported. Great!

Xyp, 2021-05-18:
The way it is implemented it is independent on with which software you control it, because it hooks up to visa. Python and matlab are my main preference for automating measurement equipment so what you found is fully correct :-)

ESD... Yeah, can be done. The AVR already has protection diodes internally, it all comes down to the targeted model you want to protect it against.

ami3go, 2021-05-19:
USB protections probably STF202-22T1G or it's kind
Also when i was thinking to build it myself i saw GPIB bus drivers, like:
SN75ALS160
SN75ALS161
On the  one hand good to have them, on the other probably it is better to keep BOM cheap and use several of devises instead one, if control more then one piece of equipment.

Xyp, 2021-05-19:
Bus drivers I kept indeed on purpose out for the methothology of 1 usb port 1 GPIB device as stuff is cheap. Bus drivers add cost and secondary level complexity. Not saying they are wrong, but with above mindset not required.

Usb protection can certainly be added. If somebody does not want it, they can simply leave it away.
Esd protections are only as good as the testing behind it. Adding an untested ESD protection is not enabling to make claims on ESD safety.
Adding a pad for a commonly available choice is not hurting at all.

Best regards,

Kai

ami3go, 2021-05-20:
I will order current version. I think i could test one assembly for ESD as I have access to test lab on work. Let see if need additional protection or not.

Xyp, 2021-05-20:
That would be nice. I can also test agains different models, just in this covid times more effort. Order a few more AVRs to replace after test :-P

Closed 2022-11-24.

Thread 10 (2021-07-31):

Device descriptor request failed

wangwei357, 2021-07-31:
hi,
I had used your BootLoader.hex to program the microchip. but when i reconnect my computer . there is no disk show in my PC. and the Device Manager will display
 “ Unknown USB device （Device descriptor request failed）” ,What possible causes ？
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

xyphro, 2021-07-31:
Hi Wanwei,

Did you program the fuses also as described in the readme.md? This would
cause exactly this issue.

Let me know, curious what the cause is.

Best regards,

Kai

wangwei357 ***@***.***> schrieb am Sa., 31. Juli 2021, 15:55:

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

wangwei357, 2021-08-03:
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

@xyphro  hi
    It's my fault. it may cause when program the the fuses without usb connected.
   But  i  had  another issue . when there are multipile gpib driver in gpib network . There is only one driver can discover.  It's  OK for current fwamework?

xyphro, 2022-11-24:
The framework is made to just support a single device.
I think physically it would be possible to drive multiple GPIB instruments, but the software was made with the intention to just support a single one.

Closed 2022-11-24.

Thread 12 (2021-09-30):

Is it possible to port this code to Arduino Pro Micro?

Maxwell3e8, 2021-09-30:
It would be nice to be able to use just the standard Arduino Atmega32u4 board. It looks like just a few GPIB pin assignments need to be moved and interactions with the bootloader?

christakahashi, 2021-12-04:
I'm considering the same thing, mostly because I can't find any 32u4's during this shortage.  You can buy clone pro micro's that are a bit bigger and bring out all the pins.  I assume keeping port D mapped to DIO 1:8 is efficient and remapping the unavailable portD pins would be a bit kludgy.

Xyp, 2021-12-04:
You can also desolder the atmega32u4 from an arduino Board and put it here :-)
Funny enough, I also thought it is hard to get atmega32u4, but bought just läßt week a few from Mouser.

christakahashi, 2021-12-05:
I considered that too, but all the pro micro's I see use the QFN package, which I don't want to fiddle with.

Xyp, 2021-12-05:
But in case you are willing to go there I volunteer to Layout a QFN housings variant.
Or are there any other 5V MCUs good available right now with USB Support?

Maxwell3e8, 2021-12-05:
Personally I don't want to deal with making circuit boards, ordering individual components or installing new IDEs.  A  popular cheap board available on E-bay that can be programmed with Arduino IDE would be much easier to setup, even if it is slightly slower.

Xyp, 2021-12-05:
I understand if this has preferences if you don't want to solder SMD components. You can try porting, it should not be too difficult if there is a good USB stack that you can use for Arduino. I won't do Arduino Support myself as it is already working without it.

christakahashi, 2021-12-05:
I actually laid out a QFN variant last night for assembly in china, since I hate soldering that package.  But they don't have any crystals available.  I asked them if they were going to get a part in stock or can add one, so we'll see.

It's laid out in KiCAD (which has gotten so much better since CERN started adding enhancements).  I'm using the outline imported from your gerbers and the same connector locations so hopefully its compatible with your case.  Assuming I find a crystal, I'm going to order a few and double check my layout is okay and if you want I can add a push request with the layout.

Xyp, 2021-12-06:
Good Action Chris. Looking forward for the pull request!
Did you use the JLC PCB assembly service?

Xyp, 2021-12-06:
I'd really need somebody to show me 1:1 Kicad. What I saw looked so much better to what I knew from years ago.

christakahashi, 2021-12-06:
Yeah I've been using Chinese services for years when selling low volume pcbs.  This will be my first JLC PCB Assembly but their offering has gotten so much better than the last place I used that I have to try it.

Kicad is well worth learning these days especially after autodesk took over eagle.  Most of kicad is very intuitive but its a bit harder coming from eagle since eagle is so weird.

christakahashi, 2021-12-22:
PCBs came in yesterday.  3 days to make two weeks to ship, because I didn't want to pay for good shipping.  Seems to work great!  I'm going to clean up the silk layer a bit to fix some minor "issues"  and send in a pull request.

KiCAD is on the verge of releasing its 6.0 which has a lot of improvements I love (including fixing some annoying UI oddities).  Among them is (FINALLY!) embedding symbols in the schematic file.  This means that sharing schematics files isn't a path and file versioning nightmare.  I did do it in 5.x originally though, so would you prefer I attempt to package up the 5.x files or just go 6.0.  The tradeoff is that the 5.x files may be hard to import, but KiCAD 6.0 is not technically released, though another feature of 6.0 is that it can coexist with other versions (not previously possible).  I've loving the 6.0 RC so that's what I think is best.  I can add both too but I don't want to make things too confusing.

Xyp, 2021-12-22:
You make me so much wishing to have time to learn Kicad. Maybe one time I'll get that time...

Xyp, 2021-12-22:
Worked with fusion 360 based Eagle and think they completely screwed it up. It got slow and laggy. Forget about the nice New Features if the useability of the core Features is so much impacted!

dreamcat4, 2023-04-16:
+1 another have here ardino micro (chinese clone version). And just don't want to bother transferring it to another PCB, to have to order those 10x pcbs, be waiting 2 weeks. There is so little on it, to wire up.

If that fails then the can still fall back to ordering the custom PCB.

xyphro, 2023-04-16:
Feel free to port it to arduino. I won't do it, but released all sources.

xyphro, 2023-04-16:
why port btw? You can just flash the hex file and wire it up like shown in the schematic.

dreamcat4, 2023-04-16:
> why port btw? You can just flash the hex file and wire it up like shown in the schematic.

indeed: that is exactly what i am hoping to do. Precisely that

dreamcat4, 2023-04-16:
If to follow your existing guide in the README... what i appear to be missing here is AVRisp programmer. But it seems like it would be possible to make one (from another 2nd arduino)

So it seems anything different will just be about the bootloader stuff, for the flashing process.

xyphro, 2023-04-16:
If all pins are exposed on the board you mentioned it should work. Let me/us know :-)

xyphro, 2023-04-16:
Yes, this project brings its own bootloader with it. Maybe you are also lucky and the arduino BL supports the application image as is? Could be worth a try.

Closed 2022-11-24.

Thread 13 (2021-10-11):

Finished product consultation

michaelshow, 2021-10-11:
Hello, xyphro， can your finished product be sold? Can you sell me one?

wgprojects, 2021-12-02:
+1. If you sold kits, I would buy some. It would be really cool if the bootloader came pre-flashed but I guess that might as well be a completed unit. I'd probably buy that too. With your BOM cost at 14, x 3 = $45 price point being reasonable compared to the competition it could be worthwhile. The PyVISA compatibility is huge.

Xyp, 2021-12-02:
I am always considering it :-) The housings would come with some NRE costs that might be an issue. 3D printing is slow and nothing I'd like to do for higher volumes - also in terms of repeatable quality.
Just a PCB with premounted and preprogrammed Avr and smd components would not be a big issue.

If you send me an email I might help if you don't want to solder yourself: xyphro@gmail.com

Closed 2022-11-24.

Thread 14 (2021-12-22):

Programming instrutions are wrong (?)

christakahashi, 2021-12-22:
I found a second issue so I've edited this to combine them since I think they're probably only worth one commit anyway.
1) The atmega32u4 doesn't have any fuse bits in the upper nibble of the extended fuse byte.  the directions say to use -Uefuse:w:0xcb:m , but I think it should be 0xFB.  AFAIK setting unimplemented fuses just gets ignored but it may cause a failure to verify later as it gets read back 0xFB.

2)  "LED blinking: The USBGPIB converter is connected to a measurement instrument, it is powered off or its GPIB port is disabled. "  should read: "LED blinking: The USBGPIB converter is **not** connected to a measurement instrument, it is powered off or its GPIB port is disabled. "

Xyp, 2021-12-22:
Thanks a lot for reporting Chris! I will fix it the next days.

Closed 2022-11-24.

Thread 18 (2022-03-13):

Turn off automatic *IDN? readout

larrye11ison, 2022-03-13:
I have several older instruments that don’t support normal SCPI commands like *IDN? so I would like to turn off the automatic *IDN? readout at startup. I'm trying to make the calls to control_in() and write() to turn this off, but I can’t get it to work.

The *Setting Parameters* section on the main GitHub page has some sample code and says “VM is the opened VISA resource.” I assume that VM is what my code below calls the “instrument” (the “instr” variable). This is based on the following presumptions:

- Your mention of “VISA resource” on the github page matches very well with the return value from the “open_resource()” call.
- The only other thing I could even GUESS could be involved is the pyvisa Resource Manager. But this object does not have methods for control_in() or write(), so it is totally ruled out.

Is there an easy fix for my code below? Should it call control_in() and write() on the “instrument” like this? If so, any idea why it’s not working? Or, if I should be calling these methods on some other object, can you tell me what that is?

```python
import pyvisa
rm = pyvisa.ResourceManager()
all_resources = rm.list_resources()
theAddressToUse = all_resources[1] ## In my case, I want the second item
inst = rm.open_resource(theAddressToUse)
print(inst.query("ID?"))  ## 3488A uses ID?, not *IDN?

## Everything up to this point works fine -- I get the string "HP3488A" returned,
## above, and other commands/queries on the 3488A work as expected.
## But then I try this to try and turn off the automatic *IDN? :
inst.control_in(0xa1, 0x40, 0, 0)
inst.write('!0001')
## The instrument beeps with an error, I assume because the *IDN? command is being sent yet again...
## But those commands never have any effect on the controller.
```

xyphro, 2022-03-13:
Hi,

I'll make a dedicated python Script and push it to Github + Update you here
once done.

Best regards,

Kai

Not Larry Ellison ***@***.***> schrieb am So., 13. März 2022,
13:47:

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

Xyp, 2022-03-13:
Hi Not Larry :-)

I tried it out and it works. Actually it did not on the first try. This was, because I had an old firmware and this might be your issue here too. This feature was not present in the first firmware version.
Could you download from SW/binaries folder the TestAndMeasurement.bin file and program it as described in the readme.md to your device (short circuit the 2 pins as shown, plug it into the USB port, copy the TestAndMeasurement.bin to Flash.bin and overwrite it)?

I used this sequence to make it work:

import pyvisa as visa

rm = visa.ResourceManager()
r = rm.list_resources()
print(r)
VM = rm.open_resource(r[0]) # Maybe adjust this if your gpibusb adapter is not the 1st returned device
VM.control_in(0xa1, 0x40, 0, 0); # Identificator pulse command (1st step for configuration command
VM.write('!0001') # only sense GPIB address

Let me know if my suspicion with the firmware version was the cause.

BR,

Kai

larrye11ison, 2022-03-13:
Thanks, Kai. BTW, I'm the guy in the US that just received the unit from you a few days ago (after the lengthy shipping time, thanks to the postal workers on both sides of the Atlantic!).

Because the device was so new, I didn't even consider that it had the older firmware! Turns out that was exactly the problem - I flashed the new TestAndMeasurement.bin firmware and it's working fine now. Of course, now I feel silly for not trying that from the beginning...

Closed 2022-03-13.

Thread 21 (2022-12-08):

Request for setting parameter in eeprom

1st-elektron, 2022-12-08:
I have no luck in setting parameter via control_in (NI VISA)
Please can you give me the adresses in eeprom to set this values directly?
Thank you

xyphro, 2022-12-08:
Hi Mike,

Old fw versions did not support setting those parameters. I fooled myself
already by trying it out on a devices with old fw version. Did you upgrade
to the latest one?

Will check adresses from sourcecode and share.

Best regards,

Kai

Mike ***@***.***> schrieb am Do., 8. Dez. 2022, 14:14:

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

xyphro, 2022-12-08:
Byte 104 selects if a gpib identification is tried to be read or not duting
powerup:
1 = gpib identification id read
0 = no gpib id read

Byte 105 selects gpib read transfrr termination method:
0 means EOI only
10 = LF termination
13 = CR termination

Mike ***@***.***> schrieb am Do., 8. Dez. 2022, 14:14:

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

xyphro, 2022-12-08:
Let me know if it helps and if the firmware version wad the issue!

1st-elektron, 2022-12-08:
> Hi Mike, Old fw versions did not support setting those parameters. I fooled myself already by trying it out on a devices with old fw version. Did you upgrade to the latest one? Will check adresses from sourcecode and share. Best regards, Kai Mike ***@***.***> schrieb am Do., 8. Dez. 2022, 14:14:
> […](#)
> I have no luck in setting parameter via control_in (NI VISA) Please can you give me the adresses in eeprom to set this values directly? Thank you — Reply to this email directly, view it on GitHub <#21>, or unsubscribe <https://github.com/notifications/unsubscribe-auth/ABFXEGHBEGNEZWPT2FHPDTLWMHNMDANCNFSM6AAAAAASYEAXEY> . You are receiving this because you are subscribed to this thread.Message ID: ***@***.***>

Hi Johannes,
thank you for your fast answer.
I have the latest TestAndMeasurement.bin from 03.05.22.
Thank you for the adresses of the parameter
I will try them soon.

Kind Reagards Michael

1st-elektron, 2022-12-08:
Johannes, i am sure that there are no problems with your firmware.
I was not able to set control cmds via NI-Max. That is of course a problem of my unknowing with this software.
I have send a eeprom-file with following contents
00000000 FF FF FF FF FF FF FF FF FF FF FF FF FF FF FF FF
................................................................................................................
00000100 FF FF FF FF 00 10 FF FF FF FF FF FF FF FF FF FF
................................................................................................................
000003F0 FF FF FF FF FF FF FF FF FF FF FF FF FF FF FF FF

Next i will try at 105:13
I still have an error timeout message with an old Marconi 2022 RF Signal Generator.
Thank you for your support.

Kind Regards Michael

xyphro, 2022-12-08:
Hi Michael,

I have an even older Marconi 2019A at home. Let me try this one out and share back with you.

You can also contact me by mail under xyphro@gmail.com

Best regards,

Kai

PS: I am called Kai not Johannes :-)

xyphro, 2022-12-08:
BTW: 0x10 is not the same as 10 decimal. Try 0x0a

xyphro, 2022-12-08:
Interim status:
Writing works with NI MAX - also with cleared eeprom, so default values.

Just tried this sequence here (takein from Marconi 2019A manual):
CF 123.45MZ, DE CF 25 KZ, LV 1.2 UV

NI MAX converts the spaces to \s when I press write to this one:
CF\s123.45MZ,\sDE\sCF\s25\sKZ,\sLV\s1.2\sUV

And the instrument changes the settings accordingly.

Will try out the Reading of data now.

xyphro, 2022-12-08:
Update on read:
I also get Read timeouts.

To check if it is an issue with the usb gpib converter itself, I connected my NI GPIB-USB-HS to the instrument and get the same behaviour (Error iberr = EABO)

Likely some kind of magic trick needs to be applied to make it work. Will continue trying a bit.

ami3go, 2022-12-15:
Hi all i have the same problem.
I  was using an old Panasonic_vp-8122a which return a settings into *IDN? request.

Connect converter to any instrument.

```
import pyvisa
rm = pyvisa.ResourceManager()
rm_list = rm.list_resources()
print(rm_list)
```
Pick your instrument name
```
instrument_name =  " your instrument"
VM = rm.open_resource(instrument_name)
VM.control_in(0xa1, 0x40, 0, 0)
VM.write('!0001')
```
make a power cycle

xyphro, 2022-12-15:
Hi ami3go,

Michaels problem at the end was unrelated to the eeprom.

Are you saying you have an issue, or is this your proposal to solve?

In case you have an issue, please give a bit more details likr if you use latest firmware, which visa provider and if you use python and if which type of pyvisa (native direct insttument access ot via visa provider) and OS.

Best regards,

Kai

Closed 2022-12-11.

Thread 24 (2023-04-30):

Enclosure 3D file formats

dazz100, 2023-04-30:
Hi
I'd like to modify the 3D enclosure but I don't use Autocad Fusion360.
I could design a whole new enclosure, but I would prefer to start with your design.

The issue is my CAD program (Designspark Mechanical) can import the following file formats (in order of preference):
OBJ  .obj
Sketchup  .scp
STEP  (read only) .stp
STL   .stl

Could you please upload the 3D model in one of these file formats?
Thanks

xyphro, 2023-05-03:
Looking at the EEVBlog thread you don't require this anymore it seems, right?

Closed 2023-05-03.

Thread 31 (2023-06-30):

Any chance of an Ethernet variant?

m1geo, 2023-06-30:
I'd be really keen on an Ethernet variant of this for automated setup. My ATE experience is that Ethernet works better, long term, than USB, and doesn't require any host-side drivers. Perhaps the 32u4 part isn't quite up to it, but a separate IC for Ethernet (or an STM32) may work?

xyphro, 2023-07-01:
I'd then make an combined version with ethernet and USB. Main reason is that you'd need for an ethernet version a power supply which would be best exposed as USB-C connector. Routing the usb lines to an MCU does then not cost a lot.
The hw will get more expensive a bit, levelshifting will likely be required e.g. an spi or i2c based gpio expander IC.

What I do not like about ethernet is that you expose the user to IP configurations (not all networks have DHCP) and to my knowledge there is no easy way to discover instruments in a network. Here I might be wrong, please correct me :-)

xyphro, 2023-07-01:
Accidentally pressed close - reopened it.

m1geo, 2023-07-01:
An easy option to making the device discoverableis to send broadcast packets (sending UDP packets to 255.255.255.255) which contain the actual IP address. Anything in the same subnet will see the broadcast packet.

I agree the IP address option isn't ideal, but DHCP would be a great start. A USB tool could set up the network options if needed. I agree there are complications, but TCPIP would be a nice option!

Thanks for a great project.

dazz100, 2023-07-01:
Hi
If an ethernet adapter is given a host name, then you don't need to know the ip address when allocated by DHCP.   Each device on a network would need a unique host name so that requires programming.

Ethernet would make Wifi or Bluetooth viable, but in certain scenarios/labs, Wifi would not be acceptable (eg.  EMC testing).  You would still need wired Ethernet and USB for configuration.

So ethernet would be a great option, but a lot of work.

The major issue with USB is the need for USB port for each adapter.  Not a problem with 1-5 items of test equipment, but many labs have more than that.

Even with just USB, it is still a great project.

larrye11ison, 2023-07-01:
Just my 2 cents, but I'd love to be able to control these devices using TCP/IP over ethernet. All the potential drawbacks being discussed above simply aren't a problem for me. I can find new devices on my network easily. It would be nice if there was an easy way to customise the hostname on each device, but even if that wasn't available, I can do it at the network level.

dazz100, 2023-07-01:
This is a very niche product so to be successful, it needs to satisfy the requirements of the niche.  That includes being user friendly.  So if ethernet is added, then is should be fully featured, with Wifi/Bluetooth.  If it can be better than commercial equivalents, that could only be a good thing.   Writing the code for that is not something I can do.

xyphro, 2023-07-01:
Let me think about it.
Btw: my very first version of this was wifi based :-)

dazz100, 2023-07-01:
I would be really interested in a Ethernet version.  The following is my wish list of features:

**RF emissions**

For many, wifi/BT would be a great feature, but anyone doing EMC testing, sensitive measurements, or concerned about data security, Wifi/BT would not be usable.  For this reason, the adapter should be able to work with/without Wifi/BT and with USB/wired Ethernet.

**Power**

Given that there is no power available over the GPIB,   Power options should be:
- USB - C    5V wall-wart adapter or host device
- PoE - to avoid the need to supply power separately to a wired Ethernet cable.
- Battery 15V to 5V (possibly through the USB-C connector).  Easy to include a voltage regulator that can handle 15V to 5V input.

**Configuration**

Configuration needed to configure ip's and Wifi/BT etc.

- Needs to be via USB or/and
- basic web-server via Ethernet.

**Multiple Devices**

The current usb version is cheap enough that a limit of one adapter per instrument is OK.   I anticipate an Ethernet version will be expensive enough to want one adapter for multiple instruments.   GPIB cables are available on Aliexpress.

**Driver Compatibility**
Whatever the design/features the driver should be compatible with everything.

**Fit-for-but-not-with (FFBNW) Options**

Not everyone will want or need POE,  Wifi/BT, or even Ethernet, so there should be options not to fit components for unwanted features.   The firmware should be able to figure out what options are/are not fitted and still work OK.

**Hand Assembly**

The cost of a PCB and 3D printed enclosure are not big cost drivers.  Components should be selected to allow hand assembly by a competent person.  SMD yes, but not the smallest components.

**EMC Compliant**

It would be highly desirable if the adapter was compliant with EMC standards.  This would be good engineering and also broaden the appeal of the adapter.

This project would be a lot easier if the work is shared.  I have programmed in a number of languages, but never C.   I could provide some assistance with hardware.

m1geo, 2023-07-01:
I agree with all of the comments here.

But my gut feeling is even the crappiest DHCP/Static IP configuration is workable. I have a decent few things that I'd like to use with these, and most of the newer gear uses Ethernet (LXI) etc., so adding the older kit in would be awesome.

Manufacturing wise, I'd target one of the cheap, low volume Chinese assembly places (JLCPCB, PCBWay, ALLPCB). But keep hand assembly open as an option. Just dump all the files into github and let others decide.

Thanks for the consideration! 👌

xyphro, 2023-11-01:
I started (with low prio for now) to look into if we can do something with a combination of ESP8684and level shifting GPIO expander to bridge to 5V GPIB levels (and reusing the baseline GPIB code from this project as common ground).
Why ESP8684? It has a great level of integration and I'd like to play arround with Risc V.

Power supply over USB with a buck converter (cause LDOS are incredibly slow for reliable Wifi operation)- either plug in into an instruments usb port or use a USB charger (not happy about this: A wireless solution which needs a wire).

Design in Kicad with LCSC part numbers.

I like the idea of a Wifi based solution (as said, I worked on this a while ago). In medium to big sized company environments wifi will be a no go though, but for usage at home it is cool.

This might be a seperate project though, but I will keep this thread open to update on more progress.

m1geo, 2023-11-03:
The ESP is a nice idea, but I figure the WiFi will be less reliable than USB so not sure it serves a real purpose beyond being cool. Still a nice idea and I would be interested in a WiFi unit, but LAN is where it's at. :)

xyphro, 2023-11-03:
Do I hear you saying I should go with something like ch32v208? :-)
It has integrated 10MBit PHY, usb and matches my wish to work with risc V.

m1geo, 2023-11-10:
I think that is an excellent idea, display or otherwise. I would also advocate broadcast packets (sending to 255.255.255.255) which include the GPIB instrument name and the IP address, sent every 5 seconds. It would be trivial to find the devices on the network with a simple client program (just listening for broadcast packets).

xyphro, 2023-11-15:
Mcus are ordered, studies on vxi-11 protocol started!

xyphro, 2023-11-16:
> I think that is an excellent idea, display or otherwise. I would also advocate broadcast packets (sending to 255.255.255.255) which include the GPIB instrument name and the IP address, sent every 5 seconds. It would be trivial to find the devices on the network with a simple client program (just listening for broadcast packets).

Can do that, but would make that an option which can be turned off, for home network it is no issue, but in a company network or lab-sub-network you might get into trouble with an IT guy (especially if they enabled routing of BC packets) :-)

Started on PC side with ONC/RPC stack programming required for VXI-11 while waiting for the MCUs...

This does not mean, that I don't intend to support raw tcpip, but I think a VXI-11 wrapper makes sense to avoid a strange protocol layers that users have to take care of like applied for uart based gpib converters (+++ messages) to allow things like status byte reading.

m1geo, 2023-11-24:
BC packets are usually just kept local on our corporate network - they don't propagate upwards.

But, having looked into this a bit more, I would suggest [mDNS](https://en.wikipedia.org/wiki/Multicast_DNS) as the way to do this. It's an industry standard protocol.

xyphro, 2023-12-04:
Will keep that in my mind, thanks for sharing! Still quite a trip to get there :-)

m1geo, 2023-12-07:
This is awesome progress! Thanks for the update and yes, it seems like a very suitable CPU/SoC.

xyphro, 2023-12-07:
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

Have ordered it now. In a week i can mount components and get started. Will continue to post here until I open a new repository for it.

xyphro, 2023-12-25:
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

+++update+++
The development board is mounted and tomorrow will be the great day of testing if the xtal begins to oscillate and the debugger connection works :-)

The rj45 connector with integrated transformer is not mounted yet on purpose.

xyphro, 2023-12-26:
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

...all set: Debugger connection works like charm. Now there is "just a little bit of SW to make and test" :-D

dazz100, 2023-12-26:
I like it.
Good progress.

m1geo, 2024-01-06:
This is excellent progress! :dancers:

xyphro, 2025-01-11:
Note: I paused the development for longer time. Doing this "just for fun" and for $0 + support/documentation/testingeffort is not possible right now :-( I might pick it up at a later stage.

Closed 2025-01-11.

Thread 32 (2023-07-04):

Device enumerating but getting an error on 34401a  power up

hobbymachinist, 2023-07-04:
Hi,

I can see the device enumerating, but noticing an error on power up of DMM if the usb is connected to host. If I plugin the usb after the DMM has powered up, I don't see the error. Race condition ?

```
[3481329.791761] usb 1-1: new full-speed USB device number 81 using xhci_hcd
[3481329.940618] usb 1-1: config 1 has an invalid descriptor of length 0, skipping remainder of the config
[3481329.941606] usb 1-1: New USB device found, idVendor=03eb, idProduct=2065, bcdDevice= 0.01
[3481329.941619] usb 1-1: New USB device strings: Mfr=1, Product=2, SerialNumber=3
[3481329.941624] usb 1-1: Product: GpibUsb
[3481329.941629] usb 1-1: Manufacturer: XyphroLabs
[3481329.941633] usb 1-1: SerialNumber: GPIB_22_82039523046351C9F031
[3481333.842791] usb 1-1: USB disconnect, device number 81
[3484953.394993] usb 1-1: new full-speed USB device number 82 using xhci_hcd
[3484953.543834] usb 1-1: config 1 has an invalid descriptor of length 0, skipping remainder of the config
[3484953.544857] usb 1-1: New USB device found, idVendor=03eb, idProduct=2065, bcdDevice= 0.01
[3484953.544870] usb 1-1: New USB device strings: Mfr=1, Product=2, SerialNumber=3
[3484953.544877] usb 1-1: Product: GpibUsb
[3484953.544881] usb 1-1: Manufacturer: XyphroLabs
[3484953.544885] usb 1-1: SerialNumber: HEWLETT-PACKARD_34401A_0_7-5-2
```

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

hobbymachinist, 2023-07-04:
Ah, this is probably related to IDN query on power up and the termination strings. I've set it to terminate  with carriage return and it seems to behave now. Thanks again for this work, very useful :heart:

Closed 2023-07-04.

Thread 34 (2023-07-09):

sigrok-cli errors

deepfryed, 2023-07-09:
Hi Kai,

I ran into some errors while trying to use sigrok-cli to read the DMM - is there a setting / config option I'm missing ?  FWIW reading and writing to /dev/usbtmc0 works perfectly fine.

https://www.eevblog.com/forum/projects/smuview-a-sigrok-gui-for-power-supplies-multimeters-and-more/msg4950760/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

The cli reads measurement fine the first time, but doing it again results in an error. Disconnect and reconnecting, it works again.

```
$ sigrok-cli -d scpi-dmm:conn=usbtmc/03eb.2065 --samples 5 -c measured_quantity=voltage/dc
P1: 4.99998 V DC
P1: 4.99998 V DC
P1: 4.99998 V DC
P1: 4.99998 V DC
P1: 4.99998 V DC
...

```
$ sigrok-cli -d scpi-dmm:conn=usbtmc/03eb.2065 --samples 5 -c measured_quantity=voltage/dc
sr: scpi_usbtmc: USBTMC bulk in transfer error: LIBUSB_ERROR_TIMEOUT.
sr: scpi_usbtmc: USBTMC bulk out transfer error: LIBUSB_ERROR_TIMEOUT.
sr: scpi_usbtmc: USBTMC bulk out transfer error: LIBUSB_ERROR_TIMEOUT.
sr: scpi_usbtmc: USBTMC bulk out transfer error: LIBUSB_ERROR_TIMEOUT.
sr: scpi_usbtmc: USBTMC bulk out transfer error: LIBUSB_ERROR_TIMEOUT.
sr: scpi_usbtmc: USBTMC bulk out transfer error: LIBUSB_ERROR_TIMEOUT.
sr: scpi_usbtmc: USBTMC bulk out transfer error: LIBUSB_ERROR_TIMEOUT.
sr: scpi_usbtmc: USBTMC bulk out transfer error: LIBUSB_ERROR_TIMEOUT.
```

xyphro, 2023-10-15:
I can only guess here. How does sigrok know which multimeter type it is and how to control it?
There are many different multimeters with many different ways to control them. There is also no common auto identify method present, especially old multimeters don't even support *idn?

xyphro, 2023-10-15:
You could try to make a usb trace and see how it controls it. Or a visa trace if possible for your OS.

Closed 2023-12-31.

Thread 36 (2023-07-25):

Reading status byte interrupts writing/reading.

mariusCZ, 2023-07-25:
Hi,

Sorry for opening a second issue during the same day, but I'm facing another weird issue when using Labview (this time natively on Linux). Basically, if I write data and right afterwards read the status byte, the data writing gets interrupted and does not continue.

Now this may be an issue with Labview, so I will try repeating the same with pyVISA and see if I get the same thing.

mariusCZ, 2023-07-25:
The problem persists with pyvisa too. Here's an example that causes the issue:

```
import pyvisa as pv

rm = pv.ResourceManager()
lockAmp = rm.open_resource('USB0::0x03EB::0x2065::+00000_+00000::INSTR')

lockAmp.write("ID")
print(lockAmp.read_stb())
print(lockAmp.read())
```

For reference, I am interfacing the Signal Recovery 7265 DSP Lock-In Amplifier. The lock-in amp also has a communication test menu, which shows what data is received and read from, and if I run this program, only part of the data is written (like only "I" or "ID" without the CR and LF). This thing is fairly old so there may also be some sort of incompatibility with it.

mariusCZ, 2023-07-25:
I have sent the images. Would it perhaps be a good idea to disable interrupts during gpib writing?

xyphro, 2023-07-25:
Stb is if I remember correctly not using interrupts. Confidence is on that
part only 80%, it is a long time ago.

mariusCZ ***@***.***> schrieb am Di., 25. Juli 2023, 17:19:

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

mariusCZ, 2023-07-25:
STB itself doesn't look like it uses interrupts indeed, but I am now looking at the LUFTA library and it looks like maybe the events use interrupts? In which case disabling interrupts may result in some other problems with USB possibly.

xyphro, 2023-07-26:
Short update:
I confirm this bug. The issue is not directly related to the interrupts,
but it is a synchronization issue.

Readstb uses control transfers while normal writes are using bulk transfers.

2 error conditions are identifed with same failure mode and 2nd level cause:

1st: it can happen as function of how things are scheduled by the usb host
and visa driver that the control transfer gets executed while a gpib write
is handled. As readstb executes also gpib transfer, it can happen that it
disturbs the normal gpib transfer. This behaviour can even vary depending
on usb host controler type.

2nd: when writing to gpib data that span across multiple bulk packets it
surely hapoens that the control transfer is executed during 2 bulk
transactions, ibdependent of usb host scheduling. This behaviour is
independent of host controller type, but more driven by gpib device latency
and speed (or shorter: timing).

Solution is under development: the readstb control transfer will get
properly synchronized within the firmware.

I planned an update the firnware today, but decided to analyze it a bit
deeper, which was good, cause I found this second failure mode.

Well spotted, thanks for reporting and stay tuned for an update!

mariusCZ ***@***.***> schrieb am Di., 25. Juli 2023, 18:37:

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

xyphro, 2023-10-17:
Hi!

I made a lot of changes, especially on this part. Will push code this evening (berlin timezone).

Best regards,

Kai

xyphro, 2023-10-17:
I pushed it! Curious what your observations will be!

mariusCZ, 2023-10-25:
Unfortunately the same issue persists! I tested it with the same device and the same Python script test case and it still fails. This time around it manages to consistently write two bytes of data before getting interrupted by stb reading.

xyphro, 2023-10-27:
> Unfortunately the same issue persists! I tested it with the same device and the same Python script test case and it still fails. This time around it manages to consistently write two bytes of data before getting interrupted by stb reading.

I will pick this up again next after solving the hp34001 issue from Chris!

xyphro, 2023-11-01:
Hi Mariusz,

I want to focus now on this one again.
Do you think it would be possible to do a capture with wireshark of that issue? Ideally based on the latest firmware from 30th October?

Otherwise I will provide you this evening a debug firmware for an experiment adressing a suspicion I have. Basically I'd like to check if it is usb side or gpib related by stubbing out the gpib side read status byte code.

Best regards,

Kai

xyphro, 2023-11-01:
> I don't mind doing both. But it'll have to be tomorrow since today is a day
> off and I am not in the lab.

Great! I can also only do something this evening as I first need to work :-) [no vacation in Neterhlands today :-/]

 Will then make such a special firmware image and share with u.

xyphro, 2023-11-01:
[TestAndMeasurement_TestA.zip](https://github.com/xyphro/UsbGpib/files/13230915/TestAndMeasurement_TestA.zip)
[TestAndMeasurement_TestB.zip](https://github.com/xyphro/UsbGpib/files/13230917/TestAndMeasurement_TestB.zip)

Hi Marius!

Attached are 2 firmware images (in hex and bin format, whatever you require).

TestB is NOT reading over Gpib the status byte, but always hardcoded reporting 0xAB back as status.
TestA is basically the current baseline.

My expectation is:
- TestA image will show your status byte read issue. Can you here capture that situation with Winshark and share the log? Your python testcase should ideally stop at the situation where the read issue occurs. This is not a strict requirement, but would help the debug.
- TestB image will likely NOT show an issue. Can you run the same status byte read testcase here and let me know if it works and returns 0xAB (=171 decimal)? It is not necessarily required to capture USB trafic with that one.
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

On top it would be good if you could share your testcase, such that I can correlate Visa transactions with USB traffic.

The TestB image test will show me where to focus on in further root cause analysis.
TestA image will show me the timing behaviour. From that one I can see what happens: Does the ControlIin transfer related to status reading timeout? From the timestamps of the relevant section I will be able to make also conclusions on the internal behavior of the firmware.

Thanks a lot upfront for your support Marius. Hope we nail that one down very soon too!

Best regards,

Kai

mariusCZ, 2023-11-02:
Hi Kai,

Thank you for all the help! I will try to test this today, but I may be a bit busy so not sure if I can get it done. If not, I should be able to do it tomorrow.

As for the test case, right now I am just using a very simple Python script, it is like this:
```
import pyvisa as pv
import time

rm = pv.ResourceManager()
lockAmp = rm.open_resource('USB0::0x03EB::0x2065::+00000_+00000::INSTR')

lockAmp.write("ID")
print(lockAmp.read_stb())
print(lockAmp.read())
```
As for the actual program, it is not really finished right now as it does not work properly, so I can share it, but I don't think there's much use to it since it's a bit more convoluted and as far as I know, doesn't do anything special that may impact behaviour.

xyphro, 2023-11-02:
Thanks a lot Marius. No need to hurry, do it when it fits and does not cause trouble for you!

xyphro, 2023-11-02:
Thanks a lot Marius. No need to hurry, do it when it fits and does not cause trouble for you!

mariusCZ, 2023-11-02:
[debug.zip](https://github.com/xyphro/UsbGpib/files/13241815/debug.zip)

Hi Kai,
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
mariusCZ, 2023-11-03:
Thank you!

Another thing I could offer is to set up a debug platform if that would be of any help. I know that the 32u4 has a JTAG interface. I have a spare 32u4 laying around and a spare GPIB connector. The only thing is that the JTAG pins in this project are used for I/O, but I can add a 595 shift register for the data output and shift the I/O around to free up the JTAG pins. This would allow a more detailed look at how the interrupts occur, the variables, call stack and etc.

xyphro, 2023-11-03:
I compared...

The NI adapter sends:
1. SPE (serial poll enable)
2. TF (make the instrument work in Talk mode)
3. Then it reads
4. SPD (serial poll disable)
5. UNT (untalk => make all bus participants stop talking)

What I do has Step 4 and 5 reversed.

I know that the following read fails for you and not the readstb, but it might be possible that your intstrument is not happy getting Untalk and receiving SPD afterwards.

But let me look further.

xyphro, 2023-11-05:
[TestAndMeasurement_5thNov_reversedUNT_SPD_IN_RSTB.zip](https://github.com/xyphro/UsbGpib/files/13258998/TestAndMeasurement_5thNov_reversedUNT_SPD_IN_RSTB.zip)

Hi Marius,

let's give it a try. The order described in previous post seems to be pretty standard. Found it back in a few GPIB documents. So it could be, that your (and maybe other) instruments strictly support only that order.

Attached firmware has this order now implemented.

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

Best regards,

Kai

xyphro, 2023-11-06:
Btw: no usb captures required, as the issue seems to be on gpib side.

I value btw. your idea of jtag debug, but are afraid that it won't help here a lot - I can tell you already where the timeout happens, but not why. Jtag debug to the instrument might help and seeing the state of the jtag statemachine, but that one is closed source.

mariusCZ, 2023-11-06:
Hi Kai,

I am sorry to say, but it still does not work. I'm starting to think this is perhaps an issue with the device I am using rather than anything else. Which could be a possibility since the serial port on the device does not work at all, so I guess it wouldn't be surprising something with the GPIB is not working. Perhaps we should close this issue?

xyphro, 2023-11-06:
:-(
It might be the case, but the only way we'd get confidence is to use another adapter and try out.
I'd not close this ticket now. Maybe somebody else has the same issue and we get new insights.
In case you have in future any updates, let me know!
But for now I am really out of ideas :-(

mariusCZ, 2023-11-07:
That's okay! Thank you very much for your continued efforts! I will let you know in case something pops up.

xyphro, 2023-11-19:
Hi Marius,

I just made bigger changes (transfer speed increase by factor 7 and 4 :-) with blazing 512KByte/s for writes) and test on all my gpib equipment. When testing on my cmu200 I saw that a read status byte works, but generates a query error (-400).
Debugging it right now, but it *might* relate to what you see.

Best regards,

Kai

xyphro, 2023-11-19:
Found the cause and fixed it. However it is based on an untested development firmware and I don't want to "annoy you away" by introducing new issues, so let me test further ans peovide you afterwards a test fw.

mariusCZ, 2023-11-20:
I'm happy to test whether it's untested or tested! I may not be able always able to do it, but I'm more than happy to!

xyphro, 2023-11-29:
[TestAndMeasurement_Check_readstb.zip](https://github.com/xyphro/UsbGpib/files/13504607/TestAndMeasurement_Check_readstb.zip)

Hi Marius,

sorry - had a busy time. Can you check this once?
It fixed ReadStb on CMU200 for me.

Best regards,

Kai

xyphro, 2023-11-29:
[TestAndMeasurement_Check_readstb.zip](https://github.com/xyphro/UsbGpib/files/13505220/TestAndMeasurement_Check_readstb.zip)

Hi Marius,

sorry - had a busy time. Can you check this once?
It fixed ReadStb on CMU200 for me.

Best regards,

Kai

mariusCZ, 2023-12-04:
Hi,

Sorry for the late reply, was a bit busy! Unfortunately, the issue still persists. I think it's safe to say at this point that the issue is with my device rather than the adapter. Thank you for your continued efforts!

xyphro, 2023-12-31:
Damn :-(

I did invest lots of time into extensive testing of readstatusbyte, also exactly mimicing the niusb waveforms. So let's indeed assume for now it is instrument related.
I leave this still open for others to jump on it, as a little bit of doubt is left.

xyphro, 2025-01-11:
Closing since no further problem was raised by anybody else.

Closed 2025-01-11.

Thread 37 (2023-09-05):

someting went wrong with "Setting Parameters", I think.

bnzf, 2023-09-05:
Hi,
I tried the "Setting Parameters" for read termination and automatic instrument ID. In the first attempt something seemed to go wrong (I think it was caused by that I tried to send both commands at once). Then I repeated the procedure command by command. All looked fine.

But after that rm.list_resources() does not work anymore, nothing happens, I get no Python prompt afterwards.
I rebooted the UsbGpib, I disconnected it, started a new python session, I reinstalled the firmware,... no changes. However the instrument is well visible with NI-Max and data coming from the instrument is there visible.

As I cannot connect via pyvisa anymore, I can not repeat or clear the parameter setting from there.
Is there a possibility to reset the  EEProm somehow without pyvisa?
Or can I use the NI-Max tool for sending commands to (re)set the EEProm?

I use python from an OS-X machine. NI-Max is installed on a Windows-7 machine. The GPIB instrument is a HP5370 in talk only mode (it does not support the automatic instrument ID and has \r\n termination).

xyphro, 2023-09-05:
read termination setting does influence the receiving of data from the
instrument which is only happening when you read.

I recently had issues too when I installed  tek openview software that
under the hood installed tekvisa which got my pyvisa into a non working
state (independent of gpib, any visa stuff stopped working). Deinstalling
tekvisa made it working again.

I somehow think that it might be some general visa issue. Or maybe you have
from other tests a libusb driver installed instead of a generic usbtmc
driver?
Do you have other instruments that you can crosscheck on your mac os PC to
see if visa works?

I am not too familiar with mac os. Does it have an equivalent to device
manager to see which driver is used for usbgpib device?
Or is lsusb or so possible?

bnzf ***@***.***> schrieb am Di., 5. Sept. 2023, 21:22:

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

bnzf, 2023-09-06:
I tested an instrument with native USBTMC. On OSX there also rm.list_resources() stalled. I then uninstalled NI-visa (a lot of work as they provide no proper uninstaller but only instructions what to delete) and reinstalled it, after that all worked fine again. I however did not install anything before  I got in trouble with pyvisa, I only messed around with the "Setting Parameters" commands.

I then did turn off the automatic instrument ID  as described in the instructions. This worked, I no longer get an error message on the instrument when turning the USBGpib adapter on.

However the setting of the read termination does not work entirely as expected.
It works in the sense that inst.read() now works. But I get random new lines in the output:

```
>>> while True:
...     print(inst.read())
...
TI = 1.00290000000E-07

TI = 1.00210000000E-07
TI = 1.00270000000E-07

TI = 1.00230000000E-07

TI = 1.00270000000E-07
TI = 1.00290000000E-07
TI = 1.00210000000E-07
```
When I do inst.read_bytes() I get:

```
>>> print(inst.read_bytes(48))                                          
b'TI = 1.00390000000E-07\rTI = 1.00310000000E-07\r\nT'
>>>

```

So the first \n is missing, but is there again in the second set of data.
I would have expected to see here no \r and \n anymore.

Without the read termination setting to \r, inst.read_bytes() never dropped a \r or \n, so it is not caused by the data send from the instrument.

bnzf, 2023-09-06:
P.S. It looks that I get the random new lines only when the Instrument is set in "listen+talk"-mode. If I set the switch on the instrument to talk-only there are no additional new lines.

xyphro, 2023-10-17:
I will try to reproduce it this evening.

xyphro, 2023-12-31:
I could btw never reproduce it. Does it still occur with latest release candidate?

bnzf, 2024-01-02:
I tried now the release candidate software.

With the adapter where I applied the "Setting Parameters" modification, I get in talk only mode, still, the desired output. Diagnostic with inst.read_bytes() produces:

print(inst.read_bytes(96))
b' 9.99324000000E+06\rFRQ= 9.99909000000E+06\rFRQ= 9.99714000000E+06\rFRQ= 9.99714000000E+06\rFRQ= 9.9'

In "listen+talk"-mode the random behavior is gone, but I get an extra empty line in the inst.read() loop. Diagnostic with inst.read_bytes() produces:

print(inst.read_bytes(96))
b'\nFRQ= 9.99324000000E+06\r\nFRQ= 1.00030000000E+07\r\nFRQ= 9.99519000000E+06\r\nFRQ= 9.99519000000E+06\r'

On an other of your adapters with the release candidate software in default state, i.e. without the "Setting Parameters" for read termination and automatic instrument ID, I get in both settings of the instrument (talk only, listen+talk) the same:

print(inst.read_bytes(96))
b'RQ= 9.99887000000E+06\r\nFRQ= 9.99497000000E+06\r\nFRQ= 9.99692000000E+06\r\nFRQ= 9.99497000000E+06\r\nF'

here I defintively need to use inst.read_bytes() here as the normal loop with inst.read() misses the termination (of cause) and runs in a timeout error.

P.S. In the README.md the instructions for putting the binaries on the adapter have disappeared, I had to look in history on how to do.

bnzf, 2024-01-02:
PPS. The HP5370B manual says it uses IEEE Standard 488-1975, so the very first 488.

xyphro, 2024-01-02:
The sudden appearance of the /n in talk only vs. Listen+talk is a miracle to me.

Would you volunteer to help with a logic analyzer trace if I tell you what signals to monitor (ideally 16 channel, 8 would also work)? Of course only if you have one... in case you are in europe I could borrow/ship you a 16 channel fx2 based analyzer which works with sigrok.

xyphro, 2024-01-12:
Short update: Have just packed the shipment of the 16 channel logic analyzer + cable and will bring it to postbox tomorrow.

xyphro, 2024-01-13:
Today a friend came by with a HP5535a as a present. Not exactly the instrument that you have, but likely similar when it comes to age.
While you wait for the LA to arrive, I will check if I see similar behavior with that one!

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

xyphro, 2024-01-21:
...let me update here. We debugged the issue remotely and the cause is clear.

The instrument returns messages in the format:
`FRQ= 9.99999993500E+06<CR><LF>`

The GPIB read termination was set to <CR>. This resulted in messages returned in this format:

`<LF>FRQ= 9.99999993500E+06<CR>`

the print() will add also another termination.

The solution was:
1. configure gpib read termination as LF termination:
dev.control_in(0xa1, 0x40, 0, 0, 1); # set read termination to LF
dev.write('!term lf')
2. python can strip away read termination automatically, if it is correctly configured. So configuring it in this case like this strips it automagically away:
`dev.read_termination = '\r\n'`

Already with the 1st mentioned item the behavior in talk only and listen+talk mode was identical and no random inserted \r or \n were seen.

xyphro, 2024-01-21:
Closing the issue.

Closed 2024-01-21.

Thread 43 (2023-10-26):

Dos not apear as usb

yngve-hansen, 2023-10-26:
After setting fuses i cant get it to show up. Guess something went wrong but cant understand what.
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

xyphro, 2023-10-26:
Os ot possible that you already have the .bin file programmed too?
Maybe before you had set the fuses?

If so: it is expected defined behavior. It only appears on usb side when it is connected to an instrument and the instrument is powered up.

yngve-hansen, 2023-10-27:
Not so lucky, it dos not show up.

xyphro, 2023-10-27:
> Not so lucky, it dos not show up.
>

Can you explain a bit more?
Did it show up before?

What were your exact stepy?

yngve-hansen, 2023-10-27:
This is a new module, just initiuliced it and one more.
Same problem on bouth, Crystal is 16mhz.

xyphro, 2023-10-27:
> This is a new module, just initiuliced it and one more.
> Same problem on bouth, Crystal is 16mhz.
> still responsive on isp.

Do you use the board design I shared or is it some arduino module or so?

yngve-hansen, 2023-10-27:
It is your design nr w588420as1f1.

yngve-hansen, 2023-10-27:
I have 5 boards, orderd new. Same fault on the 2 first, will trye a 3 now, but dos not have high hopes.

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

xyphro, 2023-10-27:
w588420as1f1 is a number your PCB production company has added. JLCPCB does this for example.
You used the Kicad project files, which is a user contributed design. But it was reported to work.

The picture seems a bit blurry, C1 looks a bit misplaced. This will likely not be the reason.
Did you solder the IC with paste? So is the Thermal pad (=exposed die pad) connected?
Are the resistors R2 and R3 22 Ohm in value (maybe better measure it once with a multimeter (with USB cable disconnected)?
Does your PC detect the USB device in any way? If you use windows: Does it make any sound when you connect it?

Can you also check once if the XTAL oscillates really on 16 MHz when you connect it to USB? by probing with a scope? Not that it is a harmonic type or so.
You can measure it here (ensure to also have GND connected. You can also connect the aligator clip to the GPIB connector screws or so (better would be close to XTAL).
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

Fuses are a NIGHTMARE on the AVR controllers. Each programming tool has again a different definition (inverted / non inverted). Atmel should have defined a scheme where the fuses are part of the .HEX file... However, I just crosschecked the fuses again that you used and they are correct.

You can also try to flash this .hex file to see if it changes something: This is an image, where the bootloader and the UsbGpib application are combined in a single image. Note: This one will really only be visible to the PC when you really have it connected to a GPIB instrument and the GPIB instrument is powered on.
[GpibUsbCombined.zip](https://github.com/xyphro/UsbGpib/files/13192901/GpibUsbCombined.zip)

yngve-hansen, 2023-10-28:
r2 and r3 is 22 ohm, the crystal works(sinus) not tested frekvens.
Smd is solderd by JLCPCB connectors by me.
Windows dos not registrate it in any way.
Found the first problem, it is one command for the fuses and one for boot. They must be run seperatly.
Now it apear in System but missing driver. Will continue to morrow.

xyphro, 2023-10-28:
Install a visa like R&S visa:
https://www.rohde-schwarz.com/de/applikationen/r-s-visa-application-note_56280-148812.html

This one includes usbtmc driver.

xyphro, 2023-10-30:
Hvis den vises som en stasjon, betyr det at selve GPIB-applikasjonen fortsatt må blinke.  Hvordan det fungerer er beskrevet i readme.md.  Bare skriv inn copy testandmeasurement.bin F:\flash.bin på kommandolinjen.  F-stasjonen må åpenbart byttes ut med det GPIB-adapteren har.

yngve-hansen, 2023-10-30:
Mulig den ikke fult ut registrerer hp 54201a, registrerer vertfall ikke fluke 45 i det heletatt.
I enhetsbehandling dukker hp 5421a opp når det slås på.
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

xyphro, 2023-10-30:
Hei Yngve, det ser veldig bra ut. Det er normalt at USBTMC-enheter ikke vises etter navn i enhetsbehandlingen.
Men hvis du søker etter enheter i R&S Visa med testerapplikasjonen, vil de bli oppført der.

Alternativt kan du vise USBTMC-enheter med python og Pyvisa:

`import pyvisa
rm = pyvisa.ResourceManager()
print(rm.list_resources())
`
hvis en feil vises når du kaller import pyvisa-linjen, må pyvisa-pakken fortsatt installeres av:
`pip install pyvisa` samtaler

xyphro, 2023-10-30:
Her er et eksempel på hvordan det ser ut i enhetsbehandlingen min:
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

i NI-MAX vises den som en usbtmc-ressurs (jeg kan ikke bruke R&S Visa akkurat nå)
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

Og i Python ser det slik ut:
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

yngve-hansen, 2023-11-04:
Finner ikke drivere til mine instrumenter, mulig det er årsaken til at den ikke dukker opp i  filutforsker.
En annen mulighet er at det har med win11, men kan ikke bruke mere tid på dette nå.
Takker for support selv om det ble resultatløst.

Closed 2024-01-13.

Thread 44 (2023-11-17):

When will V2 release? :)

galaris, 2023-11-17:
Can't wait for early holidays ;D

xyphro, 2023-11-17:
Haha, stay tuned!

I made a stupid issue: i swapped odd and even pins so the connector has to mount on the wrong side, but: it works!

New pcbs are ordered, likely to arrive next week. Then I will test them immediately and release! Don't want to create a mess by releasing untested stuff.

Housing design is already finished. Busy printing 50 of them - takes multiple days :-(

Btw: i started working on speed upgrade. By a few risk free changes I got it from 85kB/s peak for writes to 400kBytes/s with room for more increase.
Reads are likely more important (waveform/screenshot downloads), those I will benchmark and improve also, likely significantly.

Never looked into speed before, but it is time for it! And I will also see how fast NI USB adapter is as comparison. Have built a dummy device doing the 3 wire handshake with logic ICs, so that pushback from the instrument does not influence the measurement.

xyphro, 2023-11-17:
If you cannot wait, I could drop you here already the stls of the new housing :-)

xyphro, 2023-11-20:
Update: Arrival of the fixed REV 2 board variant is scheduled for wednesday. In case there are no issues at customs.

xyphro, 2023-11-21:
Another update: received 50 pieces already today and will test this evening :-)

xyphro, 2023-11-21:
Test: succeeded, also with upcoming firmware.
Now i need some time to update git structure for the different hw revisions and documentation for it.

In case you cannot wait, send me a mail to xyphro@gmail.com and I'll mail it to you.

Best regards,

Kai

makeitsquare, 2023-12-14:
Hi,
awesome project! Thanks a lot for sharing! Are the Gerber files in HW/Gerber Files V2 for the Rev2 boards? I was expecting to see a rectangular PCB with a USB-C connector, but the V2 files are still for a L shaped PCB with a normal USB connector. So I guess Rev 2 != V2?
Thanks again,
Markus

xyphro, 2023-12-14:
The v2 is not yet released. I have however sent it already to a few users
and proven that it works. I am very busy on the sw side and did not have
time to restructure the site and write instructions yet.

makeitsquare ***@***.***> schrieb am Do., 14. Dez. 2023,
18:32:

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

xyphro, 2023-12-19:
It is done, the new hw and a sw release candidate is released (hooray ;-))

xyphro, 2023-12-19:
I have opened a discussion section and posted about the release here:
https://github.com/xyphro/UsbGpib/discussions

Any feedback is highly valued- on HW & on new SW release candidate.

For now I close this thread - you can add to the discussions section.

Closed 2023-12-19.

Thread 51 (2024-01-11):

V2 HW JLCPCB issue

mankangustafsson, 2024-01-11:
Hi, this is more of an FYI.

Dec 20, 2023 I ordered 5 2*7 panels from JLCPCB of the then just released V2 HW, using the Github gerber files.
Today I soldered the first one and failed to program it. GND and VCC are shorted, maybe I made a short on the USB connector. No, the switch is also shorted, i.e. GND and MOSI which I then found the reason for: The programming pads are too large and have shorted the nearby traces, see attached pictures.

I've filed a complaint with JLCPCB for the first time but meanwhile I wonder if there are any special instructions necessary for these gerbes to be properly made?

Best regards
Marcus
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

xyphro, 2024-01-12:
Hi Marcus,

Never seen this happening, but they clearly modified the Gerber content from what is in there. I mean others already built it without this effect.

No, there are no special instructions required. I ordered it just by dumping the Gerbers in the system - that's it.

Best regards,

Kai

xyphro, 2024-01-12:
I only see now that they even removed the bottom side pads. Curious to hear their explanation once you got it.

I made in total 4 production runs without issues of that design so far. The last 2 runs were also as panel with v scoring, however, they milled out parially the corner sections.

xyphro, 2024-01-12:
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

See here for explanation

xyphro, 2024-01-12:
Hi Again, Marcus... To entertain my curiosity I made an overlay of the PCB you received to the actual Gerber files that you refer too:
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

They did not increase the pad size, but shift the 3 pads - so they clearly modified the files.

mankangustafsson, 2024-01-12:
Thanks for the overlay, it might come in handy.

I downloaded the productions files and they clearly did the error when making the panels, see below.
/Marcus
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

xyphro, 2024-01-12:
Damn, that's frustrating. So next time better: self panelization. Which can be complex, despite the availability of scripts for it.

xyphro, 2024-01-13:
Hi Marcus,

if you don't mind, I will close this, as this is no UsbGpib design issue, but a vendor specific production issue.

Best regards,

Kai

mankangustafsson, 2024-01-13:
No problem at all. I have provided more information and pictures to JLC and I am convinced they will solve this. I will still update this issue about the final result

mankangustafsson, 2024-01-25:
After a few days of back and forth JLCPCB admitted that it all was their fault. They offered a coupon (8USD) for the PCBs while I wanted new PCBs shipped. I settled for one instead of five panels and cheap shipping. Yesterday the boards showed up with DHL Express and five panels in the package. I've now two V2 units up and running.

xyphro, 2024-01-26:
Perfect, so it was a stressful way with a happy ending. Thanks for sharing your experience!

Closed 2024-01-13.

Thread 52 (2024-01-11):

V2 HW BOM schema discprepancy

mankangustafsson, 2024-01-11:
Schema says R7 5.1k, BOM files says 10k. Which should it be? I assume this affects power usage signalling.
Best regards
Marcus

xyphro, 2024-01-12:
Hi Marcus,

Well spotted, will adjust it.
Good thing is that it will not affect functionality as this will not end up in a too low current beeing delivered to the port.

So I don't see a need to change the resistorvalue in case you mounted it already.

Best regards,

Kai

xyphro, 2024-01-13:
Hi Marcus,

I adjusted the BOM/CPL file, thanks for sharing - will push the updates in a few minutes!

Best regards,

Kai

Closed 2024-01-13.

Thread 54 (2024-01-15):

testing with Tektronix DSA 602A

jimthouston, 2024-01-15:
I'm using Linux, pyvisa and pyvisa-py.  I have had good luck testing with an HP-3478A and HP6642A.  Now testing with the DSA602A I'm seeing some odd behavior including a  consistent hang when the python script exits.

$ cat t1.py
`import pyvisa
rm = pyvisa.ResourceManager()
print(rm.list_resources())
`
$ python3 t1.py
('USB1::0x03eb::0x2065::GPIB_01_34231323231351E04071',)
^C
$

I captured a system call trace and the last system call before I use '^C'
is:
futex(0x7f939c5ee664, FUTEX_WAIT_PRIVATE, 12, NULL) = ? ERESTARTSYS

I also tried using the "-m pdb" debugger option.  I had hoped that it would drop me in the debugger when I interrupted the hang.  Instead it puts me into the debugger when the program exits and would run the program again when I continue.

Before I updated to the latest UsbGpib firmware I was also having a problem with my Lenovo T470 laptop hanging on power on with the UsbGpib connected to the DSA602A.  It got stuck displaying "to interrupt the normal boot sequence, hit Enter".  I could boot if I disconnected either the USB or the DSA 602A.  I have not seen this problem with the new firmware.

xyphro, 2024-01-15:
Hi Jim,

not sure how that can be related to the adapter itself, but I don't want to say yet that I am 100% confident on this statement - so let's investigate!
But to explain: There is 0 interaction on GPIB side when you do an instrument scan, this is why I think a bit that it is not dependent on the adapter.

Is t1.py really only consisting out of the 3 commands?
What I see is that the print seems finalized cause the bracket closes.
Can you maybe add a 4th line with a print?

Does your Visa tool of choice list the instrument properly?
Can you tell me a bit more, like e.g. which visa provider you use?
Is this using pyvisa-py? I see you use Linux, right?

A capture with wireshark and usbpcap while running your script could help a lot to trace this down.

ERESTARTSYS does not neccesarily point to a cause here unfortunately.

Best regards,

Kai

xyphro, 2024-01-15:
BTW: you are not saying it explicitely... But what happens when you run the script without the adapter beeing attached?

xyphro, 2024-01-15:
BTW: Pyvisa-py had quite some issues in the past on USBTMC and the implementation is very basic. I would not use it anymore after having run into issues, but can of course understand if you do this...

R&S Visa is an excellent choice also for Linux and works nice with USB. It is also not that bloated as other options...

jimthouston, 2024-01-15:
I'm sorry I probably should have done more testing before posting.
I switched computers when I started testing with the DSA602A.  I just tried connecting the second computer to the HP3478A and I have the hang with the HP3478A  and also with the HP3478A powered off.  I wasn't having the problem with the pyvisa and pyvisa-py on the first computer.

So I agree that this is likely to be a pyvisa/pyvisa-py bug not a UsbGpib problem.  If you can leave this open for a while I expect that I will track down the issue eventually.

xyphro, 2024-01-15:
Thanks for the update Jim, i will leave it indeed open until we have full confidence! Curious what your investigation will show.

jimthouston, 2024-01-16:
I used pyvisa-info on both systems and found that I had installed the librevisa library on the system which has the hang problem.
The dpkg.log shows I did this in 2022 but I don't remember.

I tried using pyvisa.ResourceManager('@py') to force the use of pyvisa-py and it doesn't hang.  So the problem is with the librevisa library.

xyphro, 2024-01-16:
Thanks for the update Jim! So it is unrelated to the GPIB Adapter.
In case you see anything else popping up, please report again!

Closed 2024-01-16.

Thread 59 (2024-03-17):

query the string length setting always returns "normal"

mt1970, 2024-03-17:
Hi,

With parameter setting '!string short' , the query '!string?' always returns "normal".

Maurice

xyphro, 2024-03-17:
Hi Maurice,

thanks for reporting, I will check during this week.

Best regards,

Kai

xyphro, 2024-03-17:
[TestAndMeasurement_Dazz&Maurice.zip](https://github.com/xyphro/UsbGpib/files/14628407/TestAndMeasurement_Dazz.Maurice.zip)

Hi Maurice,

this one was easy to spot.
It is fixed - can you try?

Best regards,

Kai

mt1970, 2024-03-17:
Hello Kai,
It works.
Thanks for the fast update.

Maurice

xyphro, 2024-03-17:
Welcome, thanks for trying!

I will commit this firmware update once the other issue which Dazz reported is sorted out.

dazz100, 2024-03-18:
Hi

I can now repeat the test script without issue.  So the test firmware has fixed that problem.
I think this fix has revealed or created a similar issue.

I plugged the adapter into the usb. I then switched on the emc-30 and ran the script.   Running the script put the emc30 into remote mode.  The following output is normal and correct.

```
D:\darren\My Documents\Electronics\Electro-Metrics EMC-30\GPIB_Test>python EMC30_gpib_rd_STATUS.py
###### Simple GPIB test for emc30
# Executes read STATUS

# Show the list of Resources
('USB0::0x03EB::0x2065::GPIB_15_24238323232351C01171::INSTR', 'ASRL1::INSTR')
# Opening the emc30

Set Auto ID = off
Set Line Feed = on
Save settings to eeprom
Read emc-30 status
55
```
The following output is not correct.  This occurred after I front panel switched to local mode.

```
D:\darren\My Documents\Electronics\Electro-Metrics EMC-30\GPIB_Test>python EMC30_gpib_rd_STATUS.py
###### Simple GPIB test for emc30
# Executes read STATUS

# Show the list of Resources
('ASRL1::INSTR',)
# Opening the emc30
Traceback (most recent call last):
  File "D:\darren\My Documents\Electronics\Electro-Metrics EMC-30\GPIB_Test\EMC30_gpib_rd_STATUS.py", line 30, in <module>
    emc30 = rm.open_resource('USB0::0x03EB::0x2065::GPIB_15_24238323232351C01171::INSTR', send_end=False,)
            ^^^^^^^^^^^^^^^^^^^^^^^^^^^^^^^^^^^^^^^^^^^^^^^^^^^^^^^^^^^^^^^^^^^^^^^^^^^^^^^^^^^^^^^^^^^^^^
  File "G:\Programs\Python310\Lib\site-packages\pyvisa\highlevel.py", line 3292, in open_resource
    res.open(access_mode, open_timeout)
  File "G:\Programs\Python310\Lib\site-packages\pyvisa\resources\resource.py", line 281, in open
    self.session, status = self._resource_manager.open_bare_resource(
                           ^^^^^^^^^^^^^^^^^^^^^^^^^^^^^^^^^^^^^^^^^^
  File "G:\Programs\Python310\Lib\site-packages\pyvisa\highlevel.py", line 3217, in open_bare_resource
    return self.visalib.open(self.session, resource_name, access_mode, open_timeout)
           ^^^^^^^^^^^^^^^^^^^^^^^^^^^^^^^^^^^^^^^^^^^^^^^^^^^^^^^^^^^^^^^^^^^^^^^^^
  File "G:\Programs\Python310\Lib\site-packages\pyvisa\ctwrapper\functions.py", line 1850, in open
    ret = library.viOpen(
          ^^^^^^^^^^^^^^^
  File "G:\Programs\Python310\Lib\site-packages\pyvisa\ctwrapper\highlevel.py", line 226, in _return_handler
    return self.handle_return_value(session, ret_value)  # type: ignore
           ^^^^^^^^^^^^^^^^^^^^^^^^^^^^^^^^^^^^^^^^^^^^
  File "G:\Programs\Python310\Lib\site-packages\pyvisa\highlevel.py", line 251, in handle_return_value
    raise errors.VisaIOError(rv)
pyvisa.errors.VisaIOError: VI_ERROR_RSRC_NFOUND (-1073807343): Insufficient location information or the requested device or resource is not present in the system.
```
Unplugging/plugging (cycling power) the adapter usb does not restore normal operation.

Running the test script with the adapter connected to the usb and the adapter plugged into the emc-30 gpib bus, but with the emc-30 switched off, produces the same faulty output.  The output errors long before the script reaches the code where a command is sent to the emc-30.

When I start with power switched off on the emc-30 and the adapter usb disconnected, I can no longer get normal output.

My hypothesis is that saving the settings in the adapter somehow causes an issue.

My next test is to reprogram the adapter firmware and run the script again.  My aim is to be able to reproduce the issue.

dazz100, 2024-03-18:
Hi
I reprogrammed the firmware in the adapter, then repeated the actions that produce correct output.
I plugged the adapter into the OFF emc-30.
I plugged the adapter into the usb port.
I powered the emc 30 and did not touch and front panel controls.
I ran the script, which produced errored output.

```
D:\darren\My Documents\Electronics\Electro-Metrics EMC-30\GPIB_Test>python EMC30_gpib_rd_STATUS.py
###### Simple GPIB test for emc30
# Executes read STATUS

# Show the list of Resources
('ASRL1::INSTR',)
# Opening the emc30
Traceback (most recent call last):
  File "D:\Electro-Metrics EMC-30\GPIB_Test\EMC30_gpib_rd_STATUS.py", line 30, in <module>
    emc30 = rm.open_resource('USB0::0x03EB::0x2065::GPIB_15_24238323232351C01171::INSTR', send_end=False,)
            ^^^^^^^^^^^^^^^^^^^^^^^^^^^^^^^^^^^^^^^^^^^^^^^^^^^^^^^^^^^^^^^^^^^^^^^^^^^^^^^^^^^^^^^^^^^^^^
  File "G:\Programs\Python310\Lib\site-packages\pyvisa\highlevel.py", line 3292, in open_resource
    res.open(access_mode, open_timeout)
  File "G:\Programs\Python310\Lib\site-packages\pyvisa\resources\resource.py", line 281, in open
    self.session, status = self._resource_manager.open_bare_resource(
                           ^^^^^^^^^^^^^^^^^^^^^^^^^^^^^^^^^^^^^^^^^^
  File "G:\Programs\Python310\Lib\site-packages\pyvisa\highlevel.py", line 3217, in open_bare_resource
    return self.visalib.open(self.session, resource_name, access_mode, open_timeout)
           ^^^^^^^^^^^^^^^^^^^^^^^^^^^^^^^^^^^^^^^^^^^^^^^^^^^^^^^^^^^^^^^^^^^^^^^^^
  File "G:\Programs\Python310\Lib\site-packages\pyvisa\ctwrapper\functions.py", line 1850, in open
    ret = library.viOpen(
          ^^^^^^^^^^^^^^^
  File "G:\Programs\Python310\Lib\site-packages\pyvisa\ctwrapper\highlevel.py", line 226, in _return_handler
    return self.handle_return_value(session, ret_value)  # type: ignore
           ^^^^^^^^^^^^^^^^^^^^^^^^^^^^^^^^^^^^^^^^^^^^
  File "G:\Programs\Python310\Lib\site-packages\pyvisa\highlevel.py", line 251, in handle_return_value
    raise errors.VisaIOError(rv)
pyvisa.errors.VisaIOError: VI_ERROR_RSRC_NFOUND (-1073807343): Insufficient location information or the requested device or resource is not present in the system.
```

I noticed an error in the output of AVRdude:

```
G:\Programs\avrdude-v7.1\test_20240318>..\avrdude -c usbasp -p m32u4 -e -Ulock:w:0x3F:m -Uefuse:w:0xcb:m -Uhfuse:w:0xd8:m -Ulfuse:w:0xff:m -U flash:w:TestAndMeasurement.bin -U flash:w:BootLoader.hex

avrdude: AVR device initialized and ready to accept instructions
avrdude: device signature = 0x1e9587 (probably m32u4)
avrdude: erasing chip
avrdude: reading input file 0x3F for lock
         with 1 byte in 1 section within [0, 0]
avrdude: writing 1 byte lock ...
 ***failed;
avrdude: 1 byte of lock written
avrdude: verifying lock memory against 0x3F
avrdude warning: ignoring mismatch in unused bits of lock
        (device 0xff != input 0x3f); to prevent this warning set
        unused bits to 1 when writing (double check with datasheet)
avrdude: 1 byte of lock verified
avrdude: reading input file 0xcb for efuse
         with 1 byte in 1 section within [0, 0]
avrdude: writing 1 byte efuse ...
 ***failed;
avrdude: 1 byte of efuse written
avrdude: verifying efuse memory against 0xcb
avrdude warning: ignoring mismatch in unused bits of efuse
        (device 0xfb != input 0xcb); to prevent this warning set
        unused bits to 1 when writing (double check with datasheet)
avrdude: 1 byte of efuse verified
avrdude: reading input file 0xd8 for hfuse
         with 1 byte in 1 section within [0, 0]
avrdude: writing 1 byte hfuse ...
avrdude: 1 byte of hfuse written
avrdude: verifying hfuse memory against 0xd8
avrdude: 1 byte of hfuse verified
avrdude: reading input file 0xff for lfuse
         with 1 byte in 1 section within [0, 0]
avrdude: writing 1 byte lfuse ...
avrdude: 1 byte of lfuse written
avrdude: verifying lfuse memory against 0xff
avrdude: 1 byte of lfuse verified
avrdude: reading input file TestAndMeasurement.bin for flash
         with 13718 bytes in 1 section within [0, 0x3595]
         using 108 pages and 106 pad bytes
avrdude: writing 13718 bytes flash ...

Writing | ################################################## | 100% 6.87 s

avrdude: 13718 bytes of flash written
avrdude: verifying flash memory against TestAndMeasurement.bin

Reading | ################################################## | 100% 8.43 s

avrdude: 13718 bytes of flash verified
avrdude: reading input file BootLoader.hex for flash
         with 5724 bytes in 5 sections within [0x6000, 0x7fff]
         using 46 pages and 164 pad bytes
avrdude: writing 5724 bytes flash ...

Writing | ################################################## | 100% 0.15 s

avrdude: 5724 bytes of flash written
avrdude: verifying flash memory against BootLoader.hex

Reading | ################################################## | 100% 0.02 s

avrdude: 5724 bytes of flash verified

avrdude done.  Thank you.

```

xyphro, 2025-01-11:
I am committing the firware binary and source in a few minutes containing the fix.

Closed 2025-01-11.

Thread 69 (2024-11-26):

My fault - Issue with housing

TPPTim, 2024-11-26:
Hello xyphro,
First of all, thank you so much for this great project!
I am building one of your USBGPIB devices for my multimeter.
Unfortunately I found out that the smd microswitches ([https://de.aliexpress.com/item/1005004297433455.html](https://de.aliexpress.com/item/1005004297433455.html) Version 6) I ordered are a bit higher than yours.
So the case will not fit together...

I could not find a way to contact you directly on GitHub. - Sorry to open an issue.

Could you please send me the STP file of the case so I can change the button cutout so that the PCB will fit.

Thank you very much!
Tim

xyphro, 2025-01-11:
Hi Tim,

I will push a new update in a few minutes and the Fusion 360 file will end up in the Housing/REV2 path with filename XyphroUsbGpibRev2_housing_part2.f3d.

You can create other formats like STEP file by installing Fusion 360.

Best regards,

Kai

Closed 2025-01-11.

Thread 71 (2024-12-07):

REV 2 housing captive nuts

JasonMorris1, 2024-12-07:
I'm finding the captive nut slot for the m3 nuts to be a bit large.  The nut is very loose and starts to spin If I tighten them to much. Could you please reduce the size slightly? Thanks.

xyphro, 2025-01-11:
Hi Jason,

such things are very dependent on the printer used. Changing it for everybody in the right way will be difficult. Also other paramters like the cavity for the PCB can be dependent on the actual printer. The Nut used is a standard DIN934 M3 nut.

With housings printed with JlcPcb, on Bambu P1S, Creality K1, Creality Ender 5 it fits quite well.

I understand your difficulty, but suggest you change the nut cavity yourself to match your actual nut size.

Best regards,

Kai

xyphro, 2025-01-11:
Note that I will put the Fusion 360 file in a few minutes under housing/REV2/XyphroUsbGpibRev2_housing_part2.f3d

This will enable you and others to do edits yourself.

Closed 2025-01-11.

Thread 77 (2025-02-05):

Pyvisa script hangs after 45-60 minutes when talking to two UsbGpib adapters

ned-pcs, 2025-02-05:
I have to do overnight logging of experimental values from two older bench multimeters. I have two UsbGpib adapters using what I believe is the latest firmware. I will check shortly.

The problem is that the scripts will run properly for 45-55 minutes or so and then hang in a way that I haven't been able to catch programmatically.

My Python script is using PyVisa and I have no other back-end drivers installed on my Mac OS 15.2 (Mac Mini M1) system.

The meters are an HP 34401A (in native mode) and a Fluke 8442A.

The script gets readings from both meters every 10 seconds. When it hangs I can't interrupt the program using Ctrl-C but instead have to suspend it and kill it.

I am using `asyncio.timeout()` around the `query()` calls to catch timeouts while waiting to read from the adapters, but these aren't catching the problem:

```
async def read_ac_current():
    async with asyncio.timeout(QUERY_TIMEOUT):
        return float(hp.query('READ?'))

async def read_batt_current():
    async with asyncio.timeout(QUERY_TIMEOUT):
        return float(fluke.query('?'))
```

I will check the FW revision and update the firmware on the adapters shortly.

Beyond that, what can I do to diagnose/fix this issue? I could test under Linux using a Raspberry Pi 5 if that'd help.

ned-pcs, 2025-02-05:
This may be due to the system sleeping. I just turned off system sleep when the display goes to sleep; will see if that helps.

xyphro, 2025-02-11:
Hi!

Something like this immediately triggers my attention. I tested a lot also standby/sleep survival. A hand is absolutely unacceptable and has to be ressolved if it is caused by the adapter.

In case you have a script to try, OS information and which Visa you use please share with me if you can. You can also mail to xyphro at gmail dot com.

Any updates on your investigation are very welcome.

Best regards,

Kai

xyphro, 2025-02-11:
Are you using real pyvisa or pyvisa-py?

pyvisa-py has some issues, like incomplete USBTMC implementation or not fully correct USBTMC error handling.

(I hope nobody complains now, but I had bad experience with it, also outside of the USB-GPIB context)

xyphro, 2025-02-11:
> Beyond that, what can I do to diagnose/fix this issue? I could test under Linux using a Raspberry Pi 5 if that'd help.

The issue is that I cannot reproduce anything under Mac OSX, as my only Mac machine is that old, that I had to install linux on it to make still use of it.

If we can make this reproduceable under any different OS, it would help. E.g. Intel+Windows, Intel+Linux, Raspberry Pi 3..4..5 + linux.

Can't remember, but does Mac OSX have dmesg? See anything related to USB there?
Do you need to unplug the usbgpib to make it "talk" again or is killing the python instance and starting it again all you need?

If you use pyvisa-py, can you try a proper visa [1]+ normal pyvisa?

[1] Any of your prefrence, e.g. NI, R&S. Better go with R&S Visa as that one does not need 1 GByte of harddisc space.

ned-pcs, 2025-02-13:
Sorry I didn't get back here. The problem was indeed with system sleeping. Turning off system sleep got rid of the problem.

xyphro, 2025-02-13:
> Sorry I didn't get back here. The problem was indeed with system sleeping. Turning off system sleep got rid of the problem.

Thanks for update. For self-learning: did you use pyvisa + external visa or pyvisa-py?

Closed 2025-02-13.

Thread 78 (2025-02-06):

A collection of small observations and issues

bryanparadis, 2025-02-06:
1. Couldn't really find a good source the USB-C port for Rev 2 but I think DX07S016JA3R1500 looks like it's a match foot print and layout wise.
2. [C7 in V2 BoM ](https://github.com/xyphro/UsbGpib/blob/master/HW/REV2/BOM-xyp-gpib.csv#L5) should be 1uF not 1u
3. C7 in V2 HTML BoM same thing
4. [Component sourcing section](https://github.com/xyphro/UsbGpib?tab=readme-ov-file#component-sourcing) does not match V2 and was a bit confusing to read at first
5. GPIB connector isn't in V2 BoM at all

I created a list on Digikey https://www.digikey.ca/en/mylists/list/QU9XX4NWSD but have not yet built a board so ymmv

bryanparadis, 2025-02-06:
Also wondering if there is information about PCB options and thickness? Going to take a look at the model to see how much room there is. Have never ordered a PCB before so it could get interesting (:

bryanparadis, 2025-02-06:
DIN934 M3 captive nuts and screws could be added to the bom possibly?

bryanparadis, 2025-02-06:
https://www.digikey.ca/en/products/detail/norcomp-inc/111-024-113L001/955147

Will this one work for REV 2?

xyphro, 2025-02-11:
> Couldn't really find a good source the USB-C port for Rev 2 but I think DX07S016JA3R1500 looks like it's a match foot print and layout wise.

A partnumber is included in the BOM csv file. C2936185 from LCSC/JLCPCB.
This is a very common connector, you'll find plenty of the same ones.

> C7 in V2 BoM should be 1uF not 1u
> C7 in V2 HTML BoM same thing

Will delete that HTML BOM soon.

> GPIB connector isn't in V2 BoM at all

For reasons: It can only be mounted by hand. e.g. selective wave soldering is not possible as the SMD components are too close.
To avoid any issues, I excluded the connector.

> Also wondering if there is information about PCB options and thickness? Going to take a look at the model to see how much room there is. Have never ordered a PCB before so it could get interesting (:

Standard 1.6mm.

Keep your life easy, order at JlcPCB. BOM-xyp-gpib.csv, CPL-xyp-gpib.csv and the Gerber files are all in the REPO. Zip the gerbers, upload it, select PCBA, upload the BOM and CPL and that's all you need to get fully SMD mounted PCB(s) back.
No need to do classical sourcing with Farnell, Digikey, Mouser. If I remember it will cost you ~15 USD for small volumes per piece. Just order 2 screws, 2 nuts and the GPIB connector seperately, print the STL files and you are ready.

> DIN934 M3 captive nuts and M3x20 screws could be added to the bom possibly? I see they are on the Rev 2 readme page.

I'd like to keep the BOM for the PCB only.

> https://www.digikey.ca/en/products/detail/norcomp-inc/111-024-113L001/955147
> Will this one work for REV 2?

Yes sir! This partnumber is written in the schematic.
Most people order that one from AliExpress "get a USB connector "24P Male solder type" from e.g. Aliexpress"

bryanparadis, 2025-02-12:
> A partnumber is included in the BOM csv file. C2936185 from LCSC/JLCPCB. This is a very common connector, you'll find plenty of the same ones.

Couldn't source or find a substitute by using either number or manufacturer part number. I had to manually search for a part on Digikey that fit the same footprint and pinout. Is LCSC common? I see the JLCPCB has it listed.

> For reasons: It can only be mounted by hand. e.g. selective wave soldering is not possible as the SMD components are too close. To avoid any issues, I excluded the connector.

Yeah process wise this makes sense.

> Standard 1.6mm.

I figured it must be standard after doing some measurements in the 3d model. Luckily I ordered correctly. Thanks for the confirmation.

> Keep your life easy, order at JlcPCB. BOM-xyp-gpib.csv, CPL-xyp-gpib.csv and the Gerber files are all in the REPO. Zip the gerbers, upload it, select PCBA, upload the BOM and CPL and that's all you need to get fully SMD mounted PCB(s) back. No need to do classical sourcing with Farnell, Digikey, Mouser. If I remember it will cost you ~15 USD for small volumes per piece. Just order 2 screws, 2 nuts and the GPIB connector seperately, print the STL files and you are ready.

That is a very succinct set of instructions. I would do just that but I've got bare PCB in hand now and all the parts I need coming from Digikey.

> I'd like to keep the BOM for the PCB only.

I mean there is a BOM for the PCB and there is a BOM for entirety of the product. Currently the information is split up. My feedback really is it was hard to find everything that I need to put together one of these.

> Yes sir! This partnumber is written in the schematic. Most people order that one from AliExpress "get a USB connector "24P Male solder type" from e.g. Aliexpress"

Aliexpress just takes to long to arrive. Sometimes upwards of 3-4 months if it goes through the UAE on it's way to Canada. I order from there if it's worth the wait only/can't get it from newark/digikey/mouser.

bryanparadis, 2025-02-17:
For anyone that reads this:

The pinout in LCSC schematic is pretty much unreadable.
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

Also DX07S016JA3R1500 is not a match pinout wise. Trying USB4105-GF-A which does seem to match properly and share the same footprint. I updated my Digikey bom.

xyphro, 2025-02-17:
Hi Bryan,

this project is made fully for free and everybody is able to make a pull request to improve and I value those a lot. 95% want jlcpcb one stop shop which is provided, I prefer farnell, others local vendors like Reichelt and others again Mouser/Digikey. Maintaining all this information continously to be consistent is difficult for just a hobby project which makes 0 income.

After 6+ years there were only a hand full of pull requests while thousands have built this circuit already.

If you want production quality BOM for your vendor I am happy to add it once I see a pull request.

Best regards,

Kai

bryanparadis, 2025-02-18:
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

I like the project but it was hard to figure out how to build to be honest. I may open a PR with improvements after I get a working version on hand. Though the last PR was merged in 2022 and there are 6 open ones.

Closed 2025-02-11.

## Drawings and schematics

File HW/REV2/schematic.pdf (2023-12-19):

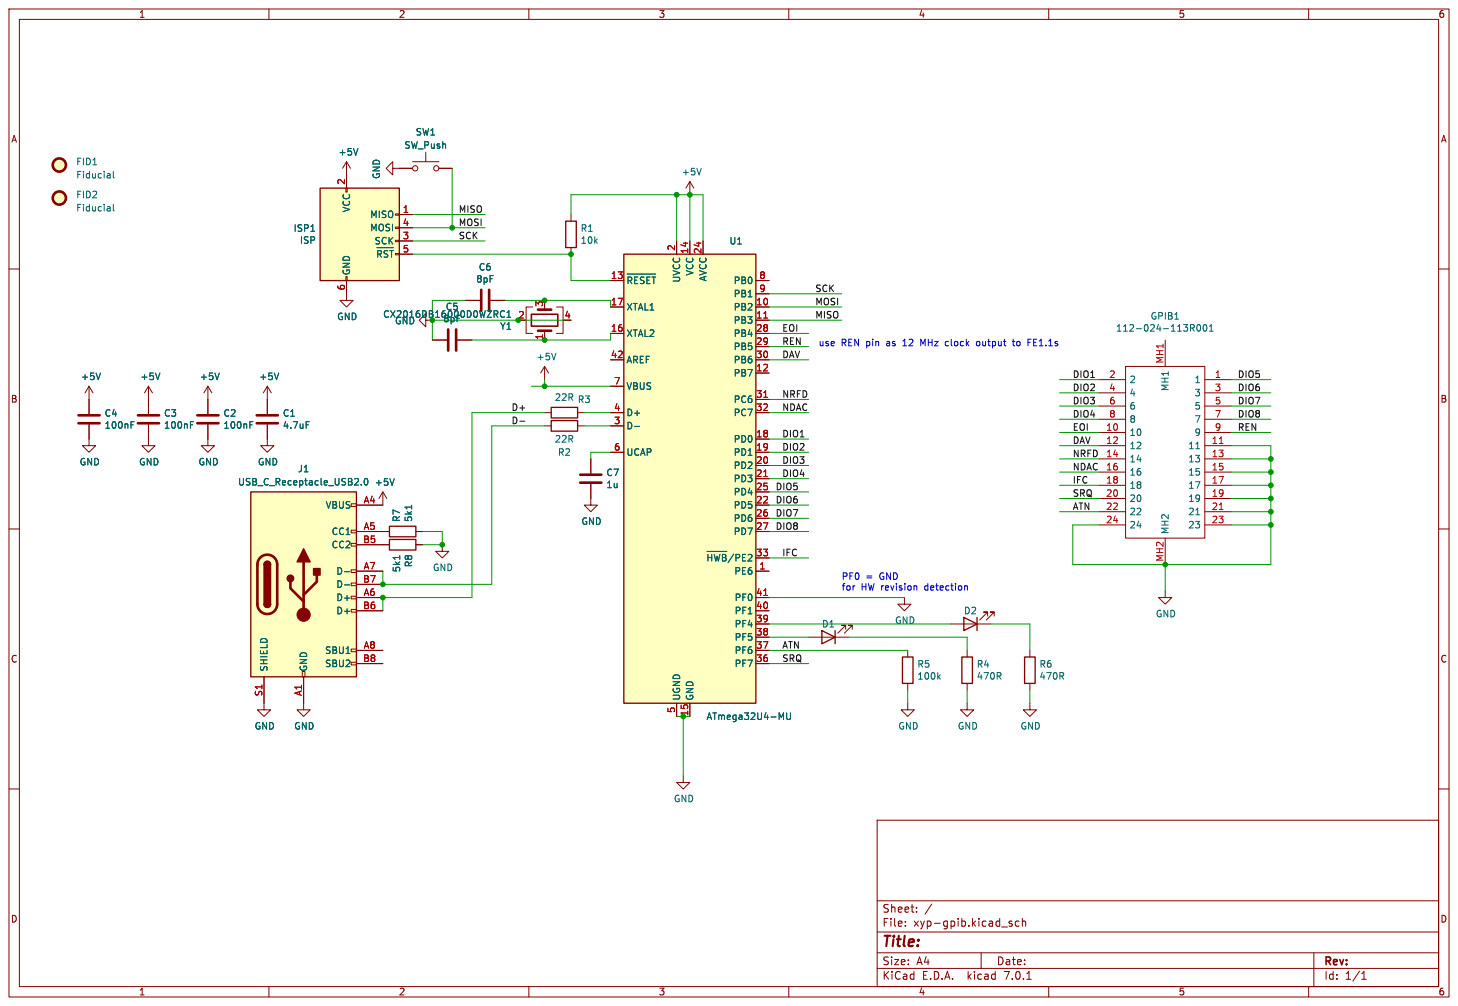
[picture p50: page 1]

2 SCK 3 MOSI 4 ~{RST}5 GND

PF0 = GND
for HW revision detection

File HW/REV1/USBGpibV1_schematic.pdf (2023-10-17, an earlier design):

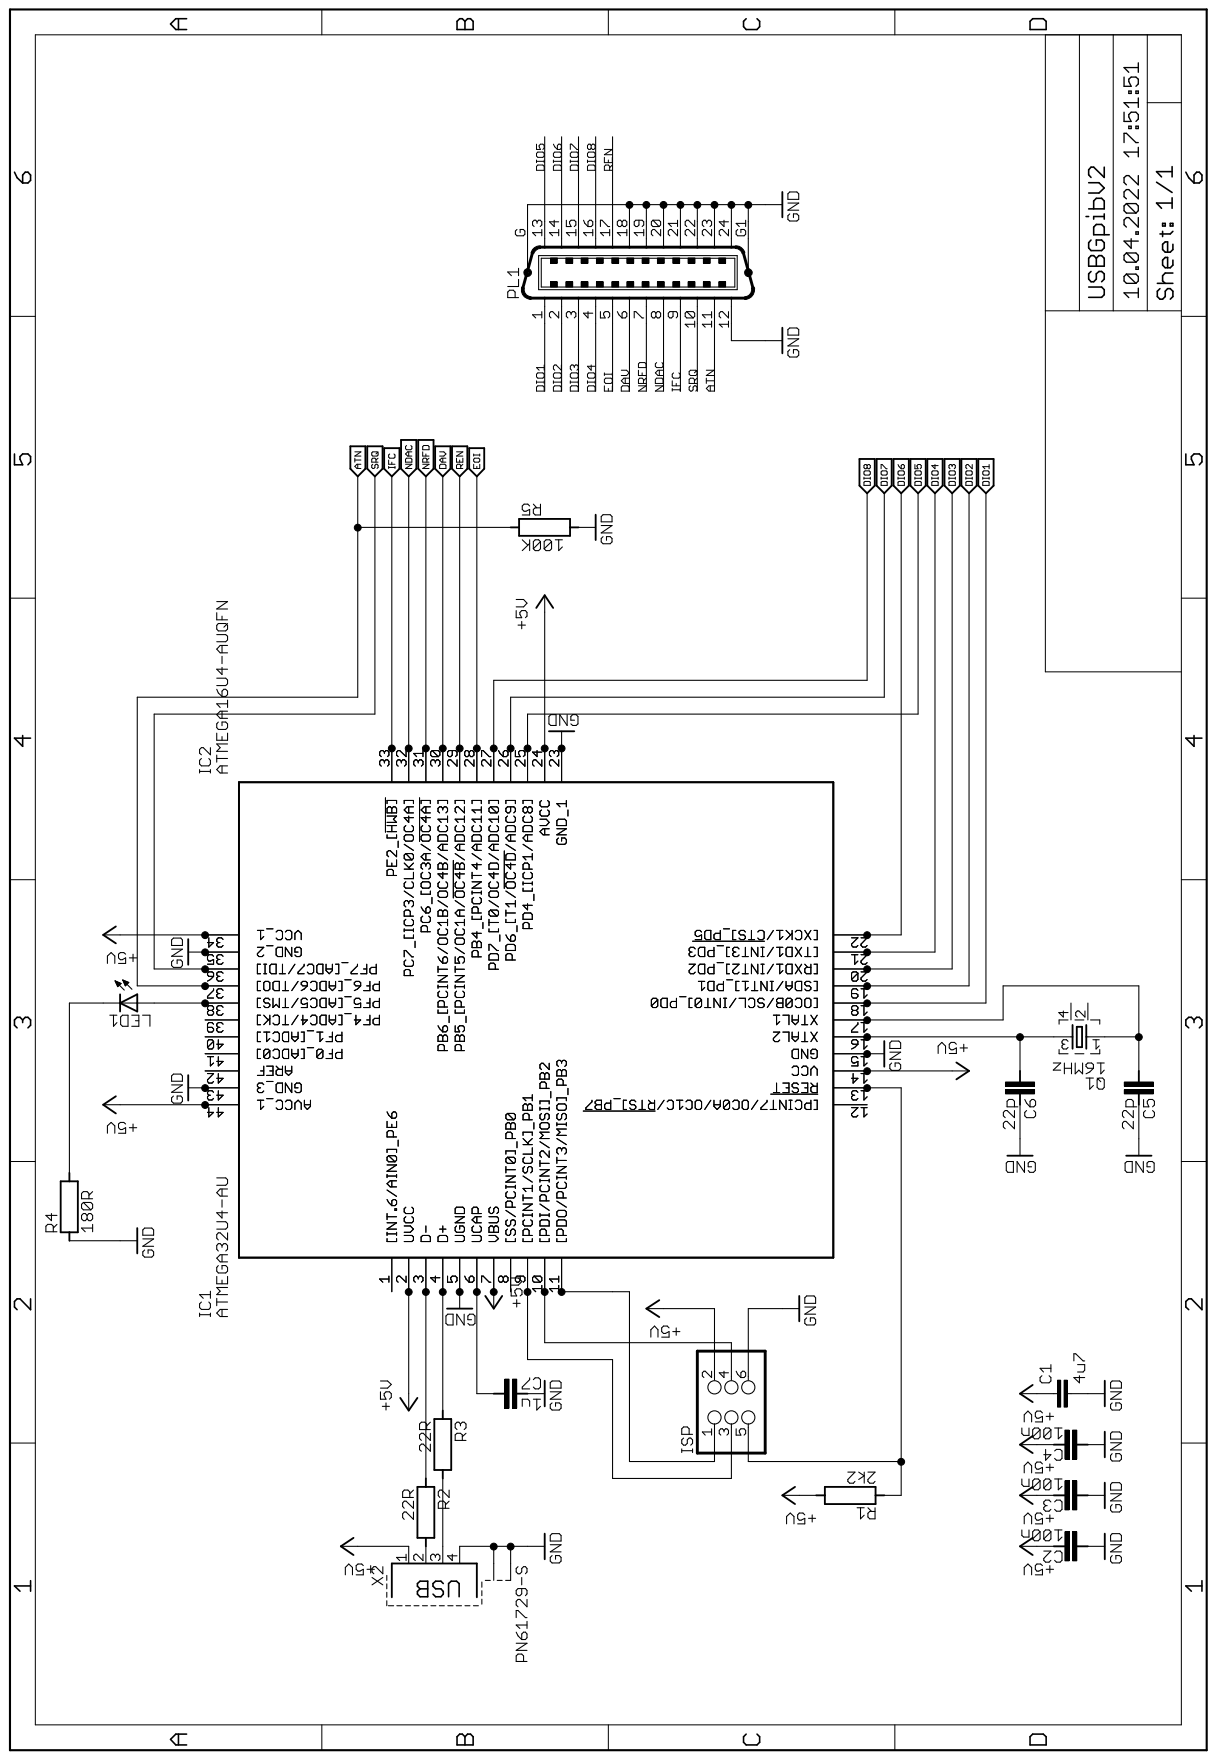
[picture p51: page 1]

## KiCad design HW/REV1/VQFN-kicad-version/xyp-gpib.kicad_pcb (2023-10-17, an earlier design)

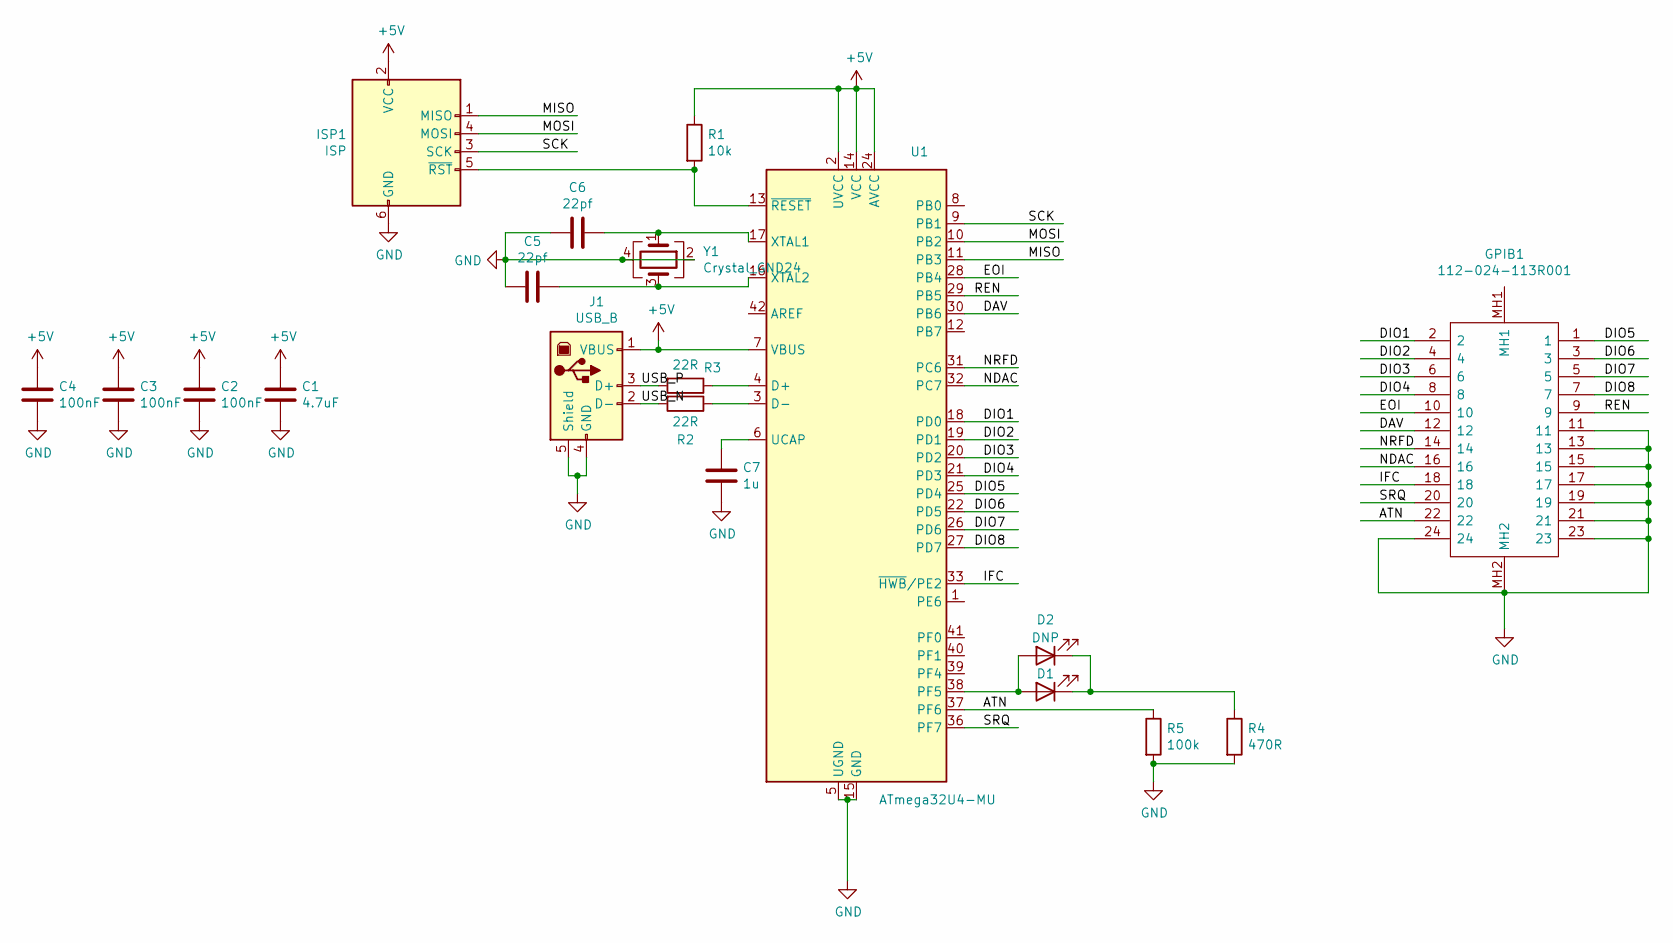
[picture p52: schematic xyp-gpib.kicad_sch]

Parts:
C1: 4.7uF; C_0805_2012Metric
C2, C3, C4: 100nF; C_0603_1608Metric
C5, C6: 22pf; C_0603_1608Metric
C7: 1u; C_0603_1608Metric
D1: LED; LED_0805_2012Metric
D2: DNP; LED_0805_2012Metric
GPIB1: 112-024-113R001; 112024113R001; Manufacturer_Part_Number 112-024-113R001; Mouser Part Number 636-112-024-113R001
ISP1: ISP; IDC-Header_2x03_P2.54mm_Vertical
J1: USB_B; USB_B_Lumberg_2411_02_Horizontal
R1: 10k; R_0603_1608Metric
R2, R3: 22R; R_0603_1608Metric
R4: 470R; R_0603_1608Metric
R5: 100k; R_0603_1608Metric
U1: ATmega32U4-MU; QFN-44-1EP_7x7mm_P0.5mm_EP5.2x5.2mm
Y1: Crystal_GND24; Crystal_SMD_3225-4Pin_3.2x2.5mm

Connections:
+5V: C1.1, C2.1, C3.1, C4.1, ISP1.2 (VCC), J1.1 (VBUS), R1.1, U1.2 (UVCC), U1.7 (VBUS), U1.14 (VCC), U1.24 (AVCC), U1.34 (VCC), U1.44 (AVCC)
/ATN: GPIB1.22, R5.1, U1.37 (PF6)
/DAV: GPIB1.12, U1.30 (PB6)
/DIO1: GPIB1.2, U1.18 (PD0)
/DIO2: GPIB1.4, U1.19 (PD1)
/DIO3: GPIB1.6, U1.20 (PD2)
/DIO4: GPIB1.8, U1.21 (PD3)
/DIO5: GPIB1.1, U1.25 (PD4)
/DIO6: GPIB1.3, U1.22 (PD5)
/DIO7: GPIB1.5, U1.26 (PD6)
/DIO8: GPIB1.7, U1.27 (PD7)
/EOI: GPIB1.10, U1.28 (PB4)
/IFC: GPIB1.18, U1.33 (~HWB/PE2)
/MISO: ISP1.1 (MISO), U1.11 (PB3)
/MOSI: ISP1.4 (MOSI), U1.10 (PB2)
/NDAC: GPIB1.16, U1.32 (PC7)
/NRFD: GPIB1.14, U1.31 (PC6)
/REN: GPIB1.9, U1.29 (PB5)
/SCK: ISP1.3 (SCK), U1.9 (PB1)
/SRQ: GPIB1.20, U1.36 (PF7)
/USB_N: J1.2 (D-), R2.2
/USB_P: J1.3 (D+), R3.2
GND: C1.2, C2.2, C3.2, C4.2, C5.2, C6.2, C7.2, GPIB1.11, GPIB1.13, GPIB1.15, GPIB1.17, GPIB1.19, GPIB1.21, GPIB1.23, GPIB1.24, GPIB1.MH2, ISP1.6 (GND), J1.4 (GND), J1.5 (Shield), R4.2, R5.2, U1.5 (UGND), U1.15 (GND), U1.23 (GND), U1.35 (GND), U1.43 (GND), U1.45 (GND), Y1.2, Y1.4
unnamed: C5.1, U1.16 (XTAL2), Y1.3
unnamed: C6.1, U1.17 (XTAL1), Y1.1
unnamed: C7.1, U1.6 (UCAP)
unnamed: D1.1 (K), D2.1 (K), R4.1
unnamed: D1.2 (A), D2.2 (A), U1.38 (PF5)
unnamed: ISP1.5 (~RST), R1.2, U1.13 (~RESET)
unnamed: R2.1, U1.3 (D-)
unnamed: R3.1, U1.4 (D+)

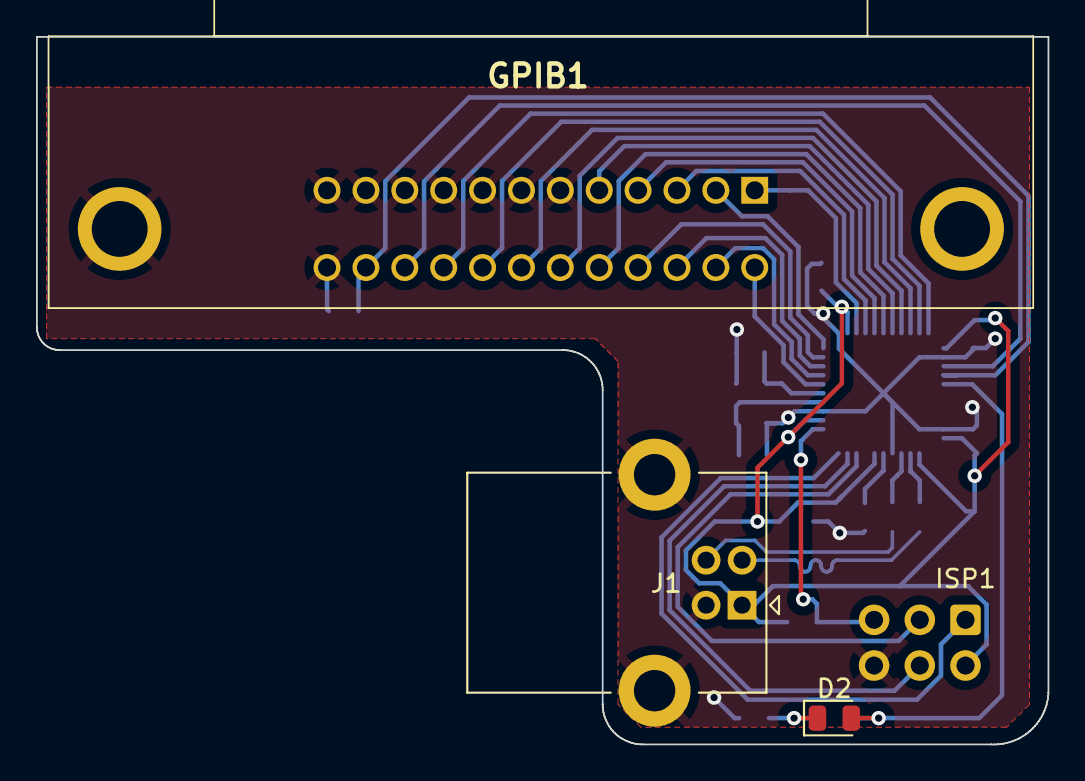
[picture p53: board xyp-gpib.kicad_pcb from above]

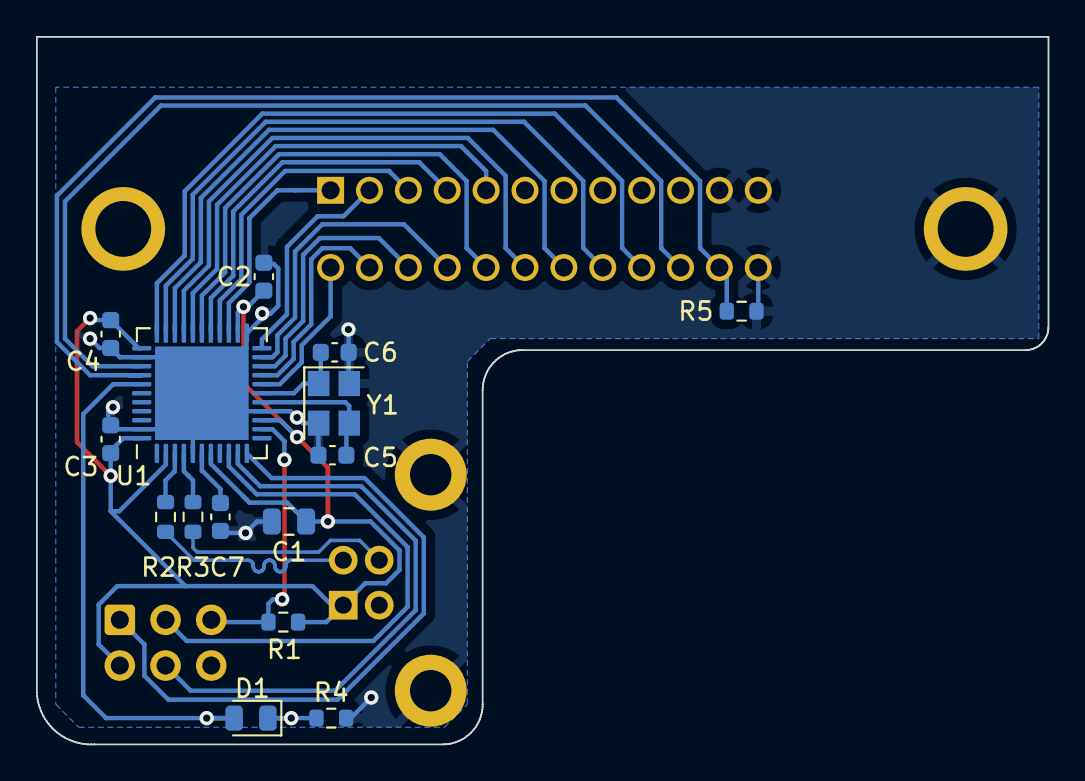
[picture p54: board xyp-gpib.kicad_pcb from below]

Board: 2 copper layers, 56.2 x 39.3 mm, 19 parts (15 on the bottom side), 31 nets.

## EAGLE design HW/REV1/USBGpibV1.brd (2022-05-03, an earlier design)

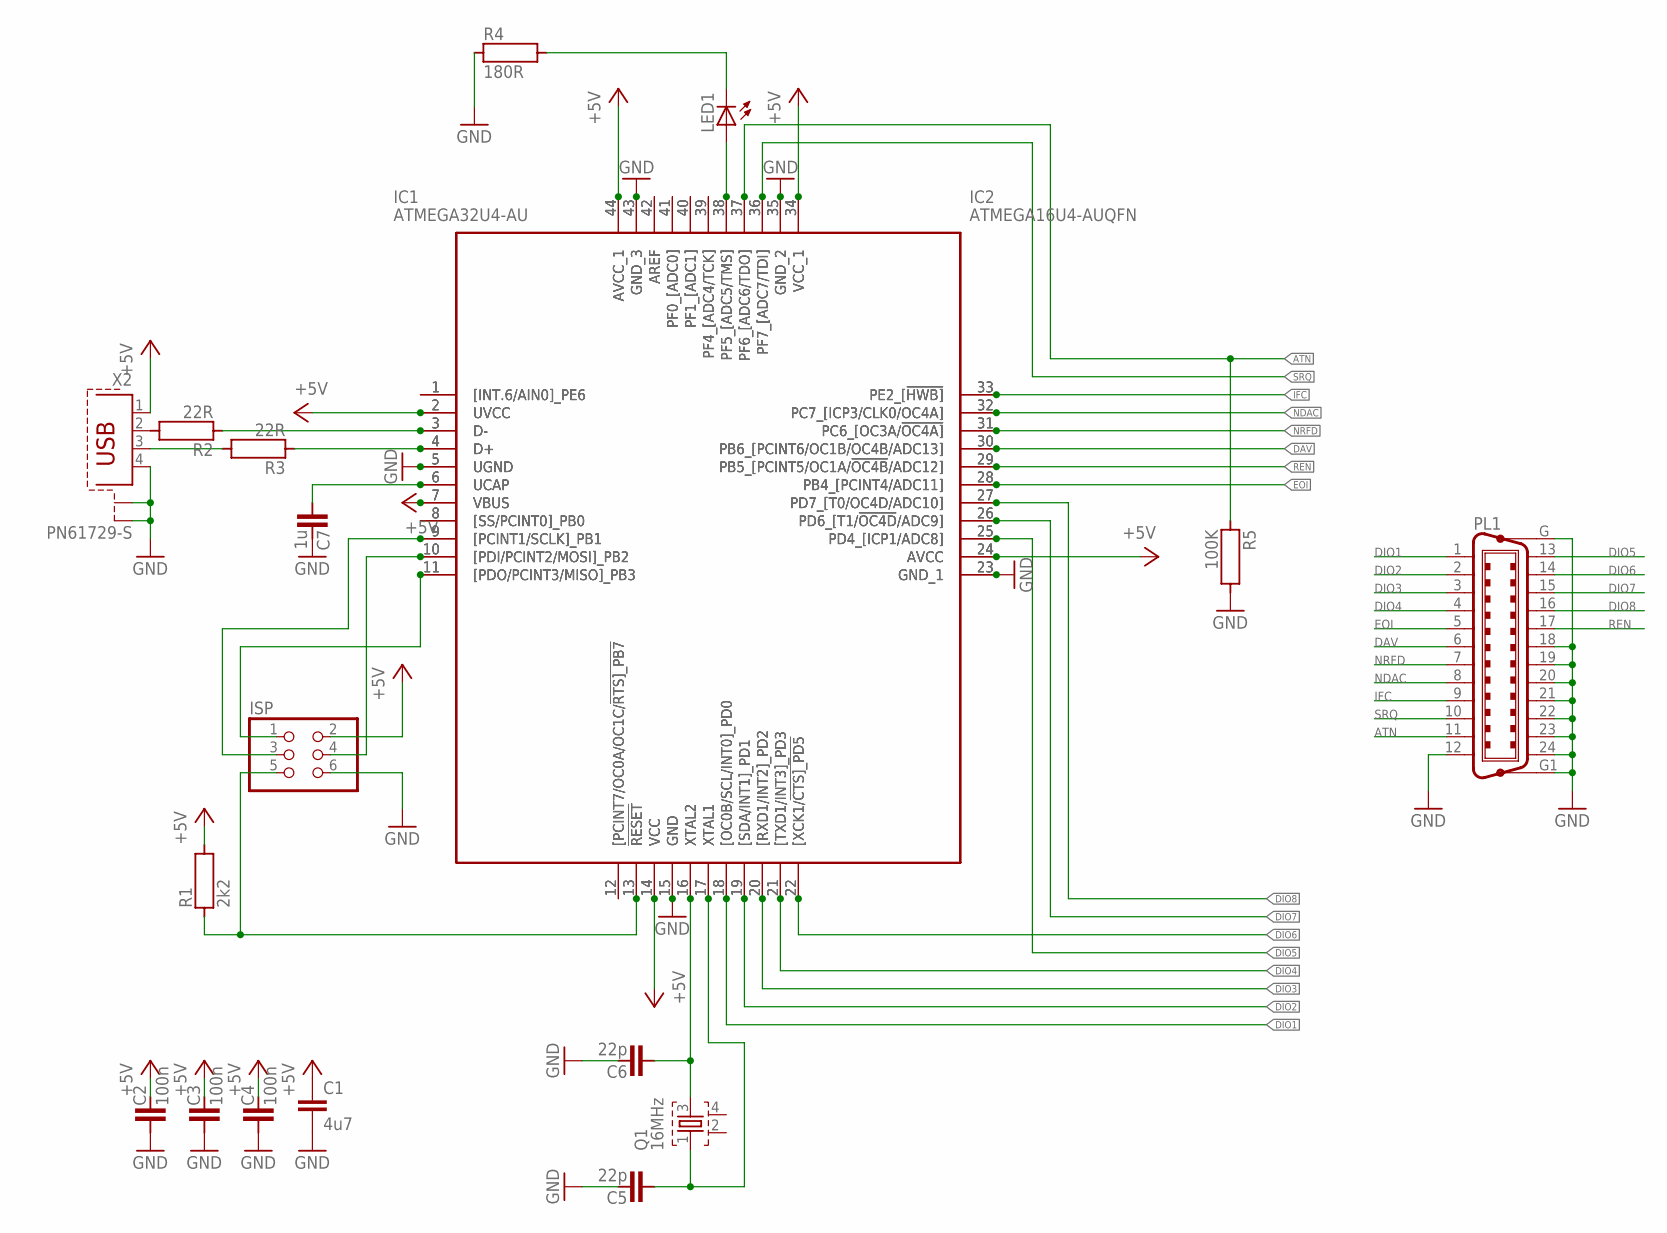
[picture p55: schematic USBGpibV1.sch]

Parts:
C1: 4u7; C1206
C2, C3, C4: 100n; C0603
C5, C6: 22p; C0603
C7: 1u; C0603
IC1: ATMEGA32U4-AU; QFP80P1200X1200X120-44N
IC2: ATMEGA16U4-AUQFN; QFN44
ISP: PINHD-2X3; 2X03
LED1: LEDCHIPLED_1206; CHIPLED_1206
PL1: C24HPMALE; 24HP_MALE
Q1: 16MHz; FA-20H
R1: 2k2; R0603
R2, R3: 22R; R0603
R4: 180R; R0603
R5: 100K; R0603
X2: PN61729-S

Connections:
+5V: C1.1, C2.2, C3.2, C4.2, IC1.2 (UVCC), IC1.7 (VBUS), IC1.14 (VCC), IC1.24 (AVCC), IC1.34 (VCC_1), IC1.44 (AVCC_1), IC2.2 (UVCC), IC2.7 (VBUS), IC2.14 (VCC), IC2.24 (AVCC), IC2.34 (VCC_1), IC2.44 (AVCC_1), ISP.2, R1.2, X2.1
ATN: IC1.37 (PF6_[ADC6/TDO]), IC2.37 (PF6_[ADC6/TDO]), PL1.11, R5.1
DAV: IC1.30 (PB6_[PCINT6/OC1B/OC4B/ADC13]), IC2.30 (PB6_[PCINT6/OC1B/OC4B/ADC13]), PL1.6
DIO1: IC1.18 ([OC0B/SCL/INT0]_PD0), IC2.18 ([OC0B/SCL/INT0]_PD0), PL1.1
DIO2: IC1.19 ([SDA/INT1]_PD1), IC2.19 ([SDA/INT1]_PD1), PL1.2
DIO3: IC1.20 ([RXD1/INT2]_PD2), IC2.20 ([RXD1/INT2]_PD2), PL1.3
DIO4: IC1.21 ([TXD1/INT3]_PD3), IC2.21 ([TXD1/INT3]_PD3), PL1.4
DIO5: IC1.25 (PD4_[ICP1/ADC8]), IC2.25 (PD4_[ICP1/ADC8]), PL1.13
DIO6: IC1.22 ([XCK1/!CTS]_PD5), IC2.22 ([XCK1/!CTS]_PD5), PL1.14
DIO7: IC1.26 (PD6_[T1/!OC4D!/ADC9]), IC2.26 (PD6_[T1/!OC4D!/ADC9]), PL1.15
DIO8: IC1.27 (PD7_[T0/OC4D/ADC10]), IC2.27 (PD7_[T0/OC4D/ADC10]), PL1.16
EOI: IC1.28 (PB4_[PCINT4/ADC11]), IC2.28 (PB4_[PCINT4/ADC11]), PL1.5
GND: C1.2, C2.1, C3.1, C4.1, C5.2, C6.2, C7.2, IC1.5 (UGND), IC1.15 (GND), IC1.23 (GND_1), IC1.35 (GND_2), IC1.43 (GND_3), IC2.5 (UGND), IC2.15 (GND), IC2.23 (GND_1), IC2.35 (GND_2), IC2.43 (GND_3), ISP.6, PL1.12, PL1.18, PL1.19, PL1.20, PL1.21, PL1.22, PL1.23, PL1.24, PL1.G, PL1.G1, R4.1, R5.2, X2.4, X2.S1, X2.S2
IFC: IC1.33 (PE2_[!HWB]), IC2.33 (PE2_[!HWB]), PL1.9
unnamed: C6.1, IC1.16 (XTAL2), IC2.16 (XTAL2), Q1.3
unnamed: C5.1, IC1.17 (XTAL1), IC2.17 (XTAL1), Q1.1
unnamed: C7.1, IC1.6 (UCAP), IC2.6 (UCAP)
unnamed: R2.2, X2.2
unnamed: IC1.3 (D-), IC2.3 (D-), R2.1
unnamed: IC1.4 (D+), IC2.4 (D+), R3.1
unnamed: R3.2, X2.3
unnamed: IC1.13 (!RESET), IC2.13 (!RESET), ISP.5, R1.1
unnamed: LED1.C, R4.2
unnamed: IC1.10 ([PDI/PCINT2/MOSI]_PB2), IC2.10 ([PDI/PCINT2/MOSI]_PB2), ISP.4
unnamed: IC1.9 ([PCINT1/SCLK]_PB1), IC2.9 ([PCINT1/SCLK]_PB1), ISP.3
unnamed: IC1.11 ([PDO/PCINT3/MISO]_PB3), IC2.11 ([PDO/PCINT3/MISO]_PB3), ISP.1
unnamed: IC1.38 (PF5_[ADC5/TMS]), IC2.38 (PF5_[ADC5/TMS]), LED1.A
unnamed: IC1.1 ([INT.6/AIN0]_PE6), IC2.1 ([INT.6/AIN0]_PE6)
unnamed: IC1.8 ([SS/PCINT0]_PB0), IC2.8 ([SS/PCINT0]_PB0)
unnamed: IC1.12 ([PCINT7/OC0A/OC1C/!RTS]_PB7), IC2.12 ([PCINT7/OC0A/OC1C/!RTS]_PB7)
unnamed: IC1.42 (AREF), IC2.42 (AREF)
unnamed: IC1.41 (PF0_[ADC0]), IC2.41 (PF0_[ADC0])
unnamed: IC1.40 (PF1_[ADC1]), IC2.40 (PF1_[ADC1])
unnamed: IC1.39 (PF4_[ADC4/TCK]), IC2.39 (PF4_[ADC4/TCK])
NDAC: IC1.32 (PC7_[ICP3/CLK0/OC4A]), IC2.32 (PC7_[ICP3/CLK0/OC4A]), PL1.8
NRFD: IC1.31 (PC6_[OC3A/!OC4A]), IC2.31 (PC6_[OC3A/!OC4A]), PL1.7
REN: IC1.29 (PB5_[PCINT5/OC1A/!OC4B!/ADC12]), IC2.29 (PB5_[PCINT5/OC1A/!OC4B!/ADC12]), PL1.17
SRQ: IC1.36 (PF7_[ADC7/TDI]), IC2.36 (PF7_[ADC7/TDI]), PL1.10

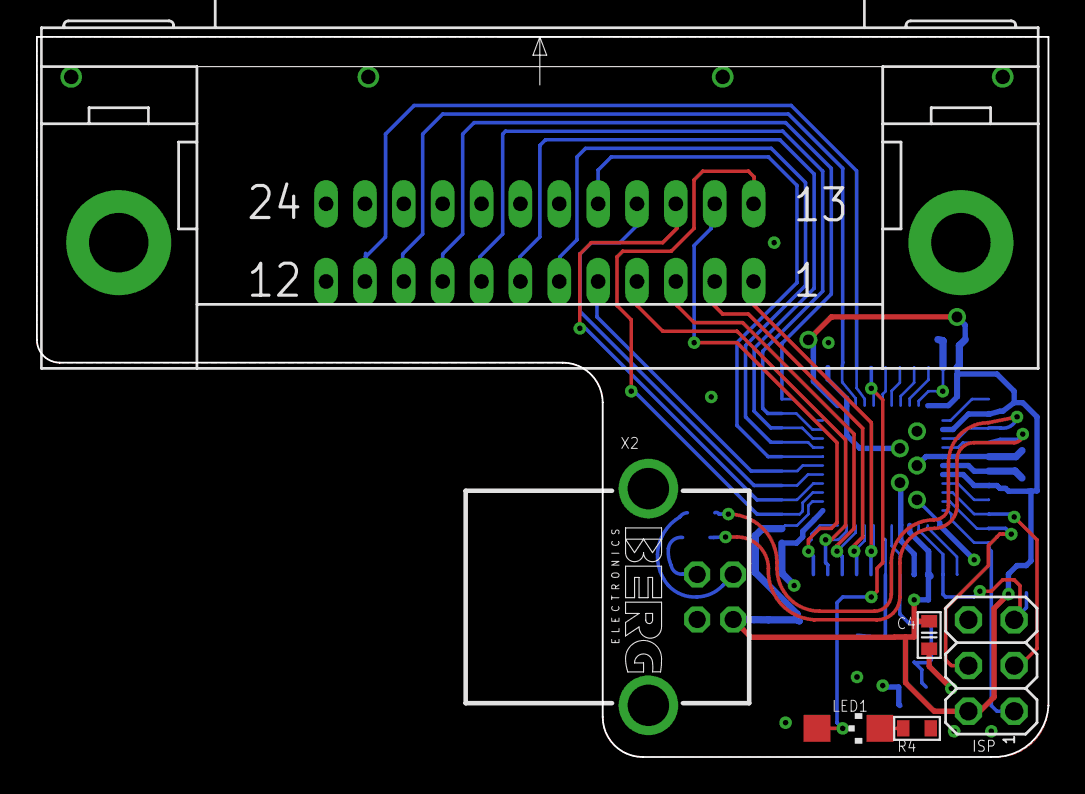
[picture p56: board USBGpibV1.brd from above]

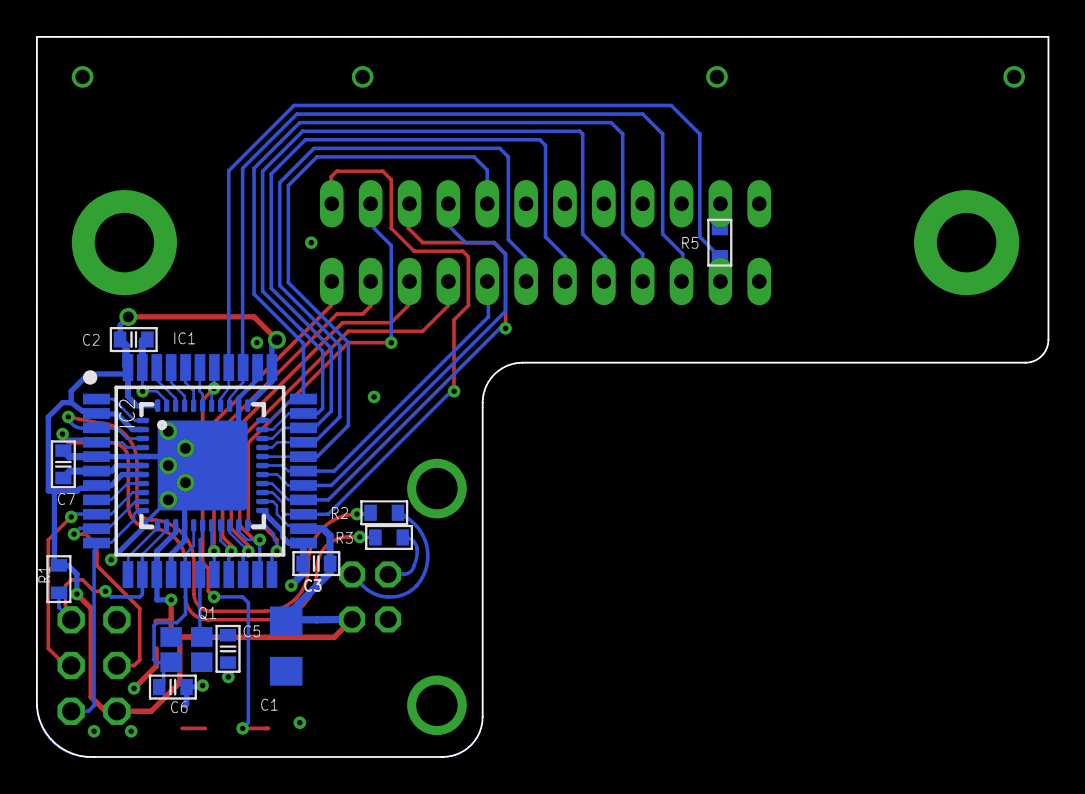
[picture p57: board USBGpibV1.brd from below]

Board: 2 copper layers, 56.2 x 40.0 mm, 19 parts (13 on the bottom side), 38 nets.

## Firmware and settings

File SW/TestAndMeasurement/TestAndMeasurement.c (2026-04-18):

/*
             LUFA Library
     Copyright (C) Dean Camera, 2019.

  dean [at] fourwalledcubicle [dot] com
           www.lufa-lib.org
*/

/*
  Copyright 2019  Dean Camera (dean [at] fourwalledcubicle [dot] com)

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
  The author disclaims all warranties with regard to this
  software, including all implied warranties of merchantability
  and fitness.  In no event shall the author be liable for any
  special, indirect or consequential damages or any damages
  whatsoever resulting from loss of use, data or profits, whether
  in an action of contract, negligence or other tortious action,
  arising out of or in connection with the use or performance of
  this software.
*/

#include "TestAndMeasurement.h"
#include "gpib.h"
#include <avr/eeprom.h>
#include "global.h"
#include "miniparser.h"

#define LED(s) {if(s) PORTF |= (1<<5); else PORTF &= ~(1<<5);}

static inline void TMC_Task(void);

/** Contains the (usually static) capabilities of the TMC device. This table is requested by the
 *  host upon enumeration to give it information on what features of the Test and Measurement USB
 *  Class the device supports.
 */
TMC_Capabilities_t Capabilities =
	{
		.Status     = TMC_STATUS_SUCCESS,
		.TMCVersion = VERSION_BCD(1,0,0),

		.Interface  =
			{
				.ListenOnly             = false,
				.TalkOnly               = false,
				.PulseIndicateSupported = true,
				.Reserved				= 0,
			},

		.Device     =
			{
				.SupportsAbortINOnMatch = true, // was false before version 2.0
				.Reserved = 0,
			},
		.Reserved2 = {0, 0, 0, 0, 0, 0},
		.bcdUSB488 = VERSION_BCD(1,0,0),
		.USB488IfCap1 =
			{
				.SupportTrigger         = 1, //0
				.SupportRenControl      = 1,
				.Is488IF                = 1, // was:0
				.Reserved				= 0,
			},
		.USB488IfCap2 = // device capabilities
			{
				.DT1Capable                 = 1,//0 => Device trigger no capability / full capability
				.RL1Capable					= 1,//0 => Remote Local   no capability / full capability
				.SR1Capable					= 1,//0 => service request 
				.MandatorySCPI				= 0,//0
				.Reserved					= 0,//0
			},
		.Reserved3 = {0, 0, 0, 0, 0, 0, 0, 0},
	};

/** Current TMC control request that is being processed */
static uint8_t RequestInProgress = 0;

/** Stream callback abort flag for bulk IN data */
static bool IsTMCBulkINReset = false;

/** Stream callback abort flag for bulk OUT data */
static bool IsTMCBulkOUTReset = false;

/** Flag that a selective device clear should be executed */
static bool handleSDC = false;

/** Flag that a local lockout should be executed */
static bool handleLocalLockout = false;

/** Flag that a goto local should be executed */
static bool handleGoToLocal = false;

/** Flag that a REN state countrol should be executed */
static uint8_t handleRenControl = 0;

/** Flag that a ReadStatusByte should be executed */
static bool    handleReadStatusByte = false;
static uint8_t handleReadStatusByte_btagvalue = 0;

/** Flag that a status byte should be read */
static bool handleRSTB = false;
static uint8_t RSTB_btag;
static uint8_t RSTB_status;

/** a global flag to indicate that a gpib write transfer triggered via usb is active
  * This is required to solve a prevent read status byte triggered by control transfers to
  * result in unsynchronized GPIB transfers.
  */
bool gpib_write_is_busy = false;

/** Last used tag value for data transfers */
static uint8_t CurrentTransferTag = 0;

/** Length of last data transfer, for reporting to the host in case an in-progress transfer is aborted */
static uint16_t LastTransferLength = 0;

/** This will be set true after a indicator pulse command is received. If the next GPIB command starts with '!', a parameter has to be set */
static bool s_nextwrite_mightbeparameterset = false;

static volatile uint8_t s_pulse_indicator = 0;

static uint32_t s_remaining_bytes_receive=0;

uint8_t gpib_addr = 1;

/** This readbuffer is used to buffer GPIB read data.
 *  As the message header in USBTMC indicates how much data is read and the instrument
 *  does not tell us over GPIB how much data it is, we have to buffer it in ram
 *  if the data transfer over USB should be efficient.
 * The size is decreased by 12 because this is the TMC header length for the first Bulk packate.
 * It is not necessary to substract it, but it does not make sense performance wise.
 */
static uint8_t readbuffer[1024 - 12];

/**
 * When SRQ is asserted the status byte is automatically read and transfered as interrupt transfer to Host.
 * However, the Host Visa might not have events enabled and then a status byte can be lost.
 * The Visa will for that reason issue normally after that interrupt transfer a control in transfer to read
 * the status byte again. Or this is issued manually by the application.
 * The below byte is ored during control transfer to the status byte and then cleared after read to ensure
 * that no data is lost.
 */
static uint8_t srq_statusbyte = 0x00;


static volatile bool transfer_busy = false;

/*
#define FLASH_SIZE_BYTES         32768
#define BOOTLOADER_SEC_SIZE_BYTES  4096

uint32_t Boot_Key ATTR_NO_INIT;
#define MAGIC_BOOT_KEY            0xDC42ACCA
#define BOOTLOADER_START_ADDRESS  (FLASH_SIZE_BYTES - BOOTLOADER_SEC_SIZE_BYTES)
void Bootloader_Jump_Check(void) ATTR_INIT_SECTION(3);
void Bootloader_Jump_Check(void)
{
    // If the reset source was the bootloader and the key is correct, clear it and jump to the bootloader
    if ((MCUSR & (1 << WDRF)) && (Boot_Key == MAGIC_BOOT_KEY))
    {
        Boot_Key = 0;
        ((void (*)(void))BOOTLOADER_START_ADDRESS)();
    }
}
*/

/* Buffer for responses from internal command queries*/
uint8_t internal_response_buffer_rpos = 0;
uint8_t internal_response_buffer_len = 0;
uint8_t internal_response_buffer[8];

void Jump_To_Bootloader(void)
{
    // If USB is used, detach from the bus and reset it
    USB_Disable();
    
    // Disable all interrupts
    cli();
    
    // Wait two seconds for the USB detachment to register on the host
    Delay_MS(2000);
    
    // Set the bootloader key to the magic value and force a reset
    //Boot_Key = MAGIC_BOOT_KEY;
    wdt_enable(WDTO_250MS);
    Delay_MS(500);
	((void (*)(void))0x7000)();
    for (;;);
}

/** Main program entry point. This routine contains the overall program flow, including initial
 *  setup of all components and the main program loop.
 */

uint32_t cnt=0;

bool tmc_gpib_write_timedout(void)
{
	USB_USBTask();
	return IsTMCBulkOUTReset | IsTMCBulkINReset;
}

bool tmc_gpib_read_timedout(void)
{
	USB_USBTask(); /* it is safe to handle the gpib read timeout during usb read transfers - readstatusbyte cannot cause a race condition here */
	return IsTMCBulkINReset | IsTMCBulkOUTReset;
}



uint32_t timeout_val;

void timeout_start(uint32_t timeout)
{
	timeout_val = timeout;
}

bool is_timedout(void)
{
	_delay_us(10);
	if (timeout_val == 0)
		return true;
		
	timeout_val--;
	return false;
}

static void TMC_SetInternalSerial(bool addGPIBAddress);

/* returns TRUE only if a GPIB device responses to any GPIB address */
bool findGpibdevice(void)
{
	uint8_t addr;
	bool devicepresent;
	
	//gpib_interface_clear();
	
	devicepresent = false;
	addr = gpib_search();
	devicepresent = (addr < 255);
	if (addr >= 255)	/* fallback to GPIB address 1, if no device was found */
		addr = 1;
	gpib_addr = addr; /* set global GPIB address to found address*/
	
	return devicepresent;
}

/* returns TRUE, if a string was received over GPIB */
bool identifyGpibDevice(void)
{
	uint8_t c, len, hascomma;
	bool    eoi, timedout;
	bool    gotStringViaGPIB;
	
	gotStringViaGPIB = true;
	
	hascomma = false; /* does the response contain a , character? */

	tmc_serial_string.Header.Size = 0;

	timeout_start(100000); /* 1s timeout*/
	gpib_make_listener(gpib_addr, is_timedout);
	if (timeout_val != 0) gpib_writedat('*', false, is_timedout);
	if (timeout_val != 0) gpib_writedat('I', false, is_timedout);
	if (timeout_val != 0) gpib_writedat('D', false, is_timedout);
	if (timeout_val != 0) gpib_writedat('N', false, is_timedout);
	if (timeout_val != 0) gpib_writedat('?', false, is_timedout);
	if (timeout_val != 0) gpib_writedat('\n', true, is_timedout);
	gpib_untalk_unlisten(is_timedout);
	
	if (timeout_val != 0) 
	{
		char prev_c = '\0';
		bool suppress_character = false;
		timeout_start(100000); /* 1s timeout*/
		gpib_make_talker(gpib_addr, is_timedout);
		len = 0;
		do
		{
			c = gpib_readdat(&eoi, &timedout, is_timedout);
			hascomma = hascomma || (c == ',');
			if ( (c=='\"') || (c=='*') || (c=='/') || (c=='\\') || (c==':') || (c=='?') || (c==' ') || (c==',') || (c=='&') || (c=='_') ) /* YEP, a comma and amphersand is allowed in USBTMC spec, but R&S SW does not like this... */
			{
				suppress_character = (prev_c == '_'); // Issue report from Sebastian by mail. Keysight Visa does not support double underscores (even though it is OK according to USBTMC spec)
				c='_'; 
			}
			if ( (c >=32) && (c <=126) && (!suppress_character) )
				tmc_serial_string.UnicodeString[len++] = cpu_to_le16(c);
			suppress_character = false;
			prev_c = c;
		}
		while ((len < TMC_MAX_SERIAL_STRING_LENGTH) && (!timedout) && (!eoi));
		/* strip away spaces at end */
		while ((tmc_serial_string.UnicodeString[len-1] == '_') && (len > 1))
			len--;
		tmc_serial_string.Header.Size = len*2 + sizeof(USB_Descriptor_Header_t);
		
		gpib_untalk_unlisten(is_timedout);
		
		if ( (timeout_val == 0) || (len==0) ) /* no response to *IDN? string*/
		{ /* so try out ID? query */
			timeout_start(100000); /* 1s timeout*/
			gpib_make_listener(gpib_addr, is_timedout);
			if (timeout_val != 0) gpib_writedat('I', false, is_timedout);
			if (timeout_val != 0) gpib_writedat('D', false, is_timedout);
			if (timeout_val != 0) gpib_writedat('?', false, is_timedout);
			if (timeout_val != 0) gpib_writedat('\n', true, is_timedout);
			gpib_untalk_unlisten(is_timedout);
			if (timeout_val != 0) 
			{
				timeout_start(100000); /* 1s timeout*/
				gpib_make_talker(gpib_addr, is_timedout);
				len = 0;
				do
				{
					c = gpib_readdat(&eoi, &timedout, is_timedout);
					hascomma = hascomma || (c == ',');
					if ( (c=='\"') || (c=='*') || (c=='/') || (c=='\\') || (c==':') || (c=='?') || (c==' ') || (c==',') || (c=='&'))
						c='_';
					if ( (c >=32) && (c <=126) )
						tmc_serial_string.UnicodeString[len++] = cpu_to_le16(c);
				}
				while ((len < TMC_MAX_SERIAL_STRING_LENGTH) && (!timedout) && (!eoi) && (c != '\r') && (c != '\n'));
				/* strip away spaces at end */
				while ((tmc_serial_string.UnicodeString[len-1] == '_') && (len > 1))
					len--;
				tmc_serial_string.Header.Size = len*2 + sizeof(USB_Descriptor_Header_t);
				gpib_untalk_unlisten(is_timedout);
			}				
		}
		
		
		if (!hascomma)
			if ( (tmc_serial_string.UnicodeString[0] == 'H') &&
				 (tmc_serial_string.UnicodeString[1] == 'P') &&
				 (tmc_serial_string.UnicodeString[2] >= '0') &&
				 (tmc_serial_string.UnicodeString[2] <= '9')     )
			{
				hascomma = true;
			}
		
		
		if ((timeout_val == 0) || (len == 0)  || (!hascomma) ) /* timeout happened or length is 0 => build a serial number based on GPIB address */
		{
			TMC_SetInternalSerial(true);
			gotStringViaGPIB = false;
		}
	}
	else
	{ /* no gpib address found => use normal serial number */
		TMC_SetInternalSerial(true);
		gotStringViaGPIB = false;
	}
	
	//TMC_SetInternalSerial(false);
	
	gpib_ren(false);
	_delay_ms(100);
	gpib_ren(true);
	return gotStringViaGPIB;
}




static void TMC_SetInternalSerial(bool addGPIBAddress)
{
	uint_reg_t CurrentGlobalInt = GetGlobalInterruptMask();
	uint8_t    len;
	GlobalInterruptDisable();

	uint8_t SigReadAddress = 0x0E;
	tmc_serial_string.Header.Type = DTYPE_String;

	len = 0;
	if (addGPIBAddress)
	{	
		tmc_serial_string.UnicodeString[len++] = cpu_to_le16('G');
		tmc_serial_string.UnicodeString[len++] = cpu_to_le16('P');
		tmc_serial_string.UnicodeString[len++] = cpu_to_le16('I');
		tmc_serial_string.UnicodeString[len++] = cpu_to_le16('B');
		tmc_serial_string.UnicodeString[len++] = cpu_to_le16('_');
		tmc_serial_string.UnicodeString[len++] = cpu_to_le16('0' + (gpib_addr/10));
		tmc_serial_string.UnicodeString[len++] = cpu_to_le16('0' + (gpib_addr%10));
		tmc_serial_string.UnicodeString[len++] = cpu_to_le16('_');
	}
	for (uint8_t SerialCharNum = 0; SerialCharNum < (80 / 4); SerialCharNum++)
	{
		uint8_t SerialByte = boot_signature_byte_get(SigReadAddress);

		if (SerialCharNum & 0x01)
		{
			SerialByte >>= 4;
			SigReadAddress++;
		}

		SerialByte &= 0x0F;

		tmc_serial_string.UnicodeString[len++] = cpu_to_le16( (SerialByte >= 10) ?
												                        (('A' - 10) + SerialByte) : ('0' + SerialByte) );
	}
	tmc_serial_string.Header.Size = len*2 + sizeof(USB_Descriptor_Header_t);

	SetGlobalInterruptMask(CurrentGlobalInt);
}

static inline void check_bootloaderEntry(void)
{
	if ( !(PINB & (1<<2)) ) /* check if PB2 is LOW*/
	{
		Jump_To_Bootloader();
	}
}

void eeprom_update_if_changed(uint16_t addr, uint8_t value)
{
	uint8_t oldval;
	eeprom_busy_wait();
	oldval = eeprom_read_byte((uint8_t*)addr); /* read previous gpib address */
	if (oldval != value)
	{
		eeprom_busy_wait();
		eeprom_write_byte((uint8_t*)addr, value);		
	}
}

int main(void)
{
	uint8_t prevaddr;

	//mcusr_mirror = MCUSR; 
	MCUSR = 0; 
	wdt_disable(); 
	
	PORTB |=  (1<<2); /* PB2 = PULLUP */
	DDRB  &= ~(1<<2); /* PB2 = input*/
	
	SetupHardware();
	
	gpib_init();
	
	/* apply termination settings from eeprom. The eeprom supports CR+EOI, LF+EOI and EOI only and no other ones. 
	   To change the termination to other ones use the standard USBTMC method to define read termination (see Github doc)
	 */
	eeprom_busy_wait();	
	uint8_t eep_readterm_char = eeprom_read_byte((const uint8_t *)105);
	if ((eep_readterm_char == '\n') || (eep_readterm_char == '\r'))
	{
		gpib_set_readtermination(eep_readterm_char);
		gpib_enable_readterminator(true);
	}
	else
	{
		gpib_enable_readterminator(false);
	}
	
	GlobalInterruptEnable();
	
	while (!gpib_is_connected())
	{
		_delay_ms(250);
		LED(1);
		_delay_ms(250);
		LED(0);
		check_bootloaderEntry();
	}
	
	uint8_t autoid = eeprom_read_byte((const uint8_t *)104);
	if ( (autoid >= 0x02) && (autoid <= 0x04) ) // check if SLOW AUTOID mode is activated
	{ // yes, it is active, so wait 10 seconds
		uint8_t seconds;
		seconds = 5;
		if (autoid == 0x03)
			seconds = 15;
		if (autoid == 0x04)
			seconds = 30;
		for (uint8_t i=0; i<seconds; i++)
		{
			Delay_MS(1000);
		}
	}
	
	/* physically GPIB is connected, now check if any GPIB address is responsive */
#ifndef SPEEDTEST_DUMMY_DEVICE
	while (!findGpibdevice())
	{
		_delay_ms(100);
		LED(1);
		_delay_ms(1000);
		LED(0);
		if (!gpib_is_connected()) /* we want to reset here if the device is unplugged */
		{
			LED(0);	
			
			_delay_ms(500);
			wdt_enable(WDTO_250MS);	
			while (1);
		}
		check_bootloaderEntry();
	}; /* Identify the GPIB Address of the connected GPIB device */
#endif
	eeprom_busy_wait();
#ifdef SPEEDTEST_DUMMY_DEVICE	
	if ( false )
#else
	if (autoid != 0x01) // check if AUTOID feature is enabled
#endif
	{
		/* found a responsive GPIB address, now setup USB descriptor with *IDN? or ID? command response */
		eeprom_busy_wait();
		prevaddr = eeprom_read_byte((uint8_t*)0); /* read previous gpib address */
		if (identifyGpibDevice())
		{ /* received a string over GPIB => Store it in EEPROM, if it changed */
			uint8_t *pdat, i;
			
			/* update gpib address and usb string descriptor in eeprom */
			eeprom_update_if_changed(0, gpib_addr);
			pdat = (void *)&tmc_serial_string;
			for (i=0; i<sizeof(tmc_serial_string); i++)
			{
				eeprom_update_if_changed(1+i, *pdat++);
			}
		}
		else
		{ /* received NO string over GPIB => Check, if the GPIB addr matches the one in eeprom, then report EEProm string! */
			if (prevaddr == gpib_addr)
			{
				uint8_t *pdat, i;

				/* update gpib address and usb string descriptor in eeprom */
				pdat = (void *)&tmc_serial_string;
				for (i=0; i<sizeof(tmc_serial_string); i++)
				{
					*pdat++ = eeprom_read_byte((uint8_t*)(1+i));
				}			
				
			}
		}
	}
	else /* user disabled fully automated detection mode */
	{
		TMC_SetInternalSerial(true);
		gpib_ren(false);
		_delay_ms(100);
		gpib_ren(true);
	}
	
	/* if activated: shorten the USB serial number string. This is just for Matlab which does not allow ressource strings to be longer than */
	if (eeprom_read_byte((const uint8_t *)106) == 0x01) // check if serial string shortening is on
	{
		uint16_t len;
		
		len = (tmc_serial_string.Header.Size - sizeof(USB_Descriptor_Header_t)) >> 1;
		if (len > 20)
		{
			len = 20;
			tmc_serial_string.Header.Size = len*2 + sizeof(USB_Descriptor_Header_t);
		}
	}

	/* all fine, now kickoff connect to USB to be able to communicate! */
	LED(1);
	USB_Attach();
	
	s_pulse_indicator = 0;
	uint8_t pulseind_starttime = 0;
	for (;;)
	{
		TMC_Task(); // this task is 9.42us active when nothing is triggered, the rest takes 3.3us
		check_bootloaderEntry();
		
		if (s_pulse_indicator > 0) // asynchronous handling of pulse indicator request LED flashing
		{
			if (s_pulse_indicator == 2)
			{
				pulseind_starttime = timer0_100mscounter;
				LED(0);
				s_pulse_indicator--;
			}
			else if (timer0_100mscounter > (uint8_t)(2 + pulseind_starttime))
			{
				LED(1);
				s_pulse_indicator--;
			}
		}
		
		if (!gpib_is_connected()) /* check, if gpib is disconnected */
		{ /* when we get here, reset the MCU and disconnect from USB ! It will reconnect once plugged in to GPIB again */
			LED(0);
			USB_Detach();
			_delay_ms(500);
			wdt_enable(WDTO_250MS);	
			while (1);
		}
		
		USB_USBTask();
	}
}

/** Configures the board hardware and chip peripherals for the demo's functionality. */
void SetupHardware(void)
{
	/* Disable watchdog if enabled by bootloader/fuses */
	MCUSR &= ~(1 << WDRF);
	wdt_disable();

	/* Disable clock division */
	clock_prescale_set(clock_div_1);
	

	/* Hardware Initialization */
	USB_Init();
	USB_Detach();

	
	/* update the TMC default serial number*/
	TMC_SetInternalSerial(false);
	
	/* LED to output and turn on */
	DDRF |= (1<<5);
	LED(1);
	
}

/** Event handler for the USB_Connect event. This indicates that the device is enumerating via the status LEDs and
 *  starts the library USB task to begin the enumeration and USB management process.
 */
void EVENT_USB_Device_Connect(void)
{
	//LEDs_SetAllLEDs(LEDMASK_USB_ENUMERATING);
}

/** Event handler for the USB_Disconnect event. This indicates that the device is no longer connected to a host via
 *  the status LEDs and stops the USB management and CDC management tasks.
 */
void EVENT_USB_Device_Disconnect(void)
{
	//LEDs_SetAllLEDs(LEDMASK_USB_NOTREADY);
}

/** Event handler for the USB_ConfigurationChanged event. This is fired when the host set the current configuration
 *  of the USB device after enumeration - the device endpoints are configured and the CDC management task started.
 */
void EVENT_USB_Device_ConfigurationChanged(void)
{
	bool ConfigSuccess = true;

	/* Setup TMC In, Out and Notification Endpoints */
	ConfigSuccess &= Endpoint_ConfigureEndpoint(TMC_NOTIFICATION_EPADDR, EP_TYPE_INTERRUPT, TMC_NOTIFICATION_EPSIZE, 1);
	ConfigSuccess &= Endpoint_ConfigureEndpoint(TMC_IN_EPADDR,  EP_TYPE_BULK, TMC_IO_EPSIZE, 2 );
	ConfigSuccess &= Endpoint_ConfigureEndpoint(TMC_OUT_EPADDR, EP_TYPE_BULK, TMC_IO_EPSIZE, 2 );
}

void TMC_resetstates(void);

/** Event handler for the USB_ControlRequest event. This is used to catch and process control requests sent to
 *  the device from the USB host before passing along unhandled control requests to the library for processing
 *  internally.
 */

void handle_control_Req_ReadStatusByte(void)
{
	uint8_t btag, statusReg;
	uint8_t PrevEndpoint = Endpoint_GetCurrentEndpoint();

	Endpoint_SelectEndpoint(ENDPOINT_CONTROLEP);
	btag = handleReadStatusByte_btagvalue;

	gpib_ren(1); /* ensure that remote control is enabled */
	timeout_start(150000); /* 1.5s timeout*/
	statusReg =  gpib_readStatusByte(gpib_addr, is_timedout);
	statusReg |= srq_statusbyte; // or previously read autoread status byte (Visa will issue a read status byte after receiving a SRQ interrupt transfer)
	srq_statusbyte = 0x00; // clear previously read autoread status byte
	
	/* Write the request response byte */
	Endpoint_Write_8(TMC_STATUS_SUCCESS);
	Endpoint_Write_8(btag);
	Endpoint_Write_8(statusReg);
	
	/* prepare interrupt response */
	RSTB_btag = btag;
	RSTB_status = statusReg;
	handleRSTB = true;

	Endpoint_ClearIN();
	Endpoint_ClearStatusStage();
	
	handleReadStatusByte = false; /* no matter what - we can cancel the pending transfer handling */
	Endpoint_SelectEndpoint(PrevEndpoint);
}
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

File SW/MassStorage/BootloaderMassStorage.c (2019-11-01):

/*
             LUFA Library
     Copyright (C) Dean Camera, 2019.

  dean [at] fourwalledcubicle [dot] com
           www.lufa-lib.org
*/

/*
  Copyright 2019  Dean Camera (dean [at] fourwalledcubicle [dot] com)

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
  The author disclaims all warranties with regard to this
  software, including all implied warranties of merchantability
  and fitness.  In no event shall the author be liable for any
  special, indirect or consequential damages or any damages
  whatsoever resulting from loss of use, data or profits, whether
  in an action of contract, negligence or other tortious action,
  arising out of or in connection with the use or performance of
  this software.
*/

/** \file
 *
 *  Main source file for the Mass Storage class bootloader. This file contains the complete bootloader logic.
 */

#define  INCLUDE_FROM_BOOTLOADER_MASSSTORAGE_C
#include "BootloaderMassStorage.h"

/** LUFA Mass Storage Class driver interface configuration and state information. This structure is
 *  passed to all Mass Storage Class driver functions, so that multiple instances of the same class
 *  within a device can be differentiated from one another.
 */
USB_ClassInfo_MS_Device_t Disk_MS_Interface =
	{
		.Config =
			{
				.InterfaceNumber           = INTERFACE_ID_MassStorage,
				.DataINEndpoint            =
					{
						.Address           = MASS_STORAGE_IN_EPADDR,
						.Size              = MASS_STORAGE_IO_EPSIZE,
						.Banks             = 1,
					},
				.DataOUTEndpoint           =
					{
						.Address           = MASS_STORAGE_OUT_EPADDR,
						.Size              = MASS_STORAGE_IO_EPSIZE,
						.Banks             = 1,
					},
				.TotalLUNs                 = 1,
			},
	};

/** Flag to indicate if the bootloader should be running, or should exit and allow the application code to run
 *  via a soft reset. When cleared, the bootloader will abort, the USB interface will shut down and the application
 *  started via a forced watchdog reset.
 */
bool RunBootloader = true;

/** Magic lock for forced application start. If the HWBE fuse is programmed and BOOTRST is unprogrammed, the bootloader
 *  will start if the /HWB line of the AVR is held low and the system is reset. However, if the /HWB line is still held
 *  low when the application attempts to start via a watchdog reset, the bootloader will re-start. If set to the value
 *  \ref MAGIC_BOOT_KEY the special init function \ref Application_Jump_Check() will force the application to start.
 */
uint16_t MagicBootKey ATTR_NO_INIT;

/** Indicates if the bootloader is allowed to exit immediately if \ref RunBootloader is \c false. During shutdown all
 *  pending commands must be processed before jumping to the user-application, thus this tracks the main program loop
 *  iterations since a SCSI command from the host was received.
 */
static uint8_t TicksSinceLastCommand = 0;


/** Special startup routine to check if the bootloader was started via a watchdog reset, and if the magic application
 *  start key has been loaded into \ref MagicBootKey. If the bootloader started via the watchdog and the key is valid,
 *  this will force the user application to start via a software jump.
 */
void Application_Jump_Check(void)
{
	bool JumpToApplication = false;
	
	/* Turn off the watchdog */
	MCUSR &= ~(1 << WDRF);
	wdt_disable();	

	#if (BOARD == BOARD_LEONARDO)
		/* Enable pull-up on the IO13 pin so we can use it to select the mode */
		PORTC |= (1 << 7);
		Delay_MS(10);

		/* If IO13 is not jumpered to ground, start the user application instead */
		JumpToApplication = ((PINC & (1 << 7)) != 0);

		/* Disable pull-up after the check has completed */
		PORTC &= ~(1 << 7);
	#elif ((BOARD == BOARD_XPLAIN) || (BOARD == BOARD_XPLAIN_REV1))
		/* Disable JTAG debugging */
		JTAG_DISABLE();

		/* Enable pull-up on the JTAG TCK pin so we can use it to select the mode */
		PORTF |= (1 << 4);
		Delay_MS(10);

		/* If the TCK pin is not jumpered to ground, start the user application instead */
		JumpToApplication = ((PINF & (1 << 4)) != 0);

		/* Re-enable JTAG debugging */
		JTAG_ENABLE();
	#else
		/* Check if the device's BOOTRST fuse is set */
		if (!(BootloaderAPI_ReadFuse(GET_HIGH_FUSE_BITS) & ~FUSE_BOOTRST))
		{
			/* If the reset source was not an external reset or the key is correct, clear it and jump to the application */
			if (!(MCUSR & (1 << EXTRF)) || (MagicBootKey == MAGIC_BOOT_KEY))
			  JumpToApplication = true;

			/* Clear reset source */
			MCUSR &= ~(1 << EXTRF);
		}
		else
		{
			/* If the reset source was the bootloader and the key is correct, clear it and jump to the application;
			 * this can happen in the HWBE fuse is set, and the HBE pin is low during the watchdog reset */
			if ((MCUSR & (1 << WDRF)) && (MagicBootKey == MAGIC_BOOT_KEY))
				JumpToApplication = true;

			/* Clear reset source */
			MCUSR &= ~(1 << WDRF);
			JumpToApplication = true;
		}
	#endif
	
JumpToApplication = true;
	
	
	PORTB |=  (1<<2); /* PB2 = PULLUP */
	DDRB  &= ~(1<<2); /* PB2 = input*/
	
	_delay_ms(50); /* let pullup value settle */
	if ( !(PINB & (1<<2)) ) /* check if PB2 is HIGH => Start application! */
	{
		JumpToApplication = false;
	}

	/* Don't run the user application if the reset vector is blank (no app loaded) */
	bool ApplicationValid = (pgm_read_word_near(0) != 0xFFFF);

	/* If a request has been made to jump to the user application, honor it */
	if (JumpToApplication && ApplicationValid)
	{
		/* Turn off the watchdog */
		MCUSR &= ~(1 << WDRF);
		wdt_disable();

		/* Clear the boot key and jump to the user application */
		MagicBootKey = 0;

		// cppcheck-suppress constStatement
		((void (*)(void))0x0000)();
	}
}

/** Main program entry point. This routine configures the hardware required by the application, then
 *  enters a loop to run the application tasks in sequence.
 */
int main(void)
{

	SetupHardware();

	LEDs_SetAllLEDs(LEDMASK_USB_NOTREADY);
	GlobalInterruptEnable();

	while (RunBootloader || TicksSinceLastCommand++ < 0xFF)
	{
		MS_Device_USBTask(&Disk_MS_Interface);
		USB_USBTask();
	}

	/* Wait a short time to end all USB transactions and then disconnect */
	_delay_us(1000);

	/* Disconnect from the host - USB interface will be reset later along with the AVR */
	USB_Detach();

	/* Unlock the forced application start mode of the bootloader if it is restarted */
	MagicBootKey = MAGIC_BOOT_KEY;

	/* Enable the watchdog and force a timeout to reset the AVR */
	wdt_enable(WDTO_250MS);

	for (;;);
}
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

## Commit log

2019-11-01 Initial full project commit
    [USBGpib.brd, USBGpib.sch, USBGpibHousing.f3d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]
2019-11-01 Adding PCB of Gerber files
    [USBGpib.GBL, USBGpib.GBO, USBGpib.GBS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]
2020-04-23 Added PCB with 0603 components iso. 0402
    Added alternative version of PCB with 0603 components intead of the tiny 0402 (thanks @DaviVolcan!)
    [USBGpib_biggercomponents.brd, USBGpib_biggercomponents.sch]
2021-05-08 Adding gerber files for big components variant
    Adding Gerber files for PCB variants with 0603 components (biggercomponents)
    [USBGpib_biggercomponents.GBL, USBGpib_biggercomponents.GBO, USBGpib_biggercomponents.GBP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]
2021-12-24 files for VQFN version of pcb
    [bom.xls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]
2021-12-26 updated to reflect the release of kicad 6.0.
2022-05-03 Add V2 of the design
    This modified HW supports QFN and TQFP IC variants on a single PCB. 0402 components have been changed to 0603 size for easier soldering.
    SW support for AtMega16U4 variant will come soon.
    [USBGpibV2.brd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]
2023-10-17 October 2023 updates
    - 488.2 support is enabled.
    - fixed issue: Linux PCs show that Config 1 descriptor is not correct.
    - Fixed read status byte, Clear and trigger assertion functions.
    - Compatibility with R&S Visa is back - it got broken in a previous version. Read status byte, Clear and trigger did not work properly.
    - I deleted 2 HW variants to avoid confusion. Right now there is one Eagle 6 version (mine) and a user contributed Kicad version included.
    [USBGpib.brd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]
2023-10-30 Fix for Issue report #38
    Fix for Issue #38
    https://github.com/xyphro/UsbGpib/issues/38
    On old FW revision HP34401 multimeter issues occured. The multimeter froze in remote mode and could not be put back to local, the read queries stopped after some time.
    As it turned out, this was related to ATN line timing (which is rather unspecified). Inserting defined delays on ATN line status changes like NI GPIB-USB-HS does fixed the issue reportedly. Thanks Chris for issue report and following strong support!
    [gpib.c]
2023-10-30 outlook
    Added outlook for next HW revision and some notes on the current FW status.
2023-11-04 Improved the printability of the screw holes
    By putting a "thin solid wall", which acts as support when printing the screw hole. This prevents sagging of filament.
    [gipbusb_bot.stl, gipbusb_top.stl]
2023-12-19 Add REV 2 and ReleaseCandidate FW image
    [USBGpibHousing.f3d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]
2023-12-22 Add BOM and CPL file
    [BOM-xyp-gpib.csv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]
2024-01-13 some fixes and full firmware baselining
    - BOM/CPL file: ensure that both R7, R8 have 5K1 value
    - adjusted fuses for programming instructions
    - added Dazz100 suggestion in programming instructions allowing to program bootloader and application image at the same time using AvrDude
    - included sourcecode of current baseline firmware
    - updated firmware: new human readable internal commands realized
    - updated firmware: Fixed issue where after a device clear a query could fail
    - deleted old firmware image to just have a single one in the repository. You can use the Github history in case you want to access an old firmware image
    [BOM-xyp-gpib.csv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]
2024-01-15 Fixing presence detection issue
    Hotfix: Fixing, that the adapter did sometimes not detect that the instrument was powered off. Increased FW version to V1.7
    [TestAndMeasurement.c, gpib.c]
2025-01-11 Updated FW Version and release of first UsbGpib GUI version
    [xyp-gpib.kicad_sch]
2025-02-03 Add Jims nicegui readme.md, confscript, fix some typos, etc.
    [usbgpib_conf.py, usbgpib_gui.py]
2025-04-21 Release of FW version 2.0
    Changes:
    - fix autoid slower and autoid slowest options
    - Implement USBTMC compliant method to set read termination method
    - Made pulse indicator request function work asynchronous
    See README.MD for more details.
    [TestAndMeasurement.c, TestAndMeasurement.h, gpib.c]
2025-11-30 Updaste to firmware Version V2.2
    All 256 termination characters are now possible.
    And 2 further bugfixes.
    -> See 30th November update in updates.md for more details.
    [TestAndMeasurement.c, gpib.c, gpib_priv.h]
2026-02-04 Add Markdown version of the documentation, Update Firmware to version V2.3
    - The PDF versions are still there. Both PDF and Markdown are autogenerated from a single source document for consistency.
    Markdown enables easier linking to information for support, etc. compared the PDF. PDF has the advantage of better readability.
    Furthermore Firmware version got upgraded to V2.3.
    - when using autoid, characters which are not allowed as USBTMC serial number got replaced by underscores. This could end up in situation where 2 underscores follow each other. Keysight Visa crashes when trying to open such a device, even though double underscores are compliant with UsbTmc.
    - Addressed Issues #9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
    [TestAndMeasurement.c]
2026-04-18 Delete BOMV2.html
    to avoid inconsistences! Use BOM-xyp-gpib.csv as source of truth!
